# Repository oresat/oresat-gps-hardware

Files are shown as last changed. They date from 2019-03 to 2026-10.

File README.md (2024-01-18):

# oresat-gps-hardware 

## Overview

This is the repo for our OreSat GPS Card. For software, see the [oresat-gps-software](https://github.com/oresat/oresat-gps-software) repo.

The card has two GPS receivers on it:

* A [**SkyTraq Orion-B16** GNSS module](https://navspark.mybigcommerce.com/12mm-x-16mm-gnss-receiver-module-for-leo-applications/), a GNSS receiver module meant for university CubeSat use.
* An [Analog Devices MAX2771 SDR GNSS receiver IC](https://www.analog.com/en/products/max2771.html) that is read by the [Octavo OSD335x-SM processor's](https://octavosystems.com/octavo_products/osd335x-sm/) PRU and then parsed using the [GNSS-SDR project](https://gnss-sdr.org/) software.

## Status

TRL 6-7 ish. Flown, but not yet demonstrated to work in space.

* v1.1: Assembled, electrical and software test out, Orion not yet locked and demonstrated to work. MAX not yet tested.
* v1.0: Works: SkyTraq confirmed locked on ground. SDR datastream captured, and processed, but this software seems to be lost to the sands of time? Flown on OreSat0 but never turned on due to comms issues with OreSat0.

## License

All materials in this repo are copyright Portland State Aerospace Society and are licensed under the CERN Open Hardware Licence Version 2 -
Strongly Reciprocal (CERN-OHL-S v2), or any later version. A copy of the license is located in [here](LICENSE.md).

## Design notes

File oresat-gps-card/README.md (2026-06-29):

---
title: "**OreSat GPS Card**"
subtitle: |
  **Fabrication and Assembly Information**\
  For build TIME-STAMP
fontsize: 10pt
geometry:
  - margin=0.5in
toc: true
toc-depth: 2
colorlinks: true
urlcolor: blue
---

\newpage

# About this Board

## Board Description

The OreSat GPS Card provides two GPS receivers for the OreSat bus:

1. The SkyTraq Orion B16 which is a COTS GPS receiver capable of lock while in orbit.
2. The MAX2769 SDR GPS receiver. This hardware is for a future SDR capability we'd
like to have, and might one day replace the much more expensive COTS receiver.

## Documentation Links

- GPS hardware Git repository: <https://github.com/oresat/oresat-gps-hardware>
- GPS software Git reposity: <https://github.com/oresat/oresat-gps-software>
- **TODO:** GPS Design Notes + Design Review Notes

## Documentation Files

| Filename | Notes |
| --- | --- |
| README.pdf | This README file |
| PROJECT-NAME-outline.dxf | Board outline (with holes) in DXF format |
| PROJECT-NAME-pcba.step | 3D model of PCBA (with components) |
| PROJECT-NAME-render-bot.jpg | Render of the top of the 3D model |
| PROJECT-NAME-render-bot.jpg | Render of the bottom of the 3D model |
| PROJECT-NAME-schematic.pdf | PDF of board schematics |

## Contact Information

- Website: <https://www.oresat.org/>
- Email: <oresat@pdx.edu>
- Instagram: @pdxaerospace

## Board Renders

Render of the top of the 3D model
Render of the bottom of the 3D model

\newpage

# Printed Circuit Board (PCB) Fabrication Information

## Board Info

- 4 layer board
- Bounding box is 99.8 x 94.6 mm (3.93 x 3.72 in)
- Board thickness is 1.59 mm (0.063 inch)
- **Important:** See Materials and Stack Up sections below

## Board Requirements

- Design Rules
    - Minimum Trace / Space design rules
       - Outer layers: 0.127 mm (5.0 mil) / 0.127 mm (5.0 mil)
       - Inner layers: 0.127 mm (5.0 mil) / 0.127 mm (5.0 mil)
    - Outer dimension router tolerance: +/- 0.254 mm (10.0 mil)
    - Hole placement tolerance: +/- 0.075 mm (3.0 mil)
    - Inner tab routed slot tolerance: +/- 0.254 mm (10.0 mil)
- Drills
   - Drill Positional Tolerance: 0.051 mm (2.0 mil)
   - Drill Size tolerance: +/- 0.064 mm (2.5 mil)
- Plated/Un-plated holes
  - There are 6 un-plated (NPT) holes
  - There are 1477 plated through (PTH) holes
  - PTH minimum diameter: 0.254 mm (10 mil)
  - PTH minimum annulus: 0.102 mm (4 mil) radius
- Outline/Routing
  - Requires a 1.0 mm or smaller diameter routing bit
- Slots
  - There are no slots.
- Cutouts
  - There are no cutouts
- There are 3 fiducials on the top layer.
- Panel tabs ("mouse bites")
   - Card edges must be smooth; no mouse bites or other intrusions into the card outline.
   - If external mouse bites are required, minimize and customer will remove by hand before assembly.
- If not otherwise specified, build to IPC 6012 Class 2 or better.

## Materials

- Controlled impedance
   - The stackup is critical for the performance of high speed signals on this board.
   - As long as the stackup is controlled, the board is not considered controlled impedance.
- Isola FR408HR or material with equivalent Dk.
- Board Surface treatment should be ENIG, althogh immersion Silver is acceptable.
- White silkscreen on top and bottom surface
- Taiyo PSR-4000 or equivalent soldermask on top and bottom, no requirements for color.

## Stack Up

| Layer | Thickness | Notes |
|---|---|---|
| Top Copper | 0.043 mm /  1.7 mil |  Layer 1 foil, 1 oz Cu after plating |
| prepreg | 0.200 mm /  7.9 mil |  Prepreg - Isola FR408HR 2113 |
| Layer 2 | 0.018 mm /  0.7 mil |  Layer 2 foil, 0.5 oz Cu |
| Core | 0.991 mm / 39 mil |  Core Isola FR408HR |
| Layer 3 | 0.018 mm /  0.7 mil |  Layer 3 foil, 0.5 oz Cu |
| prepreg | 0.200 mm /  7.9 mil |  Prepreg - Isola FR408HR 2113 |
| Bottom Copper | 0.043 mm /  1.7 mil |  Layer 4 foil, 1 oz copper after plating |
| **Total Stackup** | **1.588 mm / 62.5 mil** | |

## Array / Panel Information

- Coordinate with Contract Manufacturer (CM) for optimal size of this panel.
- If no feedback from CM, then produce single boards (no panel).

## Fabrication Files

### IPC-2581 File

| Filename | Notes |
| --- | --- |
| PROJECT-NAME-ipc2581.xml | IPC-2581 board information file |

### Legacy PCB Files

| Filename | Notes |
| ---| --- |
| PROJECT-NAME-Edge_Cuts.gbr | RS274X file for the dimension (outline) layer |
| PROJECT-NAME-F_Silkscreen.gbr | RS274X file for the top silkscreen |
| PROJECT-NAME-F_Mask.gbr | RS274X file for the top soldermask |
| PROJECT-NAME-F_Cu.gbr | RS274X file for the top copper layer |
| PROJECT-NAME-In1_Cu.gbr | RS274X file for the layer 2 copper |
| PROJECT-NAME-In2_Cu.gbr | RS274X file for the layer 3 copper |
| PROJECT-NAME-B_Cu.gbr | RS274X file for the bottom copper layer |
| PROJECT-NAME-B_Mask.gbr | RS274X file for the bottom soldermask |
| PROJECT-NAME-B_Silkscreen.gbr | RS274X file for the bottom silkscreen |
| PROJECT-NAME-NPTH.drl | Excellon file for non-plated through holes |
| PROJECT-NAME-PTH.drl | Excellon file for plated through holes | 

\newpage

# Printed Circuit Board Assembly (PCBA) Information

## Assembly Info

- All components are on the top side of the board.
- This PCBA is mostly surface mount (SMT) with a few (THT) components.

## Assembly Requirements

- Assemble to IPC Class 2 or better
- Bake components that are not moisture sealed to appropriate levels as required.
- Solder paste MUST be leaded.
- Aqueous flux and wash strongly preferred.
   - Clean to NASA Standard "Visibly Clean (VC)": No particles or residues are visible to the naked eye.
- No conformal coating.
- Ship in antistatic protective bag

## Component Specific Assembly Information

- SMPM connectors (CM1) should be hand-added (there is no solder paste for their footprints) according to the OreSat SMPM SOP.
- U23 is extremely expensive ($400 ea).

## Assembly Files

### IPC-2581 File

| Filename | Notes |
| --- | --- |
| PROJECT-NAME-ipc2581.xml | IPC-2581 board information file |

### Bill of Materials (BOM)

| Filename | Description |
| --- | --- |
| PROJECT-NAME-bom.csv | BOM in Comma Separated Variable format |

### Solder Paste Stencils

| Filename | Notes |
| --- | --- |
| PROJECT-NAME-B_Paste.gbr | RS274X file for top/front solder paste stencil |
| PROJECT-NAME-F_Paste.gbr | RS274X file for bottom/back solder paste stencil |

### Mounting/Placement Location

| Filename | Description |
| --- | --- |
| PROJECT-NAME-3u.pos | Pick and place locations for components |

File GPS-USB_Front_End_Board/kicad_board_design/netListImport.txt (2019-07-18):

Info: Reading netlist file "/home/hugh/projects/KiCad/usb_gps/usb_gps_fixed.net".

Info: Using references to match components and footprints.

Info: Checking netlist component footprint "C1:/5B1BC185/5B1E7FF3:Capacitors_SMD:C_0603_HandSoldering".

Changing component "C1:/5B1BC185/5B1E7FF3" pin "1" net name from "/USB_FT2232/VCC3V3" to "/MAX_2769/VCC3V3".

Info: Checking netlist component footprint "C2:/5B1BC185/5B1E80A3:Capacitors_SMD:C_0402".

Changing component "C2:/5B1BC185/5B1E80A3" pin "1" net name from "/USB_FT2232/VCC3V3" to "/MAX_2769/VCC3V3".

Info: Checking netlist component footprint "C3:/5B1BC185/5B1C4E8F:Capacitors_SMD:C_0805_HandSoldering".

Info: Checking netlist component footprint "C4:/5B1BC185/5B1E3C76:Capacitors_SMD:C_0805_HandSoldering".

Info: Checking netlist component footprint "C5:/5B1BC185/5B1C4C39:Capacitors_SMD:C_0805_HandSoldering".

Info: Checking netlist component footprint "C6:/5B1BC185/5B1C1DAE:Capacitors_SMD:C_0402".

Info: Checking netlist component footprint "C7:/5B1BC185/5B5B2330:Capacitors_SMD:C_0805_HandSoldering".

Info: Changing component path "C7:/5B1BC185/5B1C1E88" to "/5B1BC185/5B5B2330".

Changing component "C7:/5B1BC185/5B1C1E88" pin "1" net name from "/USB_FT2232/VCC3V3" to "/MAX_2769/VCC3V3".

Info: Checking netlist component footprint "C8:/5B1BC185/5B1BDC6D:Capacitors_SMD:C_0402".

Info: Checking netlist component footprint "C9:/5B1BC185/5B5D53D2:Capacitors_SMD:C_0402".

xReplacing component "C9:/5B22247E/5B231F00" footprint "Capacitors_SMD:C_0805_HandSoldering" with "Capacitors_SMD:C_0402".

xChanging component "C9:/5B22247E/5B231F00" value from "NC" to "100 nF".

Info: Changing component path "C9:/5B22247E/5B231F00" to "/5B1BC185/5B5D53D2".

Changing component "C9:/5B22247E/5B231F00" pin "1" net name from "Net-(C12-Pad1)" to "Net-(C9-Pad1)".

Info: Checking netlist component footprint "C10:/5B1BC185/5B5D5EEA:Capacitors_SMD:C_0402".

xxx0603xReplacing component "C10:/5B22247E/5B231FC9" footprint "Capacitors_SMD:C_0805_HandSoldering" with "Capacitors_SMD:C_0402".

Changing component "C10:/5B22247E/5B231FC9" value from "NC" to "10uF".

Info: Changing component path "C10:/5B22247E/5B231FC9" to "/5B1BC185/5B5D5EEA".

Changing component "C10:/5B22247E/5B231FC9" pin "1" net name from "/MAX_2769/VCC3V" to "/MAX_2769/+5V".

Info: Checking netlist component footprint "C11:/5B22247E/5B222A24:Capacitors_SMD:C_0402".

Info: Checking netlist component footprint "C12:/5B22247E/5B5E057D:Capacitors_SMD:C_0603_HandSoldering".

xChanging component "C12:/5B22247E/5B23227F" value from "33pF" to "1uF".

Info: Changing component path "C12:/5B22247E/5B23227F" to "/5B22247E/5B5E057D".

Changing component "C12:/5B22247E/5B23227F" pin "1" net name from "Net-(C12-Pad1)" to "/MAX_2769/+5V".

Changing component "C12:/5B22247E/5B23227F" pin "2" net name from "Net-(C12-Pad2)" to "GND".

Info: Checking netlist component footprint "C13:/5B22247E/5B222C2B:Capacitors_SMD:C_0402".

Changing component "C13:/5B22247E/5B222C2B" pin "1" net name from "/MAX_2769/VCC3V" to "/MAX_2769/VCCA".

Info: Checking netlist component footprint "C14:/5B22247E/5B222D43:Capacitors_SMD:C_0402".

Changing component "C14:/5B22247E/5B222D43" pin "1" net name from "/MAX_2769/VCC3V" to "/MAX_2769/VCCA".

Info: Checking netlist component footprint "C15:/5B22247E/5B222E30:Capacitors_SMD:C_0402".

Changing component "C15:/5B22247E/5B222E30" pin "1" net name from "/MAX_2769/VCC3V" to "/MAX_2769/VCCD".

Info: Checking netlist component footprint "C16:/5B22247E/5B222E72:Capacitors_SMD:C_0402".

Changing component "C16:/5B22247E/5B222E72" pin "1" net name from "/MAX_2769/VCC3V" to "/MAX_2769/VCCA".

Info: Checking netlist component footprint "C17:/5B22247E/5B5DF4D0:Capacitors_SMD:C_0402".

xxReplacing component "C17:/5B22247E/5B2324F5" footprint "Capacitors_SMD:C_0805_HandSoldering" with "Capacitors_SMD:C_0402".

xxChanging component "C17:/5B22247E/5B2324F5" value from "100pF" to "10nF".

Info: Changing component path "C17:/5B22247E/5B2324F5" to "/5B22247E/5B5DF4D0".

Changing component "C17:/5B22247E/5B2324F5" pin "1" net name from "Net-(C12-Pad2)" to "/MAX_2769/VCCA".

Info: Checking netlist component footprint "C18:/5B22247E/5B2B7313:Capacitors_SMD:C_0603_HandSoldering".

Info: Checking netlist component footprint "C19:/5B22247E/5B222EB0:Capacitors_SMD:C_0805_HandSoldering".

Changing component "C19:/5B22247E/5B222EB0" pin "1" net name from "/MAX_2769/VCC3V" to "/MAX_2769/VCCA".

Info: Checking netlist component footprint "C20:/5B22247E/5B22294B:Capacitors_SMD:C_0603_HandSoldering".

Info: Checking netlist component footprint "C21:/5B22247E/5B222F1B:Capacitors_SMD:C_0402".

Changing component "C21:/5B22247E/5B222F1B" pin "1" net name from "/MAX_2769/VCC3V" to "/MAX_2769/VCCA".

Info: Checking netlist component footprint "C22:/5B22247E/5B222F73:Capacitors_SMD:C_0402".

Changing component "C22:/5B22247E/5B222F73" pin "1" net name from "/MAX_2769/VCC3V" to "/MAX_2769/VCCA".

Info: Checking netlist component footprint "C23:/5B22247E/5B2B743B:Capacitors_SMD:C_0402".

Changing component "C23:/5B22247E/5B2B743B" pin "1" net name from "Net-(C23-Pad1)" to "/MAX_2769/VCCA".

Info: Checking netlist component footprint "C24:/5B22247E/5B5E05AD:Capacitors_SMD:C_0402".

xxReplacing component "C24:/5B22247E/5B2B7595" footprint "Capacitors_SMD:C_0805_HandSoldering" with "Capacitors_SMD:C_0402".

xxChanging component "C24:/5B22247E/5B2B7595" value from "10uF" to "10nF".

Info: Changing component path "C24:/5B22247E/5B2B7595" to "/5B22247E/5B5E05AD".

Changing component "C24:/5B22247E/5B2B7595" pin "1" net name from "/MAX_2769/VCC3V" to "/MAX_2769/VCCD".

Changing component "C24:/5B22247E/5B2B7595" pin "2" net name from "GND" to "Net-(C24-Pad2)".

Info: Checking netlist component footprint "C25:/5B22247E/5B224008:Capacitors_SMD:C_0805_HandSoldering".

Info: Checking netlist component footprint "C26:/5B22247E/5B223F00:Capacitors_SMD:C_0402".

Changing component "C26:/5B22247E/5B223F00" pin "2" net name from "/MAX_2769/CLKOUT" to "Net-(C26-Pad2)".

Info: Checking netlist component footprint "C27:/5B22247E/5B224134:Capacitors_SMD:C_0402".

Info: Checking netlist component footprint "C28:/5B22247E/5B223AF8:Capacitors_SMD:C_0402".

Info: Checking netlist component footprint "C29:/5B22247E/5B23CB0F:Capacitors_SMD:C_0805_HandSoldering".

Info: Checking netlist component footprint "C30:/5B22247E/5B23B453:Capacitors_SMD:C_0402".

Info: Checking netlist component footprint "C31:/5B22247E/5B23B2CD:Capacitors_SMD:C_0805_HandSoldering".

Info: Checking netlist component footprint "C32:/5B22247E/5B23ACDD:Capacitors_SMD:C_0805_HandSoldering".

Info: Checking netlist component footprint "C33:/5B1BC185/5B46ED5F:Capacitors_SMD:C_0402".

Info: Checking netlist component footprint "C34:/5B1BC185/5B46F2DD:Capacitors_SMD:C_0805_HandSoldering".

Changing component "C34:/5B1BC185/5B46F2DD" pin "1" net name from "/USB_FT2232/VCC3V3" to "/MAX_2769/VCC3V3".

Info: Checking netlist component footprint "C35:/5B1BC185/5B46F3B3:Capacitors_SMD:C_0402".

Changing component "C35:/5B1BC185/5B46F3B3" pin "1" net name from "/USB_FT2232/VCC3V3" to "/MAX_2769/VCC3V3".

Info: Checking netlist component footprint "C36:/5B22247E/5B5E0583:Capacitors_SMD:C_0402".

xxAdding new component "C36:/5B22247E/5B5E0583" footprint "Capacitors_SMD:C_0402".

Info: Checking netlist component footprint "C37:/5B22247E/5B5EA13E:Capacitors_SMD:C_0805_HandSoldering".

xxx0402xAdding new component "C37:/5B22247E/5B5EA13E" footprint "Capacitors_SMD:C_0805_HandSoldering".

Info: Checking netlist component footprint "C38:/5B22247E/5B5EE1F7:Capacitors_SMD:C_0402".

Adding new component "C38:/5B22247E/5B5EE1F7" footprint "Capacitors_SMD:C_0402".

Info: Checking netlist component footprint "D1:/5B1BC185/5B1BCC5C:digikey-footprints:SOT23-6L".

Info: Checking netlist component footprint "FB1:/5B1BC185/5B1C3474:digikey-footprints:0603".

Changing component "FB1:/5B1BC185/5B1C3474" pin "2" net name from "Net-(F1-Pad1)" to "/USB_FT2232/VBUS".

Info: Checking netlist component footprint "J1:/5B1BC185/5B1BCC4C:digikey-footprints:USB_Micro_B_Female_10118192".

Changing component "J1:/5B1BC185/5B1BCC4C" pin "6" net name from "Net-(J1-Pad6)" to "Net-(C9-Pad1)".

Changing component "J1:/5B1BC185/5B1BCC4C" pin "6" net name from "Net-(J1-Pad6)" to "Net-(C9-Pad1)".

Changing component "J1:/5B1BC185/5B1BCC4C" pin "6" net name from "Net-(J1-Pad6)" to "Net-(C9-Pad1)".

Changing component "J1:/5B1BC185/5B1BCC4C" pin "6" net name from "Net-(J1-Pad6)" to "Net-(C9-Pad1)".

Changing component "J1:/5B1BC185/5B1BCC4C" pin "6" net name from "Net-(J1-Pad6)" to "Net-(C9-Pad1)".

Changing component "J1:/5B1BC185/5B1BCC4C" pin "6" net name from "Net-(J1-Pad6)" to "Net-(C9-Pad1)".

Info: Checking netlist component footprint "J3:/5B22247E/5B239872:digikey-footprints:RF_SMA_Receptical_Vertical_CONSMA001-SMD-G".

Info: Checking netlist component footprint "L4:/5B22247E/5B23AAAA:Capacitors_SMD:C_0402".

Info: Checking netlist component footprint "P1:/5B265B59:Pin_Headers:Pin_Header_Straight_2x12".

Changing component "P1:/5B265B59" pin "1" net name from "GND" to "/MAX_2769/+5V".

Changing component "P1:/5B265B59" pin "4" net name from "/MAX_2769/+5V" to "GND".

Info: Checking netlist component footprint "R1:/5B1BC185/5B1BF604:Resistors_SMD:R_0805_HandSoldering".

Changing component "R1:/5B1BC185/5B1BF604" pin "1" net name from "/USB_FT2232/VCC3V3" to "/MAX_2769/VCC3V3".

Info: Checking netlist component footprint "R2:/5B1BC185/5B1E5BF4:Resistors_SMD:R_0603_HandSoldering".

Info: Checking netlist component footprint "R3:/5B1BC185/5B1BF56C:Resistors_SMD:R_0805_HandSoldering".

Changing component "R3:/5B1BC185/5B1BF56C" pin "1" net name from "/USB_FT2232/VCC3V3" to "/MAX_2769/VCC3V3".

Info: Checking netlist component footprint "R4:/5B1BC185/5B1E52EE:Resistors_SMD:R_0805_HandSoldering".

Changing component "R4:/5B1BC185/5B1E52EE" pin "1" net name from "/USB_FT2232/VCC3V3" to "/MAX_2769/VCC3V3".

Info: Checking netlist component footprint "R5:/5B1BC185/5B1BF3F3:Resistors_SMD:R_0805_HandSoldering".

Changing component "R5:/5B1BC185/5B1BF3F3" pin "1" net name from "/USB_FT2232/VCC3V3" to "/MAX_2769/VCC3V3".

Info: Checking netlist component footprint "R6:/5B1BC185/5B1BF4B5:Resistors_SMD:R_0603_HandSoldering".

Info: Checking netlist component footprint "R7:/5B22247E/5B2A9337:Resistors_SMD:R_0805_HandSoldering".

Info: Checking netlist component footprint "R8:/5B22247E/5B2B2C1D:Resistors_SMD:R_0805_HandSoldering".

Info: Checking netlist component footprint "R9:/5B22247E/5B2B2B5F:Resistors_SMD:R_0805_HandSoldering".

Info: Checking netlist component footprint "R10:/5B22247E/5B2B0223:Resistors_SMD:R_0805_HandSoldering".

Info: Checking netlist component footprint "R11:/5B22247E/5B236218:Resistors_SMD:R_0805_HandSoldering".

Info: Checking netlist component footprint "R12:/5B22247E/5B236373:Resistors_SMD:R_0805_HandSoldering".

Info: Checking netlist component footprint "R13:/5B22247E/5B22418D:Resistors_SMD:R_0603_HandSoldering".

Info: Checking netlist component footprint "R14:/5B22247E/5B2A0332:Resistors_SMD:R_0805_HandSoldering".

Info: Checking netlist component footprint "R15:/5B22247E/5B2975D0:Resistors_SMD:R_0805_HandSoldering".

Info: Checking netlist component footprint "R16:/5B22247E/5B298102:Resistors_SMD:R_0805_HandSoldering".

Info: Checking netlist component footprint "R17:/5B22247E/5B2981CA:Resistors_SMD:R_0805_HandSoldering".

Info: Checking netlist component footprint "R18:/5B22247E/5B298297:Resistors_SMD:R_0805_HandSoldering".

Info: Checking netlist component footprint "R19:/5B22247E/5B5EB863:Resistors_SMD:R_0603_HandSoldering".

xxAdding new component "R19:/5B22247E/5B5EB863" footprint "Resistors_SMD:R_0603_HandSoldering".

Info: Checking netlist component footprint "R20:/5B22247E/5B5E9ED0:Resistors_SMD:R_0603_HandSoldering".

xxAdding new component "R20:/5B22247E/5B5E9ED0" footprint "Resistors_SMD:R_0603_HandSoldering".

Info: Checking netlist component footprint "TP1:/5B1BC185/5B2D3A96:Measurement_Points:Test_Point".

Info: Checking netlist component footprint "TP2:/5B1BC185/5B2D441B:Measurement_Points:Test_Point".

Info: Checking netlist component footprint "TP3:/5B1BC185/5B2D413A:Measurement_Points:Test_Point".

Info: Checking netlist component footprint "TP4:/5B1BC185/5B2D4359:Measurement_Points:Test_Point".

Info: Checking netlist component footprint "TP5:/5B1BC185/5B2D41D2:Measurement_Points:Test_Point".

Changing component "TP5:/5B1BC185/5B2D41D2" pin "1" net name from "/USB_FT2232/VCC3V3" to "/MAX_2769/VCC3V3".

Changing component "TP5:/5B1BC185/5B2D41D2" pin "1" net name from "/USB_FT2232/VCC3V3" to "/MAX_2769/VCC3V3".

Info: Checking netlist component footprint "TP6:/5B1BC185/5B2D4288:Measurement_Points:Test_Point".

Info: Checking netlist component footprint "U1:/5B1BC185/5B1BDDB3:mem:SOIC127P600X175-8N".

Changing component "U1:/5B1BC185/5B1BDDB3" pin "8" net name from "/USB_FT2232/VCC3V3" to "/MAX_2769/VCC3V3".

Info: Checking netlist component footprint "U2:/5B1BC185/5B1BCE94:digikey-footprints:LQFP-64_10x10mm".

Changing component "U2:/5B1BC185/5B1BCE94" pin "4" net name from "/USB_FT2232/VCC3V3" to "/MAX_2769/VCC3V3".

Changing component "U2:/5B1BC185/5B1BCE94" pin "9" net name from "/USB_FT2232/VCC3V3" to "/MAX_2769/VCC3V3".

Changing component "U2:/5B1BC185/5B1BCE94" pin "20" net name from "/USB_FT2232/VCC3V3" to "/MAX_2769/VCC3V3".

Changing component "U2:/5B1BC185/5B1BCE94" pin "31" net name from "/USB_FT2232/VCC3V3" to "/MAX_2769/VCC3V3".

Changing component "U2:/5B1BC185/5B1BCE94" pin "42" net name from "/USB_FT2232/VCC3V3" to "/MAX_2769/VCC3V3".

Changing component "U2:/5B1BC185/5B1BCE94" pin "50" net name from "/USB_FT2232/VCC3V3" to "/MAX_2769/VCC3V3".

Changing component "U2:/5B1BC185/5B1BCE94" pin "56" net name from "/USB_FT2232/VCC3V3" to "/MAX_2769/VCC3V3".

Info: Checking netlist component footprint "U3:/5B1BC185/5B1BCEA4:digikey-footprints:SOIC-8_W3.9mm".

Changing component "U3:/5B1BC185/5B1BCEA4" pin "1" net name from "Net-(FB2-Pad2)" to "/MAX_2769/VCC3V3".

Info: Checking netlist component footprint "U4:/5B22247E/5B5DE469:rf:21-0076E".

xxReplacing component "U4:/5B22247E/5B3352E5" footprint "rf:Sawtek_855969" with "rf:21-0076E".

xxChanging component "U4:/5B22247E/5B3352E5" value from "SAWTEK-855969" to "MAX8510".

Info: Changing component path "U4:/5B22247E/5B3352E5" to "/5B22247E/5B5DE469".

Changing component "U4:/5B22247E/5B3352E5" pin "1" net name from "GND" to "/MAX_2769/+5V".

Changing component "U4:/5B22247E/5B3352E5" pin "2" net name from "Net-(C12-Pad2)" to "GND".

Changing component "U4:/5B22247E/5B3352E5" pin "3" net name from "GND" to "/MAX_2769/+5V".

Clearing component "U4:/5B22247E/5B3352E5" pin "6" net name.

Changing component "U4:/5B22247E/5B3352E5" pin "5" net name from "Net-(C17-Pad2)" to "/MAX_2769/VCCA".

Changing component "U4:/5B22247E/5B3352E5" pin "4" net name from "GND" to "Net-(C17-Pad2)".

Info: Checking netlist component footprint "U5:/5B22247E/5B5E05A7:rf:21-0076E".

xxReplacing component "U5:/5B22247E/5B2B60CE" footprint "TO_SOT_Packages_SMD:SOT-23-5" with "rf:21-0076E".

xxChanging component "U5:/5B22247E/5B2B60CE" value from "AP131-30" to "MAX8510".

Info: Changing component path "U5:/5B22247E/5B2B60CE" to "/5B22247E/5B5E05A7".

Changing component "U5:/5B22247E/5B2B60CE" pin "4" net name from "Net-(C23-Pad1)" to "Net-(C24-Pad2)".

Changing component "U5:/5B22247E/5B2B60CE" pin "5" net name from "/MAX_2769/VCC3V" to "/MAX_2769/VCCD".

Info: Checking netlist component footprint "U6:/5B22247E/5B22277F:rf:TQFP_29_EP_MAX2769".

Changing component "U6:/5B22247E/5B22277F" pin "14" net name from "/MAX_2769/VCC3V" to "/MAX_2769/VCCA".

Changing component "U6:/5B22247E/5B22277F" pin "13" net name from "/MAX_2769/VCC3V" to "/MAX_2769/VCCA".

Changing component "U6:/5B22247E/5B22277F" pin "11" net name from "/MAX_2769/VCC3V" to "/MAX_2769/VCCA".

Changing component "U6:/5B22247E/5B22277F" pin "23" net name from "/MAX_2769/VCC3V" to "/MAX_2769/VCCA".

Changing component "U6:/5B22247E/5B22277F" pin "27" net name from "/MAX_2769/LNA1" to "Net-(U6-Pad27)".

Changing component "U6:/5B22247E/5B22277F" pin "19" net name from "/MAX_2769/VCC3V" to "/MAX_2769/VCCD".

Changing component "U6:/5B22247E/5B22277F" pin "4" net name from "/MAX_2769/VCC3V" to "/MAX_2769/VCCA".

Info: Checking netlist component footprint "U7:/5B22247E/5B23DBF7:rf:Sawtek_855969".

Info: Checking netlist component footprint "U8:/5B22247E/5B5E9B54:rf:TSOT-23_S6".

xxAdding new component "U8:/5B22247E/5B5E9B54" footprint "rf:TSOT-23_S6".

Info: Checking netlist component footprint "W1:/5B1BC185/5B5D8295:Measurement_Points:Test_Point".

Adding new component "W1:/5B1BC185/5B5D8295" footprint "Measurement_Points:Test_Point".

Info: Checking netlist component footprint "W2:/5B1BC185/5B5D8D79:Measurement_Points:Test_Point".

Adding new component "W2:/5B1BC185/5B5D8D79" footprint "Measurement_Points:Test_Point".

Info: Checking netlist component footprint "W3:/5B1BC185/5B5D8F1F:Measurement_Points:Test_Point".

Adding new component "W3:/5B1BC185/5B5D8F1F" footprint "Measurement_Points:Test_Point".

Info: Checking netlist component footprint "W4:/5B1BC185/5B5D65B4:Measurement_Points:Test_Point".

Adding new component "W4:/5B1BC185/5B5D65B4" footprint "Measurement_Points:Test_Point".

Info: Checking netlist component footprint "W5:/5B1BC185/5B5D6358:Measurement_Points:Test_Point".

Adding new component "W5:/5B1BC185/5B5D6358" footprint "Measurement_Points:Test_Point".

Info: Checking netlist component footprint "W6:/5B1BC185/5B5D7E96:Measurement_Points:Test_Point".

Adding new component "W6:/5B1BC185/5B5D7E96" footprint "Measurement_Points:Test_Point".

Info: Checking netlist component footprint "X1:/5B22247E/5B436041:oscillator:CTS_405_xtal".

Info: Checking netlist component footprint "Y1:/5B1BC185/5B1C4A48:oscillator:CTS_405_xtal".

Removing unused component "REF2:".

Removing unused component "REF3:".

Removing unused component "REF1:".

Removing unused component "F1:/5B1BC185/5B220C23".

Removing unused component "FB2:/5B1BC185/5B1DE4B1".

Removing unused component "J2:/5B22247E/5B2225E9".

Removing unused component "L1:/5B22247E/5B231E73".

Removing unused component "L2:/5B22247E/5B2323B6".

Removing unused component "L3:/5B22247E/5B232A62".

Removing unused component "REF4:".

Removing unused component "G***:".

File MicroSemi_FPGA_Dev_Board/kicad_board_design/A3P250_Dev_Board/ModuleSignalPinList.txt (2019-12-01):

(WEST)
+5V
GND
P98
P2
P4
P5
P6
P7
P8
P10
P11
P13
P15
P16
VCCIO
P19
P20
P21
P22
P23

(EAST)
P73
P72
P71
P70
P69
P66
P65
P64
P63
P62
P61
P60
P59
P58
P57
VJTAG
TRST
TDO
VPUMP
TMS

(NORTH)
P97
P96
P95
P94
P93
P92
P91
P90
P87
P86
P85
P84
P83
P82
P81
P80
P79
P78
P77
P76

(SOUTH)
P26
P27
P28
P29
P30
P31
P32
P33
P34
P35
P36
P39
P40
P41
P42
P43
P44
P45
TCK
TDI

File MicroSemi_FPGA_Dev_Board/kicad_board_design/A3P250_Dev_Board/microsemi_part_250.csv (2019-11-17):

A3P250 | U | microsemi:VQ100 |  | https://www.microsemi.com/document-portal/doc_download/130704-ds0097-proasic3-flash-family-fpgas-datasheet
Unit | Side | Pin | Name | Type | Style | Hidden
io_3 | left | 2 | GAA2/IO118UDB3 | io
io_3 | left | 4 | GAB2/IO117UDB3 | io
io_3 | left | 6 | GAC2/IO116UDB3 | io
io_3 | left | 10 | GFB1/IO109PDB3 | io
io_3 | left | 11 | GFB0/IO109NDB3 | io
io_3 | left | 13 | GFA0/IO108NPB3 | io
io_3 | left | 15 | GFA1/IO108PPB3 | io
io_3 | left | 16 | GFA2/IO107PSB3 | io
io_3 | left | 19 | GFC2/IO105PSB3 | io
io_3 | left | 20 | GEC1/IO100PDB3 | io
io_3 | left | 21 | GEC0/IO100NDB3 | io
io_3 | left | 22 | GEA1/IO98PDB3 | io
io_3 | left | 23 | GEA0/IO98NDB3 | io
io_2 | bottom | 26 | GEA2/IO97RSB2 | io
io_2 | bottom | 27 | GEB2/IO96RSB2 | io
io_2 | bottom | 28 | GEC2/IO95RSB2 | io
io_2 | bottom | 43 | GDC2/IO63RSB2 | io
io_2 | bottom | 44 | GDB2/IO62RSB2 | io
io_2 | bottom | 45 | GDA2/IO61RSB2 | io
io_1 | right | 57 | GDA1/IO60USB1 | io
io_1 | right | 58 | GDC0/IO58VDB1 | io
io_1 | right | 59 | GDC1/IO58UDB1 | io
io_1 | right | 61 | GCB2/IO52PDB1 | io
io_1 | right | 62 | GCA1/IO50PDB1 | io
io_1 | right | 63 | GCA0/IO50NDB1 | io
io_1 | right | 64 | GCC0/IO48NDB1 | io
io_1 | right | 65 | GCC1/IO48PDB1 | io
io_1 | right | 70 | GBC2/IO43PDB1 | io
io_1 | right | 71 | GBB2/IO42PSB1 | io
io_1 | right | 73 | GBA2/IO41PDB1 | io
io_0 | top | 76 | GBA1/IO40RSB0 | io
io_0 | top | 77 | GBA0/IO39RSB0 | io
io_0 | top | 78 | GBB1/IO38RSB0 | io
io_0 | top | 79 | GBB0/IO37RSB0 | io
io_0 | top | 80 | GBC1/IO36RSB0 | io
io_0 | top | 81 | GBC0/IO35RSB0 | io
io_0 | top | 93 | GAC1/IO05RSB0 | io
io_0 | top | 94 | GAC0/IO04RSB0 | io
io_0 | top | 95 | GAB1/IO03RSB0 | io
io_0 | top | 96 | GAB0/IO02RSB0 | io
io_0 | top | 97 | GAA1/IO01RSB0 | io
io_0 | top | 98 | GAA0/IO00RSB0 | io
power | left | 1 | GND | pwr_in
power | left | 9 | GND | pwr_in
power | left | 12 | VCOMPLF | pwr_in
power | left | 14 | VCCPLF | pwr_in
power | left | 17 | VCC | pwr_in
io_3 | left | 18 | VCCIB3 | pwr_in
io_3 | left | 24 | VMV3 | pwr_in
power | left | 25 | GNDQ | io
power | bottom | 37 | VCC | pwr_in
power | bottom | 38 | GND | pwr_in
io_2 | bottom | 39 | VCCIB2 | pwr_in
power | bottom | 46 | GNDQ | pwr_in
prog | bottom | 47 | TCK | clk
prog | bottom | 48 | TDI | io
prog | bottom | 49 | TMS | io
io_2 | bottom | 50 | VMV2 | pwr_in
power | right | 51 | GND | pwr_in
prog | right | 52 | VPUMP | pwr_in
power | right | 53 | NC | nc
prog | right | 54 | TDO | io
prog | right | 55 | TRST | io
prog | right | 56 | VJTAG | pwr_in
io_1 | right | 66 | VCCIB1 | pwr_in
power | right | 67 | GND | pwr_in
power | right | 68 | VCC | pwr_in
io_1 | right | 74 | VMV1 | pwr_in
power | right | 75 | GNDQ | pwr_in
io_0 | top | 87 | VCCIB0 | pwr_in
power | top | 88 | GND | pwr_in
power | top | 89 | VCC | pwr_in
power | top | 99 | GNDQ | pwr_in
io_0 | top | 100 | VMV0 | pwr_in
io_3 | left | 3 | IO118VDB3 | io
io_3 | left | 5 | IO117VDB3 | io
io_3 | left | 7 | IO116VDB3 | io
io_3 | left | 8 | IO112PSB3 | io
io_2 | bottom | 29 | IO93RSB2 | io
io_2 | bottom | 30 | IO92RSB2 | io
io_2 | bottom | 31 | IO91RSB2 | io
io_2 | bottom | 32 | IO90RSB2 | io
io_2 | bottom | 33 | IO88RSB2 | io
io_2 | bottom | 34 | IO86RSB2 | io
io_2 | bottom | 35 | IO85RSB2 | io
io_2 | bottom | 36 | IO84RSB2 | io
io_2 | bottom | 40 | IO77RSB2 | io
io_2 | bottom | 41 | IO74RSB2 | io
io_2 | bottom | 42 | IO71RSB2 | io
io_1 | right | 60 | IO52NDB1 | io
io_1 | right | 69 | IO43NDB1 | io
io_1 | right | 72 | IO41NDB1 | io
io_0 | top | 82 | IO29RSB0 | io
io_0 | top | 83 | IO27RSB0 | io
io_0 | top | 84 | IO25RSB0 | io
io_0 | top | 85 | IO23RSB0 | io
io_0 | top | 86 | IO21RSB0 | io
io_0 | top | 90 | IO15RSB0 | io
io_0 | top | 91 | IO13RSB0 | io
io_0 | top | 92 | IO11RSB0 | io

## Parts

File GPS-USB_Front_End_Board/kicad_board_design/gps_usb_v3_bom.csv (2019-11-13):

Refs | Value | Footprint | Quantity | MFR | MPN | SPR | SPN
C8;C6;C2;C35;C33;C9;C44;C45;C46;C47;C48;C40;C41;C38;C37;C11;C13;C14;C15;C16;C21;C22;C30 | .1uF | Capacitors_SMD:C_0402 | 23 | TDK | CGA2B1X7R1C104K050BC | Digikey | 445-5613-1-ND
C29 | 1.7pF | Capacitors_SMD:C_0402 | 1 | Murata | GJM1555C1H1R7WB01D | Digikey | 490-11201-1-ND
C32;C31;C19 | 100pF | Capacitors_SMD:C_0402 | 3 | Yageo | CC0402JRNPO9BN101 | Digikey | 311-1024-1-ND
C26;C24;C17 | 10nF | Capacitors_SMD:C_0402 | 3 | Murata | GRM155R71C103KA01D | Digikey | 490-1313-1-ND
C4;C34 | 3.3uF | Capacitors_SMD:C_0402 | 2 | TDK | C1005X5R0J335K050BC | Digikey | 445-5946-1-ND
L4 | 33nH | Capacitors_SMD:C_0402 | 1 | Bourns | CI100505-33NJ | Digikey | CI100505-33NJCT-ND
C42;C43 | 4.7uF | Capacitors_SMD:C_0402 | 2 | Taiyo Yuden | LMF105B7472KVHF | Digikey | 587-6564-1-ND
C27;C39;C28 | 470pF | Capacitors_SMD:C_0402 | 3 | AVX | 04025C471KAT2A | Digikey | 478-1097-1-ND
L1 | 5.6nH | Capacitors_SMD:C_0402 | 1 | Johansen Technology | L-07C5N6SV6T | Digikey | 712-1462-1-ND
C10 | 10uF | Capacitors_SMD:C_0603_HandSoldering | 1 | Samsung | CL10B106MQ8NRNC | Digikey | 1276-1948-1-ND
C1;C12;C18 | 1uF | Capacitors_SMD:C_0603_HandSoldering | 3 | Samsung | CL10B105KP8NNNC | Digikey | 1276-1946-1-ND
C20 | 3300pF | Capacitors_SMD:C_0603_HandSoldering | 1 | AVX | 06035C332KAT4A | Digikey | 478-10681-1-ND
C7 | 10uF | Capacitors_SMD:C_0805 | 1 | Samsung | CL21A106KPFNNNG | Digikey | 1276-6456-1-ND
C23;C36 | 1uF | Capacitors_SMD:C_0805 | 2 | Kemet | C0805C105K4RACTU | Digikey | 399-1284-1-ND
C25 | 27pF | Capacitors_SMD:C_0805_HandSoldering | 1 | AVX | 08055C270KAT2A | Digikey | 478-11394-1-ND
C3;C5 | 33pF | Capacitors_SMD:C_0805_HandSoldering | 2 | Kemet | C0805C330J5GACTU | Digikey | 399-1115-1-ND
P2 | CONN_01X03 | Connectors_Molex:Molex_KK-6410-03_03x2.54mm_Straight | 1 | Sullins | PREC003SAAN-RC | Digikey | S1012EC-03-ND
W8 | +BB | Measurement_Points:Measurement_Point_Round-TH_Small | 1 | - | - | - | -
W7 | -BB | Measurement_Points:Measurement_Point_Round-TH_Small | 1 | - | - | - | -
W2 | D0 | Measurement_Points:Measurement_Point_Round-TH_Small | 1 | - | - | - | -
W3 | D1 | Measurement_Points:Measurement_Point_Round-TH_Small | 1 | - | - | - | -
W6 | EECLK | Measurement_Points:Measurement_Point_Round-TH_Small | 1 | - | - | - | -
W1 | EECS | Measurement_Points:Measurement_Point_Round-TH_Small | 1 | - | - | - | -
W4 | PWREN | Measurement_Points:Measurement_Point_Round-TH_Small | 1 | - | - | - | -
W5 | SUSPEND | Measurement_Points:Measurement_Point_Round-TH_Small | 1 | - | - | - | -
TP3;TP5;TP6;TP4;TP2 | TEST | Measurement_Points:Measurement_Point_Round-TH_Small | 5 | - | - | - | -
TP1 | TEST | Measurement_Points:Test_Point | 1 | - | - | - | -
P1 | CONN_02X14 | Pin_Headers:Pin_Header_Straight_2x14 | 1 | Sullins | PPTC142LFBN-RC | Digikey | S7082-ND
R19 | 0 | Resistors_SMD:R_0603_HandSoldering | 1 | Vishay | CRCW06030000Z0EBC | Digikey | 541-4013-1-ND
R2 | 12.0K | Resistors_SMD:R_0603_HandSoldering | 1 | TE Connectivity | CPF0603B12KE1 | Digikey | A103037CT-ND
R13 | 20K | Resistors_SMD:R_0603_HandSoldering | 1 | Bourns | CRT0603-FZ-2002EST | Digikey | CRT0603-FZ-2002ESTCT-ND
R6 | 2K | Resistors_SMD:R_0603_HandSoldering | 1 | Yageo | AC0603FR-072KL | Digikey | YAG3590CT-ND
R20 | DNP | Resistors_SMD:R_0603_HandSoldering | 1 | Vishay | CRCW06030000Z0EBC | Digikey | 541-4013-1-ND
R15;R16;R17;R18;R14;R10;R9;R8 | 0 | Resistors_SMD:R_0805_HandSoldering | 8 | Vishay | CRCW06030000Z0EBC | Digikey | 541-4013-1-ND
R5;R3;R1;R4;R7 | 10K | Resistors_SMD:R_0805_HandSoldering | 5 | TE Connectivity | CRGH0805F10K | Digikey | A126417DKR-ND
R11 | 200 | digikey-footprints:0805 | 1 | Susumu | RR1220P-201-D | Digikey | RR12P200DCT-ND
D2 | LTST-C171KRKT | digikey-footprints:0805 | 1 | Lite-On | LTST-C171KRKT | Digikey | 160-1427-1-ND
U2 | FT2232HL-REEL | digikey-footprints:LQFP-64_10x10mm | 1 | FTDI | FT2232HL-REEL | Digikey | 768-1024-1-ND
U3 | L4931 LDO | digikey-footprints:SOIC-8_W3.9mm | 1 | STMicro | L4931ABD33-TR | Digikey | 497-1155-1-ND
D1 | USBLC6-2SC6 | digikey-footprints:SOT23-6L | 1 | STMicro | USBLC6-2SC6 | Digikey | 497-5235-1-ND
J1 | Micro-USB Connector | digikey-footprints:USB_Micro_B_Female_10118194-0001LF | 1 | Amphenol | 10118194-0001LF | Digikey | 609-4613-1-ND
U1 | 93LCxxB | mem:SOIC127P600X175-8N | 1 | MicroChip | 93LC46B-I/SN | Digikey | 93LC46B-I/SN-ND
Y1 | 12MHz Crystal | oscillator:CTS_405_xtal | 1 | CTS | 405C35E12M00000 | Digikey | CTX819DKR-ND
U4;U5 | MAX8510 | rf:21-0076E_FLIP | 2 | Maxim | MAX8510EXK30+T | Digikey | MAX8510EXK30+TCT-ND
J3 | SMA-Cinch_142-0701-851 | rf:Cinch_142-0701-851 | 1 | Linx Technologies | 5-1814832-1 | Digikey | CONSMA001-SMD-G-ND
U7;U9 | SAWTEK-855969 | rf:Sawtek_855969 | 2 | Qorvo | 855969 | Mouser | 772-855969
X1 | 13.368MHz TCXO | rf:TCXO_Taitien | 1 | Taitien | TXETCDSANF-16.368000 | Digikey | 1664-1271-1-ND
U6 | MAX2771 | rf:TQFP_29_EP_MAX2769 | 1 | Maxim | MAX2771ETI+ | Digikey | MAX2771ETI+-ND
U8 | LT1719S6 -- Not Populated | rf:TSOT-23_S6 | 1 | Linear Tech | LT1719IS6#TRMPBF | Digikey | LT1719IS6#TRMPBFCT-ND

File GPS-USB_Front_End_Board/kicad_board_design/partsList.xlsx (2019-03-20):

Part | Source | Part # | Mfg | Mfg # | Datasheet | Quantity/Board | Price ea | footprint
comparator | Digikey | LT1719IS6#TRMPBFCT-ND |  |  |  |  |  | 1
SAW filter | Mouser | 772-855969 | SawTek |  | https://www.mouser.com/datasheet/2/412/855969-846512.pdf | 2 | 4.22 | 1
Front End | Mouser | 77-MAX2769ETI+ | Maxim | 2769 | https://www.mouser.com/datasheet/2/256/MAX2769-103424.pdf | 1 | 13.21 | 1
TCXO, 13.368MHz | Digikey | 1664-1271-1-ND | Taitien |  | http://www.taitien.com/wp-content/uploads/2015/12/XO-0076_TX.pdf | 1 | 2.91 | 1
SMA conn | Digikey | WM5534-ND (https://www.mouser.com/ProductDetail/Linx-Technologies/CONSMA002-SMD-G) | Molex |  |  | 2 | 3.33 | 1
USB Conn | Digikey | 609-4613-1-ND (https://www.digikey.com/product-detail/en/molex-llc/1051330001/WM9734CT-ND/4037910) | Amphenol |  | https://cdn.amphenol-icc.com/media/wysiwyg/files/documentation/datasheet/inputoutput/io_usb_micro.pdf | 1 | 0.42 | 1
USB I/F | Digikey | 768-1024-1-ND (https://www.mouser.com/ProductDetail/FTDI/FT2232H-56Q-TRAY) | FTDI | FT2232H | http://www.ftdichip.com/Support/Documents/DataSheets/ICs/DS_FT2232H.pdf | 1 | 6.71 | 1
TVS Diode | Digikey | 497-5235-1-ND USB | ST Micro |  | http://www.st.com/content/ccc/resource/technical/document/datasheet/06/1d/48/9c/6c/20/4a/b2/CD00050750.pdf/files/CD00050750.pdf/jcr:content/translations/en.CD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 | 1 | 0.49 | 1
Resettable PTC | Digikey | F2772CT-ND | Littlefuse | 0805L050WR | http://www.littelfuse.com/~/media/electronics/datasheets/resettable_ptcs/littelfuse_ptc_0805l_datasheet.pdf.pdf | 1 | 0.5 | 1
Ferrite Bead | Digikey | 587-1828-1-ND | Taiyo Yuden | BK0603HS330-T | https://www.yuden.co.jp/productdata/catalog/mlci07_e.pdf | 1 | 0.14 | 1
FPGA | Digikey | 122-1953-ND (https://www.digikey.com/product-detail/en/xilinx-inc/XC6SLX9-2TQG144I/122-1953-ND/2339920) | Xilinx | XC6SLX9-2TQG144I (https://www.digikey.com/product-detail/en/xilinx-inc/XC6SLX9-2TQG144I/122-1953-ND/2339920) | https://www.xilinx.com/support/documentation/data_sheets/ds162.pdf | 1 | 18.97
LED, green | Digikey | 160-1404-1-ND | Lite-On |  | http://optoelectronics.liteon.com/upload/download/DS22-2000-072/LTST-C150KGKT.pdf | 1 | 0.38
LED, red | Digikey | 160-1405-1-ND | Lite-On |  | http://optoelectronics.liteon.com/upload/download/DS-22-99-0149/LTST-C150KRKT.pdf | 1 | 0.38
LDO, 3.3V, 250mA | Digikey | 497-1155-1-ND | ST Micro |  | http://www.st.com/content/ccc/resource/technical/document/datasheet/ff/95/2f/6a/75/70/42/49/CD00000971.pdf/files/CD00000971.pdf/jcr:content/translations/en.CD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 | 1 | 1.03 | 1
LDO, 3V
crystal, 12MHz | Digikey | CTX819DKR-ND (https://www.digikey.com/product-detail/en/cts-frequency-controls/ATS12ASM-1/CTX1079CT-ND/2640231) |  |  | http://www.ctscorp.com/wp-content/uploads/405.pdf |  |  | 1
eeprom | Digikey | 93LC46B-I/SN-ND | 93LC46B-I/SN-ND |  |  |  |  | 1
.1uF decoupling | Digikey | 445-5613-1-ND | CAP CER 0.1UF 16V X7R 0402
1uF decoupling | Digikey | 1276-1946-1-ND | CAP CER 1UF 10V X7R 0603
3.3uF decoupling | Digikey | 445-7582-1-ND | CAP CER 3.3UF 16V X7R 0805
2.2uF decoupling | Digikey | 445-1420-1-ND | CAP CER 2.2UF 16V X7R 0805
10uF | Digikey | 1276-1948-1-ND | CAP CER 10UF 6.3V X7R 0603
10pF | Digikey | 399-17612-1-ND | CAP CER SMD 0805 10PF 10% X7R 50
33pF | Digikey | 478-6211-1-ND | CAP CER 33PF 16V X7R 0603
100pF | Digikey | 399-15003-1-ND | CAP CER 100PF 16V X7R 0805
470pF | Digikey | 478-1097-1-ND | CAP CER 470PF 50V X7R 0402
27pF | Digikey | 478-11394-1-ND | CAP CER 27PF 50V X7R 0805
3300pF | Digikey | 478-10681-1-ND | CAP CER 3300PF 50V X7R 0603
10nF | Digikey | 490-1313-1-ND | CAP CER 10000PF 16V X7R 0402
6.2nH | Digikey | 490-1163-1-ND | FIXED IND 6.2NH 750MA 82 MOHM 0603
4.3nH | Digikey | 490-6572-1-ND | FIXED IND 4.3NH 750MA 180 MOHM 0402
33nH | Digikey | CI100505-33NJCT-ND | FIXED IND 33NH 200MA 800 MOHM 0402
jumper | Digikey | 541-4013-1-ND | RES SMD 0 OHM JUMP 1/10W 0603
10K | Digikey | A126417DKR-ND | RES SMD 10K OHM 1% 1/3W 0805
12K | Digikey | A103037CT-ND (https://www.digikey.com/product-detail/en/te-connectivity-passive-product/CPF0603B12KE1/A103037CT-ND/2728587) | RES SMD 12K OHM 0.1% 1/16W 0603
20K | Digikey | CRT0603-FZ-2002ESTCT-ND (https://www.digikey.com/product-detail/en/bourns-inc/CRT0603-FZ-2002EST/CRT0603-FZ-2002ESTCT-ND/7928092) | RESTHINFILM 0603 20K0 1% 100MW T
2K | Digikey | YAG3590CT-ND (https://www.digikey.com/product-detail/en/yageo/AC0603FR-072KL/YAG3590CT-ND/6006439) | RES SMD 2K OHM 1% 1/10W 0603
https://www.maximintegrated.com/en/app-notes/index.mvp/id/4237
https://www.maximintegrated.com/en/app-notes/index.mvp/id/4279
https://maximintegratedsupport.force.com/support/servlet/fileField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
https://www.maximintegrated.com/en/app-notes/index.mvp/id/4275
https://datasheets.maximintegrated.com/en/ds/MAX2769EVKIT.pdf
https://www.maximintegrated.com/en/app-notes/index.mvp/id/3910
http://www.ftdichip.com/Support/Documents/AppNotes/AN_114_FTDI_Hi_Speed_USB_To_SPI_Example.pdf
http://www.ftdichip.com/Support/Documents/AppNotes/AN_110_Programmers_Guide_for_High_Speed_FTCJTAG_DLL.pdf
http://www.ftdichip.com/Support/Documents/AppNotes/AN_111_Programmers_Guide_for_High_Speed_FTCSPI_DLL.pdf
http://www.ftdichip.com/Support/Documents/AppNotes/AN_129_FTDI_Hi_Speed_USB_To_JTAG_Example.pdf
http://www.ftdichip.com/Support/Documents/AppNotes/AN_130_FT2232H_Used_In_FT245%20Synchronous%20FIFO%20Mode.pdf
http://www.ftdichip.com/Support/Documents/AppNotes/AN_146_USB_Hardware_Design_Guidelines_for_FTDI_ICs.pdf

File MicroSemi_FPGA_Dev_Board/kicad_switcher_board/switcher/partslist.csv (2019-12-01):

Refs | Value | Footprint | Quantity | MFR | MPN | SPR | SPN
C10;C11 | 10uF | Capacitor_SMD:C_0603_1608Metric | 2 | Taiyo Yuden | JMK107BJ106MA-T | Digikey | 587-1256-1-ND
C9 | 22pF | Capacitor_SMD:C_0603_1608Metric | 1 | Yageo | CC0603JRNPO9BN220 | Digikey | 311-1062-1-ND
C4 | 680pF | Capacitor_SMD:C_0603_1608Metric | 1 | Yageo | CC0603KRX7R9BB681 | Digikey | 311-1188-1-ND
C6 | 22uF | Capacitor_SMD:C_1210_3225Metric | 1 | Taiyo Yuden | JMK325BJ226MM-T | Digikey | 587-1384-1-ND
L2 | 6.8uH | Inductor_SMD:L_1206_3216Metric | 1 | Taiyo Yuden | CB2518T6R8M | Digikey | 587-2188-1-ND
L1 | 2.2uH | Inductor_SMD:L_Wuerth_MAPI-2512 | 1 | Wurth | 74405024022 | Digikey | 732-10776-1-ND
U2 | LTC3561A | Package_DFN_QFN:DFN-8-1EP_3x3mm_P0.5mm_EP1.66x2.38mm | 1 | Analog Devices | Package_DFN_QFN:DFN-8-1EP_3x3mm_P0.5mm_EP1.66x2.38mm | Digikey | Package_DFN_QFN:DFN-8-1EP_3x3mm_P0.5mm_EP1.66x2.38mm
R2 | 16.9K | Resistor_SMD:R_0603_1608Metric | 1 | Yageo | RT0603DRE0716K9L | Digikey | 311-2441-1-ND
R5 | 249K | Resistor_SMD:R_0603_1608Metric | 1 | Yageo | RT0603BRD07249KL | Digikey | YAG4510CT-ND
R4 | 287K | Resistor_SMD:R_0603_1608Metric | 1 | Yageo | RT0603BRD07287KL | Digikey | YAG1609CT-ND
R3 | 549K | Resistor_SMD:R_0603_1608Metric | 1 | Yageo | RC0603FR-07549KL | Digikey | 311-549KHRCT-ND
J1 |  |  | 1 | Amph |  | Digikey | 609-4618-6-ND
 |  |  | 1 | Cinch |  | Digikey | J658-ND

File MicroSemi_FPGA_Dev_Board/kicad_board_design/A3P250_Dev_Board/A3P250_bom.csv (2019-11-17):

Refs | Value | Footprint | Quantity | MFR | MPN | SPR | SPN
C12;C14;C16;C20;C18 | .1uF | Capacitor_SMD:C_0402_1005Metric | 5 | - | CGA2B1X7R1C104K050BC | Digikey | 445-5613-1-ND
C13;C17;C21;C19;C15;C3;C7;C1 | 0.01uF | Capacitor_SMD:C_0603_1608Metric | 8 | Kemet | C0603C103K5RAC7081 | Digikey | 399-C0603C103K5RAC7081CT-ND
C2 | 0.33uF | Capacitor_SMD:C_0603_1608Metric | 1 | Yageo | CC0603KRX5R7BB334 | Digikey | 311-4045-1-ND
C10;C8;C11 | 10uF | Capacitor_SMD:C_0603_1608Metric | 3 | Taiyo Yuden | JMK107BJ106MA-T | Digikey | 587-1256-1-ND
C5 | 1uF | Capacitor_SMD:C_0603_1608Metric | 1 | Samsung | CL10B105KP8NNNC | Digikey | 1276-1946-1-ND
C9 | 22pF | Capacitor_SMD:C_0603_1608Metric | 1 | Yageo | CC0603JRNPO9BN220 | Digikey | 311-1062-1-ND
C4 | 680pF | Capacitor_SMD:C_0603_1608Metric | 1 | Yageo | CC0603KRX7R9BB681 | Digikey | 311-1188-1-ND
C6 | 22uF | Capacitor_SMD:C_1210_3225Metric | 1 | Taiyo Yuden | JMK325BJ226MM-T | Digikey | 587-1384-1-ND
J1;J4;J2;J3 | Conn_01x20 | Connector_PinHeader_2.00mm:PinHeader_1x20_P2.00mm_Vertical | 4 | - | - | - | -
L2 | 6.8uH | Inductor_SMD:L_1206_3216Metric | 1 | Taiyo Yuden | CB2518T6R8M | Digikey | 587-2188-1-ND
L1 | 2.2uH | Inductor_SMD:L_Wuerth_MAPI-2512 | 1 | Wurth | 74405024022 | Digikey | 732-10776-1-ND
D2 | LED_ALT | LED_SMD:LED_0603_1608Metric | 1 | Lite-On | LTST-C191KGKT | Digikey | 160-1446-2-ND
D1 | LED_ALT | LED_SMD:LED_0805_2012Metric | 1 | Lite-On | LTST-C171KRKT | Digikey | 160-1427-1-ND
X1 | ASE-25MHz | Oscillator:Oscillator_SMD_Abracon_ASE-4Pin_3.2x2.5mm | 1 | Abracon | ASE-25.000MHZ-LC-T | Digikey | 535-9568-1-ND
U2 | LTC3561A | Package_DFN_QFN:DFN-8-1EP_3x3mm_P0.5mm_EP1.66x2.38mm | 1 | Analog Devices | LTC3561AEDD#TRPBFCT-ND | Digikey | LTC3561AEDD#TRPBFCT-ND
U1 | A3P250 | Package_QFP:LQFP-100_14x14mm_P0.5mm | 1 | Microsemi | A3P250-VQG100 | Digikey | 1100-1030-ND
U3 | LT1962-3.3 | Package_SO:MSOP-8_3x3mm_P0.65mm | 1 | Analog Devices | LT1962EMS8-3.3#PBF | Digikey | LT1962EMS8-3.3#PBF-ND
R2 | 16.9K | Resistor_SMD:R_0603_1608Metric | 1 | Yageo | RT0603DRE0716K9L | Digikey | 311-2441-1-ND
R5 | 249K | Resistor_SMD:R_0603_1608Metric | 1 | Yageo | RT0603BRD07249KL | Digikey | YAG4510CT-ND
R4 | 287K | Resistor_SMD:R_0603_1608Metric | 1 | Yageo | RT0603BRD07287KL | Digikey | YAG1609CT-ND
R3 | 549K | Resistor_SMD:R_0603_1608Metric | 1 | Yageo | RC0603FR-07549KL | Digikey | 311-549KHRCT-ND
R6;R1 | 200 | Resistor_SMD:R_0805_2012Metric | 2 | Susumu | RR1220P-201-D | Digikey | RR12P200DCT-ND

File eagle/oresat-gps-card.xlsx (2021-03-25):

Qty | Part References | Mfg | Mfg PN | Description | Dist | Dist Part Number | Generic | P/DNP
1 | C33 |  |  |  |  |  | Y | DNP
1 | C64 | Murata Electronics | GCQ1555C1H1R7CB01D | CAP CER 1.7PF 50V C0G/NP0 0402 | Digi-Key | 490-17440-1-ND | Y | P
4 | C19, C22, C29, C30 | TDK Corporation | CGA3E2C0G1H120J080AA | CAP CER 12PF 50V C0G 0603 | Digi-Key | 445-5629-1-ND | Y | P
1 | C16 | TDK Corporation | CGA3E2C0G1H270J080AA | CAP CER 27PF 50V C0G 0603 | Digi-Key | 445-5633-1-ND | Y | P
1 | C81 | TDK Corporation | CGA2B2C0G1H560J050BA | CAP CER 56PF 50V C0G 0402 | Digi-Key | 445-5593-1-ND | Y | P
9 | C21, C26, C27, C42, C43, C44, C54, C57, C80 | TDK Corporation | CGA3E2C0G2A101J080AA | CAP CER 100PF 100V C0G 0603 | Digi-Key | 445-5724-1-ND | Y | P
1 | C63 | TDK Corporation | CGA2B2C0G1H471J050BA | CAP CER 470PF 50V C0G 0402 | Digi-Key | 445-5604-1-ND | Y | P
1 | C17 | TDK Corporation | CGA3E2C0G1H471J080AA | CAP CER 470PF 50V C0G 0603 | Digi-Key | 445-5648-1-ND | Y | P
4 | C46, C50, C60, C69 | Murata Electronics | GCM188R72A103KA37D | CAP CER 10000PF 100V X7R 0603 | Digi-Key | 490-4781-1-ND | Y | P
22 | C4, C11, C18, C20, C23, C24, C25, C28, C31, C39, C40, C41, C45, C51, C55, C56, C61, C65, C70, C82, C83, C84 | TDK Corporation | CGA3E2X7R1E104K080AA | CAP CER 0.1UF 25V X7R 0603 | Digi-Key | 445-5667-1-ND | Y | P
16 | C3, C5, C6, C9, C10, C12, C34, C37, C47, C48, C49, C52, C59, C67, C68, C79 | Taiyo Yuden | TMK107BJ105KAHT | CAP CER 1UF 25V X7R 0603 | Digi-Key | 587-3473-1-ND | Y | P
2 | C32, C35 | TDK Corporation | CGA4J2X7R1C105K125AA | CAP CER 1UF 16V X7R 0805 | Digi-Key | 445-5689-1-ND | Y | P
2 | C53, C58 | TDK Corporation | CGA3E1X5R1C225K080AC | CAP CER 2.2UF 16V X5R 0603 | Digi-Key | 445-6932-1-ND | Y | P
6 | C1, C2, C7, C8, C38, C62 | TDK Corporation | CGA4J3X5R1A106K125AB | CAP CER 10UF 10V X5R 0805 | Digi-Key | 445-6970-1-ND | Y | P
4 | C13, C14, C15, C36 | TDK Corporation | CGA6P1X7R1C226M250AC | CAP CER 22UF 16V X7R 1210 | Digi-Key | 445-5723-1-ND | Y | P
1 | C85 | Elna America | DSK-3R3H334T-HL | 330mF (EDLC) Supercapacitor 3.3V Coin |  |  | Y | DNP
1 | CM1 | MOLEX | 733000020 | Edge mounted SMPM 50ohm Connector | Digi-Key | WM10772-ND | N | P
3 | D1, D7, D8 | Wurth Electronik | 150060GS75020 | Green 525nm LED Indication - Discrete 3.2V 0603 | Digi-Key | 732-150060GS75020CT-ND | Y | P
4 | D2, D3, D4, D5 | Wurth Electronik | 150060BS75020 | Blue 470nm LED Indication - Discrete 3.2V 0603 | Digi-Key | 732-150060BS75020CT-ND | Y | P
1 | D6 | Wurth Electronik | 150060AS75020 | Amber 605nm LED Indication - Discrete 2V 0603 | Digi-Key | 732-150060AS75020CT-ND | Y | P
1 | D9 |  |  | REPLACE WITH ZERO OHM | DNP | DNP | DNP | DNP
1 | D10 | Wurth Electronik | 150060YS75020 | Yellow 590nm LED Indication - Discrete 2V 0603 | Digi-Key | 732-150060YS75020CT-ND | Y | P
2 | FB1, FB2 | Murata Electronics | BLM18KG300JH1D | FERRITE BEAD 30 OHM 0603 1 LN | Digi-Key | 490-14027-1-ND | N | P
1 | J1 | TE Connectivity | 2-1734592-0 | CONN FPC BOTTOM 20POS 0.50MM R/A | Digi-Key | A100287CT-ND | N | P
1 | J100 | Hirose Electric | DM3BT-DSF-PEJS | HIROSE - microSD Card socket - Reverse on-Board - Push / Push | Digi-Key | HR1942CT-ND | N | DNP
1 | J4 | Samtec Inc | TFM-120-01-L-D-RA | CONN HEADER R/A 40POS 1.27MM | Digi-Key | SAM10145-ND | N | P
1 | L3 | TDK Corporation | MLG1005S5N6STD25 | FIXED IND 5.6NH 600MA 250 MOHM 0402 | Digi-Key | 445-16312-1-ND | Y | P
1 | L1 | ECS Inc | ECS-MPI4040R4-6R8-R | FIXED IND 6.8UH 2.4A 91 MOHM SMD | Digi-Key | XC2337CT-ND | N | P
1 | Q1 | Diodes Incorporated | MMBT2907A-7-F | Bipolar (BJT) Transistor PNP SOT23-3 | Digi-Key | MMBT2907A-FDICT-ND | N | P
2 | Q2, Q4 | Nexperia USA | PMV45EN2R | MOSFET N-CH 30V 4.1A TO236AB | Digi-Key | 1727-2307-1-ND | N | P
1 | Q3 | Diodes Incorporated | DMP2240UDM-7 | Dual P channel MOSFETs in an SOT23-6 | Digi-Key | DMP2240UDMDICT-ND | N | P
2 | Q5, Q6 | Diodes Incorporated | DMP3050LVT-7 | P channel MOSFET in an SOT23-6 | Digi-Key | DMP3050LVT-7DICT-ND | N | P
20 | R27, R33, R38, R40, R42, R51, R53, R54, R55, R56, R57, R58, R59, R60, R65, R66, R67, R68, R69, R70 |  |  |  |  |  | Y | DNP | Order from minicircuits
3 | R47, R50, R76 | Panasonic Electronic Components | ERJ-3GEY0R00V | RES SMD 0 OHM JUMPER 1/10W 0603 | Digi-Key | P0.0GCT-ND | Y | P
1 | R63 | Vishay Dale | RCWE1206R100FKEA | RES 0.1 OHM 1% 1/2W 1206 | Digi-Key | 541-2740-1-ND | Y | P
6 | R41, R48, R71, R73, R74, R75 | Panasonic Electronic Components | ERJ-3EKF1000V | RES SMD 100 OHM 1% 1/10W 0603 | Digi-Key | P100HCT-ND | Y | P
1 | R23 | Panasonic Electronic Components | ERJ-3EKF4990V | RES SMD 499 OHM 1% 1/10W 0603 | Digi-Key | P499HCT-ND | Y | P
6 | R1, R2, R3, R4, R5, R17 | Panasonic Electronic Components | ERJ-PA3J102V | RES SMD 1K OHM 5% 1/4W 0603 | Digi-Key | P1KBZCT-ND | Y | P
3 | R49, R61, R62 | Panasonic Electronic Components | ERJ-3GEYJ272V | RES SMD 2.7K OHM 5% 1/10W 0603 | Digi-Key | P2.7KGCT-ND | Y | P
1 | R77 | Panasonic Electronic Components | ERA-2AEB103X | RES SMD 10K OHM 0.1% 1/16W 0402 | Digi-Key | P10KDCCT-ND | Y | P
24 | R6, R7, R12, R14, R15, R16, R18, R19, R20, R22, R28, R29, R30, R32, R34, R39, R46, R52, R64, R72, R78, R79, R80, R81 | Panasonic Electronic Components | ERJ-3EKF1002V | RES SMD 10K OHM 1% 1/10W 0603 | Digi-Key | P10.0KHCT-ND | Y | P
3 | R8, R9, R10 | Panasonic Electronic Components | EXB-A10P103J | RES ARRAY 8 RES 10K OHM 2512 | Digi-Key | U7103CT-ND | N | P
1 | R11 | Panasonic Electronic Components | ERJ-PB3B2002V | RES SMD 20K OHM 0.1% 1/5W 0603 | Digi-Key | P20118CT-ND | Y | P
1 | R21 | Panasonic Electronic Components | ERJ-3EKF3302V | RES SMD 33K OHM 1% 1/10W 0603 | Digi-Key | P33.0KHCT-ND | Y | P
1 | R31 | Panasonic Electronic Components | ERJ-3EKF4022V | RES SMD 40.2K OHM 1% 1/10W 0603 | Digi-Key | P40.2KHCT-ND | Y | P
3 | R24, R25, R26 | Panasonic Electronic Components | EXB-A10P104J | RES ARRAY 8 RES 100K OHM 2512 | Digi-Key | U7104CT-ND | N | P
2 | R37, R45 | Panasonic Electronic Components | ERJ-3EKF3303V | RES SMD 330K OHM 1% 1/10W 0603 | Digi-Key | P330KHCT-ND | Y | P
2 | R35, R43 | Panasonic Electronic Components | ERJ-3EKF6653V | RES SMD 665K OHM 1% 1/10W 0603 | Digi-Key | P665KHCT-ND | Y | P
3 | R13, R36, R44 | Panasonic Electronic Components | ERJ-3GEYJ105V | RES SMD 1M OHM 5% 1/10W 0603 | Digi-Key | P1.0MGCT-ND | Y | P
1 | SH1A | Laird Technologies EMI | BMI-S-202-C | RF SHIELD 0.668"X0.668" SNAP FIT | Digi-Key | 903-1014-ND | N | P
1 | SHA1B | Laird Technologies EMI | BMI-S-202-F | RF Shield Frame 0.650" (16.50mm) X 0.650" (16.50mm) - Solder | Digi-Key | 903-1051-1-ND | N | P
2 | U1, U18 | Semtech Corporatoin | RCLAMP0504FBTCT | 17.5V Clamp 28A SC70-6 | Digi-Key | RCLAMP0504FBTCTCT-ND | N | P
1 | U2 | Texas Instruments | TPS2051CDBVR | IC PWR SWITCH N-CHAN 1:1 SOT23-5 | Digi-Key | 296-29537-1-ND | N | P
1 | U3 | Kioxia America | THGBMJG6C1LBAU7 | eMMC (embedded multi-media card) memory with optional Reset function | Digi-Key | THGBMJG6C1LBAU7-ND | N | P
1 | U4 | Texas Instruments | SN74LVC1G07DCKRG4 | IC BUF NON-INVERT 5.5V SC70-5 | Digi-Key | 296-35937-1-ND | N | P
1 | U5 | Skyworks Solutions | SKY65723-81 | IC RF AMP LNA GPS/GNSS SPFS | Digi-Key | 863-2063-1-ND | N | P
1 | U6 | TXC Corporation | 7Q-16.368MBG-T | XTAL OSC TCXO 16.3680MHZ SNWV | Digi-Key | 887-1548-1-ND | N | P
1 | U7 | Octavo Systems | OSD3358-512M-BSM | Octavo Systems LLC OSD335x Family SiP: 21mm x 21mm, 1.27mm pitch 256 pin BGA contains AM3358, 512MB DDR3, TPS65217, TL5209, 4KB EEPROM and passives. Commerical Temperature (case): 0C to 85C. | Digi-Key | 1676-1002-ND | N | P
3 | U8, U9, U20 | Maxim Integrated | MAX8510EXK29+T | IC REG LINEAR 2.85V 120MA SC70-5 | Digi-Key | MAX8510EXK29+TCT-ND | N | P
1 | U10 | Texas Instruments | TLVH431BQDBZRQ1 | IC VREF SHUNT 18V 0.5% SOT23-3 | Digi-Key | 296-36778-1-ND | N | P
1 | U11 | Texas Instruments | TCAN330GDCNT | 1/1 Transceiver CANbus SOT-23-8 | Digi-Key | 296-44211-1-ND | N | P
2 | U12, U13 | Microchip Technology | MIC842LYC5 | Comparator with Voltage Reference Push-Pull SC-70-5 | Digi-Key | 576-2927-1-ND | N | P
1 | U14 | Maxim Integrated | MAX4211FETE+ | Current Monitor Regulator High-Side 16-TQFN | Digi-Key | MAX4211FETE+-ND | N | P
1 | U15 | Texas Instruments | TPS62112RSAR | IC REG BUCK 5V 1.5A 16QFN | Digi-Key | 296-39444-1-ND | N | P
1 | U16 | Maxim Integrated | MAX7310ATE | IC I/O EXPANDER I2C 8B 16TQFN | Digi-Key | MAX7310ATE+-ND | N | P
1 | U17 |  | 25AA02E48T-I/SN |  |  |  |  | DNP
1 | U19 | Mini-Circuits | BP2G+ | MMIC DP Pass Power Splitter 1420-1660 MHz, 50 Ohm | Mini-Circuits |  | N | P
1 | U21 | Kyocera International | SF14-1575F5UUA1 | FILTER SAW 1.575GHZ 5SMD | Digi-Key | 478-6834-1-ND | N | P
1 | U22 | Analog Devices | LT1719IS6#TRMPBF | Comparator General Purpose CMOS | Digi-Key | LT1719IS6#TRMPBFCT-ND | N | P
1 | U23 | Maxim Integrated | MAX2771ETI+ | RF RX GNSS 1.227/1.575GHZ 28TQFN | Digi-Key | MAX2771ETI+-ND | N | P
1 | U24 | SkyTraq | VENUS838LPX-L | Single chip GPS module | SkyTraq |  | N | P
1 | Y1 | ECS Inc | ECS-240-12-30BQ-AEN-TR | CRYSTAL 24.0000MHZ 12PF SMD | Digi-Key | XC2580CT-ND | N | P
1 | Y2 | Abracon LLC | ABS07-32.768KHZ-1-T | 32kHz crystal | Digi-Key | 535-9808-1-ND | N | P

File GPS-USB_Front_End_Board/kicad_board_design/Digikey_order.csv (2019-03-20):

Digi-Key Part Number | Customer Reference | Quantity
1276-6995-1-ND | C11;C13;C14;C15;C16;C21;C22;C30;C23;C36;C38 | 11
1276-1566-1-ND | C28 | 1
1276-1566-1-ND | C37 | 1
1276-1028-1-ND | C26;C17;C24 | 3
CI100505-33NJCT-ND | L4 | 1
1276-1566-1-ND | C27 | 1
1276-1946-1-ND | C18;C12 | 2
478-10681-1-ND | C20 | 1
399-15003-1-ND | C19 | 1
399-15003-1-ND | C32;C31 | 2
478-11394-1-ND | C25 | 1
P0.0ACT-ND | C29 | 1
P0.0GCT-ND | R19 | 1
CRT0603-FZ-2002ESTCT-ND | R13 | 1
P0.0GCT-ND | R20 | 1
P0.0ACT-ND | R12;R15;R16;R17;R18;R14;R10;R9;R8 | 9
A126417CT-ND | R7 | 1
P0.0ACT-ND | R11 | 1
CONSMA001-SMD-G-ND | J3 | 1
MAX8510EXK30+TCT-ND | U4;U5 | 2
535-11782-1-ND | X1 | 1
LT1719IS6#TRMPBFCT-ND | U8 | 1
1276-6995-1-ND | C8;C6;C2 | 3
1276-6995-1-ND | C33;C35;C9 | 3
1276-1948-1-ND | C10 | 1
1276-1946-1-ND | C1 | 1
399-17612-1-ND | C5;C3 | 2
445-1420-1-ND | C7 | 1
445-5970-1-ND | C4;C34 | 2
A103037CT-ND | R2 | 1
YAG3590CT-ND | R6 | 1
A126417CT-ND | R5;R3;R1;R4 | 4
587-1828-1-ND | FB1 | 1
768-1024-1-ND | U2 | 1
497-1155-1-ND | U3 | 1
497-5235-1-ND | D1 | 1
609-4613-1-ND | J1 | 1
93LC46B-I/SN-ND | U1 | 1
CTX819DKR-ND | Y1 | 1

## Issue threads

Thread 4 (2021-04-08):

Connect 1PPS from Venus to an OCTAVO GPIO with fast interrupt response.

andrewgreenberg, 2021-04-08:
Doh!

andrewgreenberg, 2024-05-25:
Fixed in 1.1

Closed 2024-05-25.

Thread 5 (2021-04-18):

GPS card OPD fixes

andrewgreenberg, 2021-04-18:
1. Double circuit breaker current limit by making R50 and R51 10ks .
2. Populate C33, R33, and R38 with 1u, 100k, and 10k.

andrewgreenberg, 2024-05-25:
Fixed in v1.1

Closed 2024-05-25.

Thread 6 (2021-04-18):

Increase resistance of 5V LEDs

andrewgreenberg, 2021-04-18:
oh god they're blinding

andrewgreenberg, 2024-05-25:
Fixed in v1.1

Closed 2024-05-25.

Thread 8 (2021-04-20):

Venus838 symbol is wrong; pins 8/9 and a few others.

andrewgreenberg, 2021-04-20:
In particular, we need to pull up pin 9 (boot_sel).

andrewgreenberg, 2024-05-25:
Not relevant.

Closed 2024-05-25.

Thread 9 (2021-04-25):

Need to rework Skytraq footprint.

oliver-rew, 2021-04-25:
Our footprint did not match reality, we REALLY need to rework this. Lets go through the datasheet pin by pin. For example, we did not break out the boot pin and it was critical.

andrewgreenberg, 2024-05-25:
Not relevant anymore for orion.

Closed 2024-05-25.

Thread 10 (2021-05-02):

L band antenna too narrow for GPS! 1.5 vs 1.2 GHz

davidalay, 2021-05-02:

andrewgreenberg, 2024-05-25:
Not relevant for v1.1

Closed 2024-05-25.

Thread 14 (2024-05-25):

Fix RF trace width coming in and out of the U15 (LNA)

andrewgreenberg, 2024-05-25:

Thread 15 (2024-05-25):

Update Octavo symbol with new one with pin reset states on them, and generally update the card.

andrewgreenberg, 2024-05-25:

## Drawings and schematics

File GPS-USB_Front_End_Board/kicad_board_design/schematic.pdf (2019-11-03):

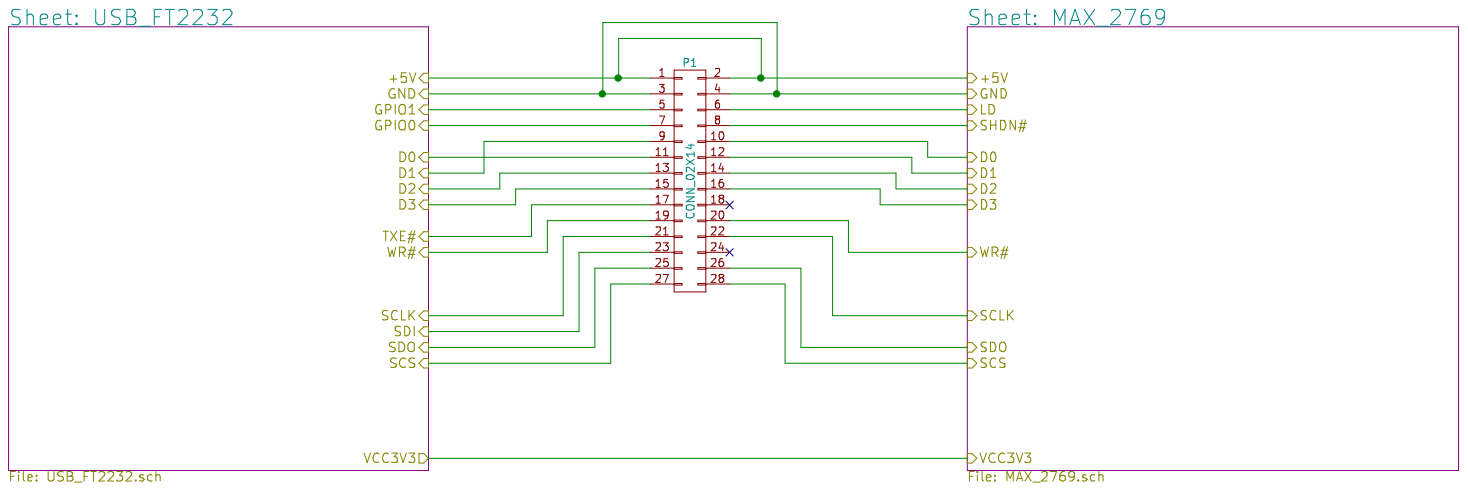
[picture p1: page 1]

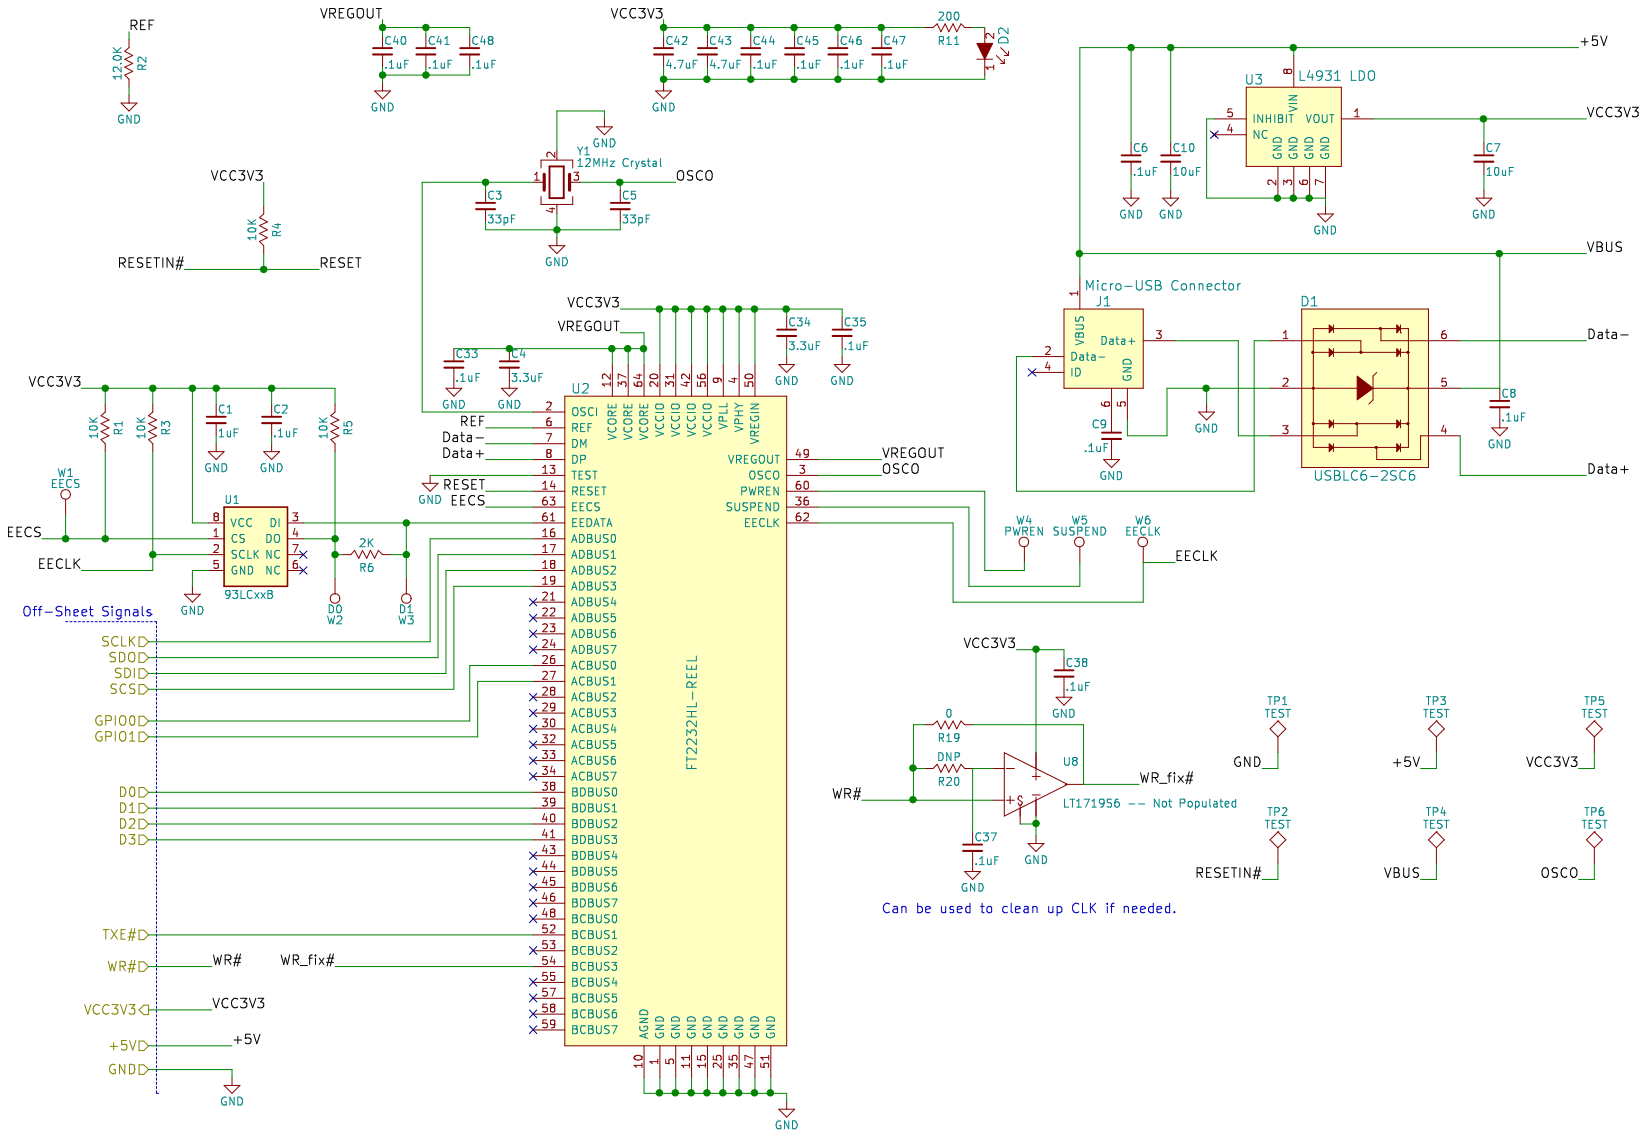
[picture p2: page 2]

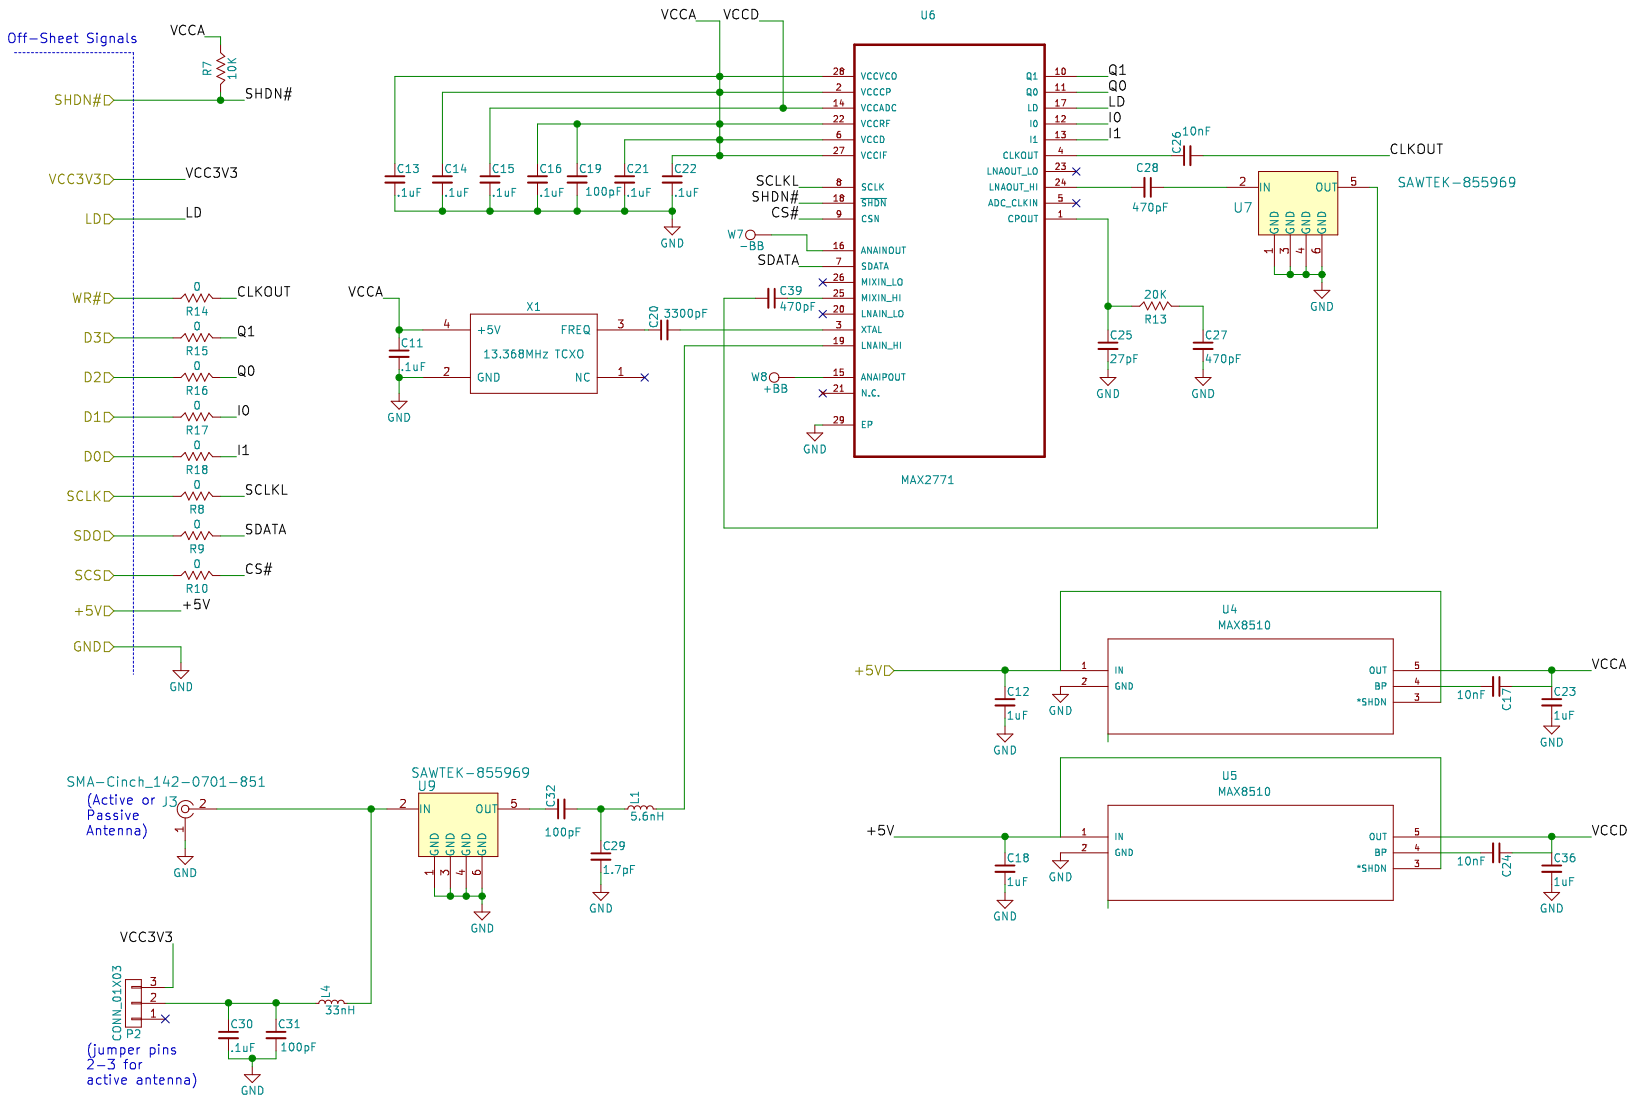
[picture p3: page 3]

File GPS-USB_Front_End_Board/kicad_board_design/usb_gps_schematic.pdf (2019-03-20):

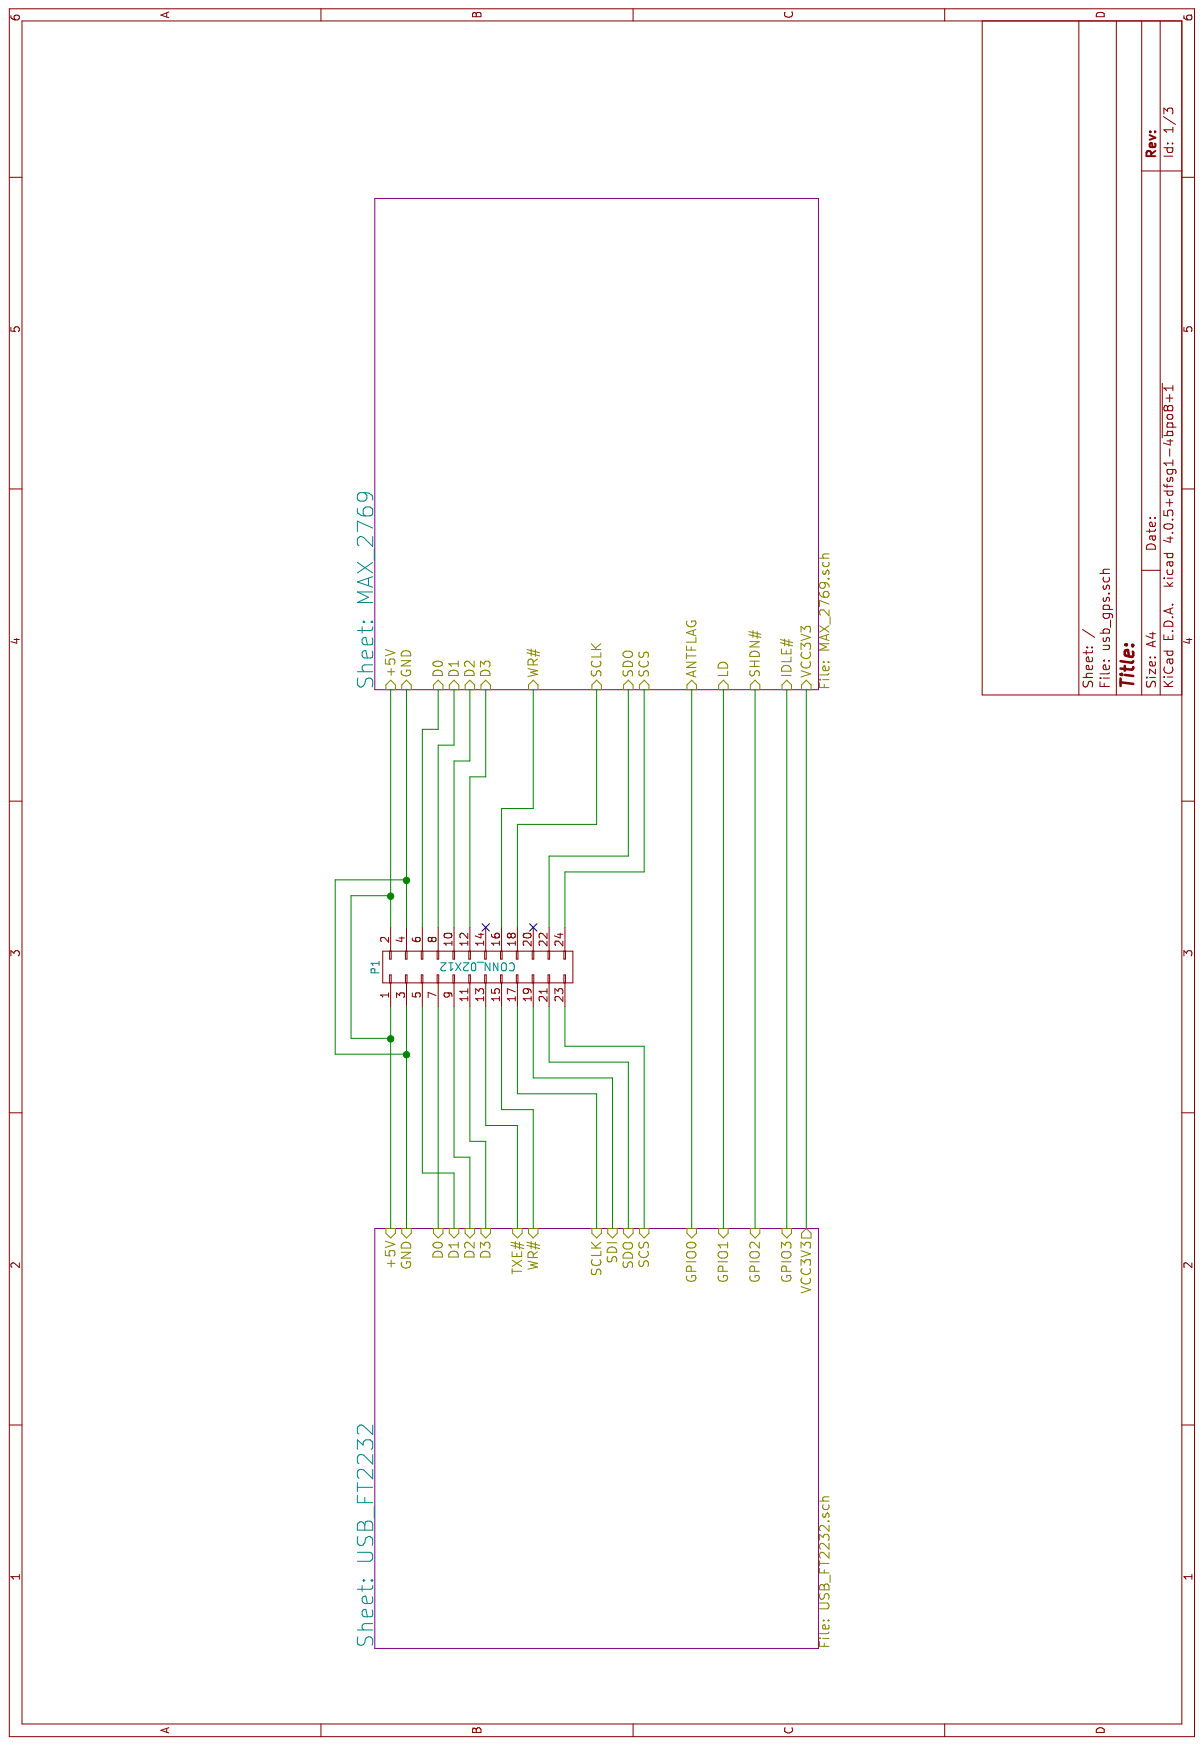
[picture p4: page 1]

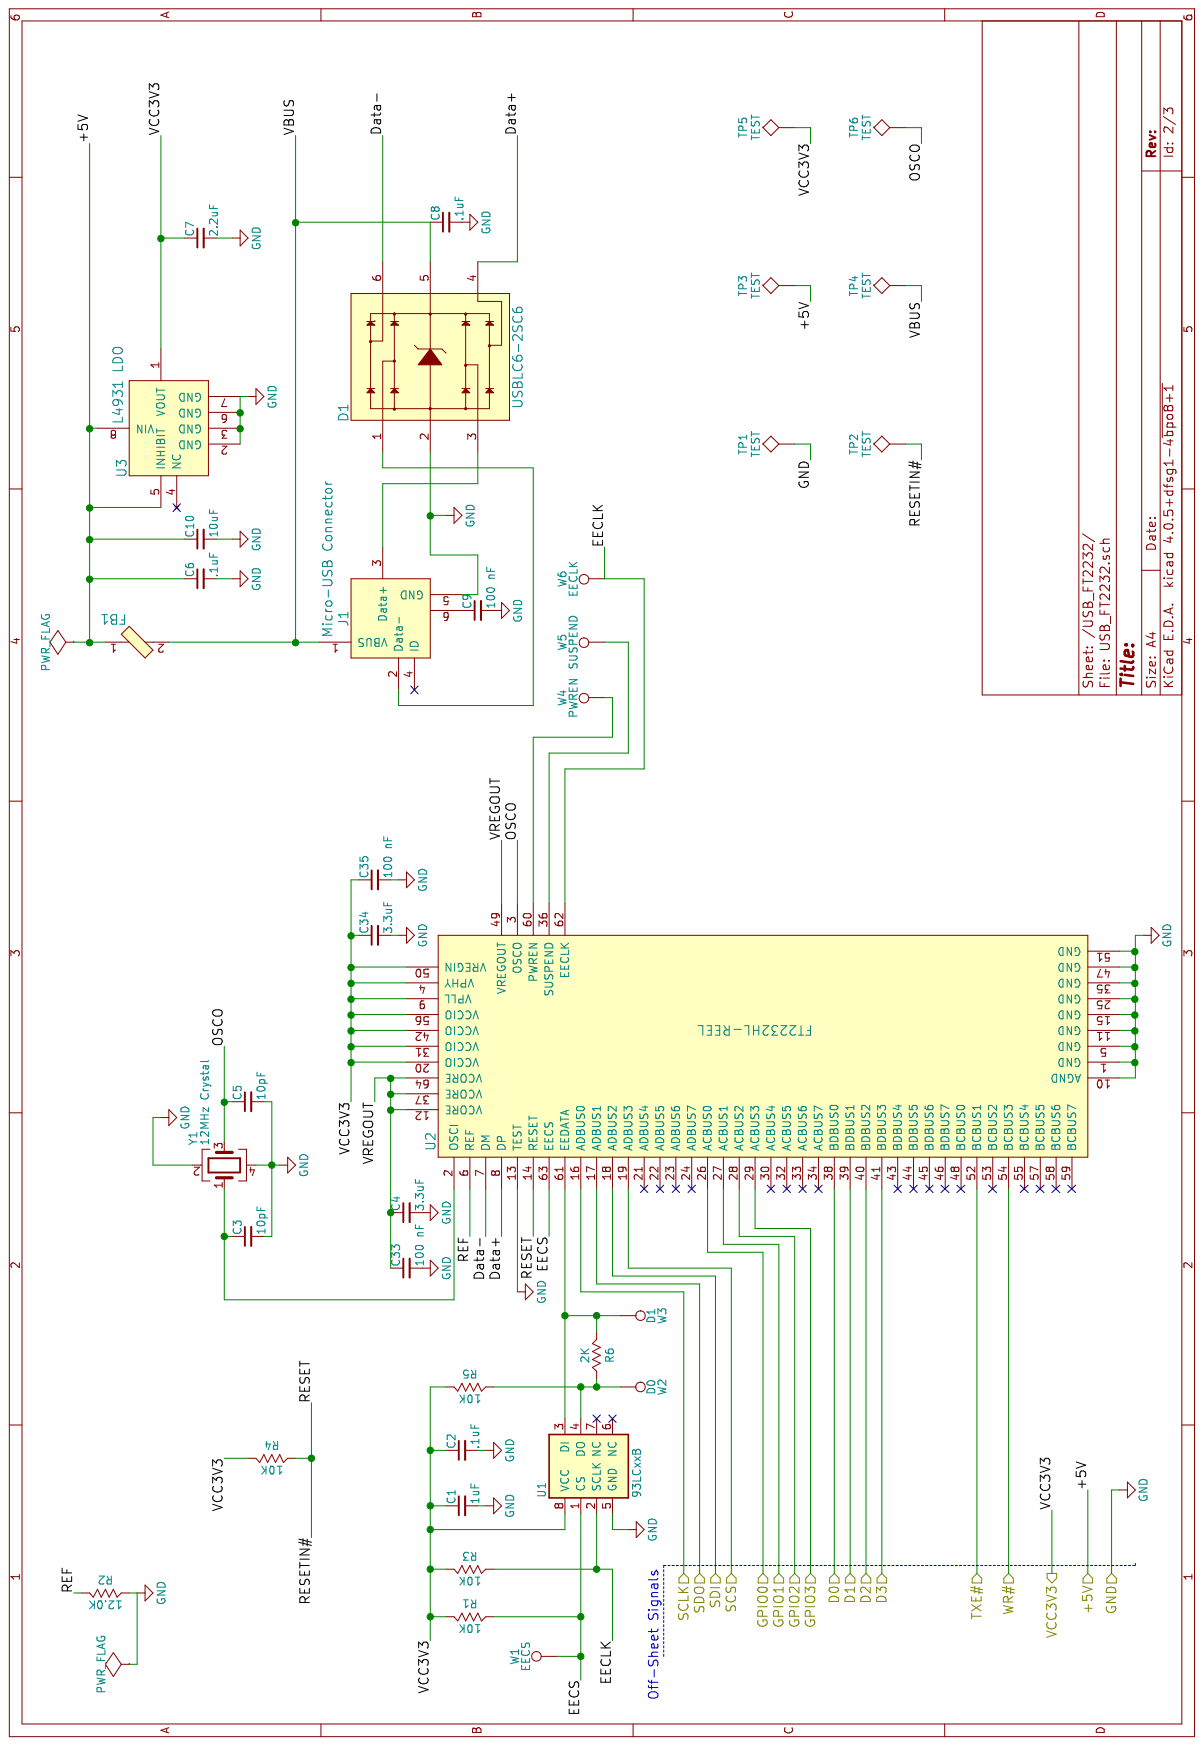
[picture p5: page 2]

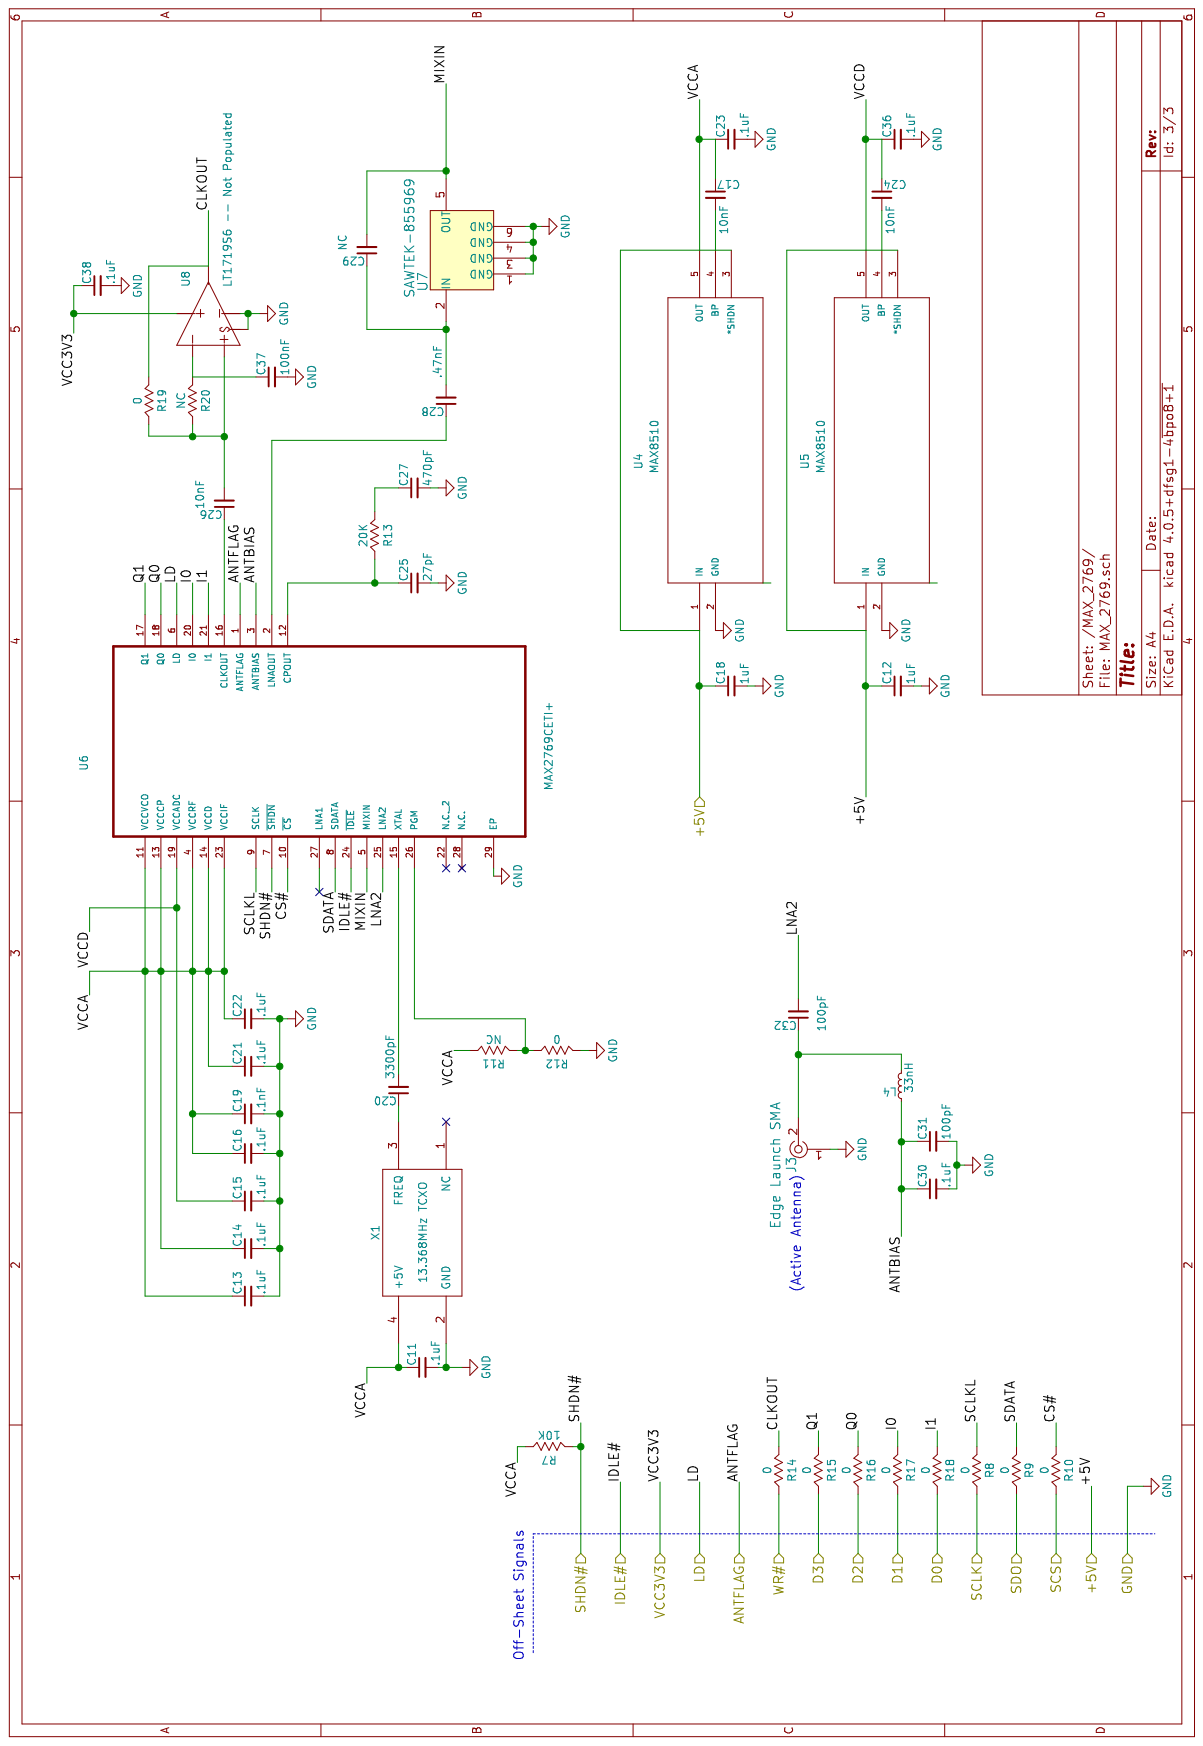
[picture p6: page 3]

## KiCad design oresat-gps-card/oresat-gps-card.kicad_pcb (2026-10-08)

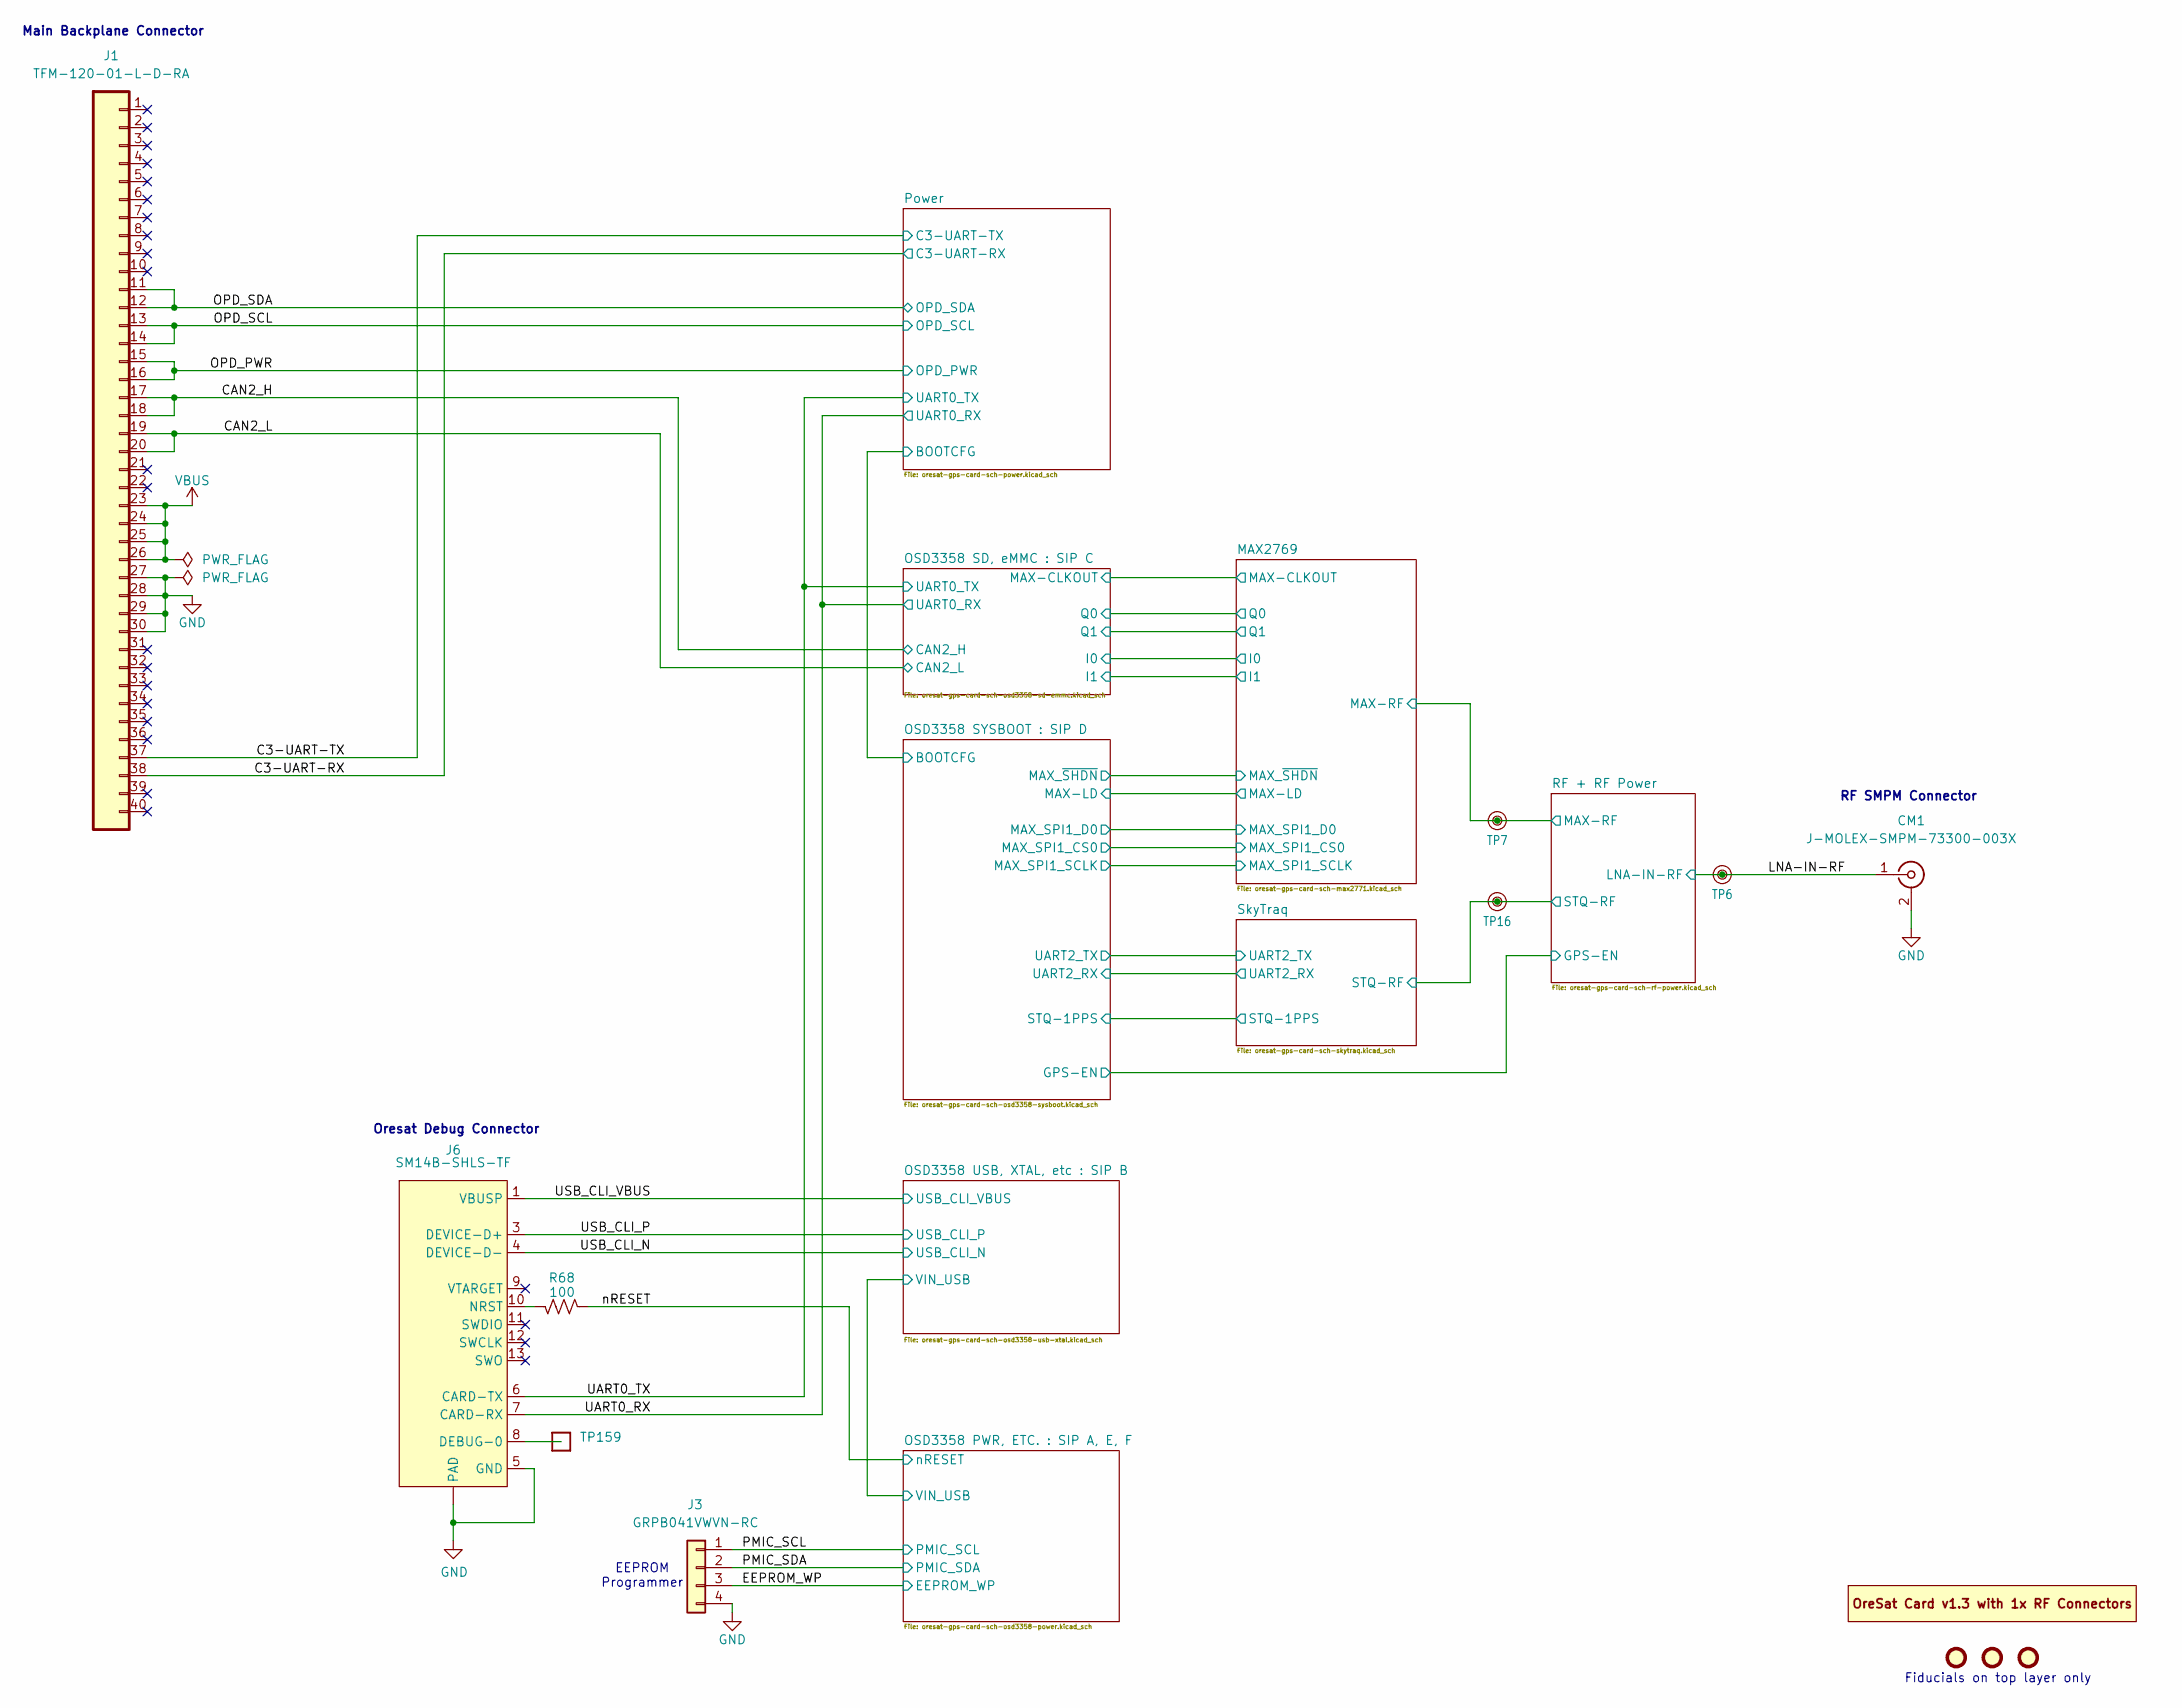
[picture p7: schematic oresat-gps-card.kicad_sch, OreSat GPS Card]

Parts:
CM1: J-MOLEX-SMPM-73300-003X; J-MOLEX-SMPM-073300-002X; MPN 2477330-1
FID1, FID2, FID3: Fiducial; Fiducial_1mm_Mask2mm
J1: TFM-120-01-L-D-RA; J-SAMTEC-TFM-120-X1-XXX-D-RA; MPN TFM-120-01-L-D-RA
J3: GRPB041VWVN-RC; PinHeader_1x04_P1.27mm_Vertical; MPN GRPB041VWVN-RC
J6: SM14B-SHLS-TF; J-JST-SM14BSHLSTF; MPN SM14B-SHLS-TF
PCB1: ORESAT-CARD-V1.3-GENERIC-1RF-POS2; ORESAT-CARD-V1.3-1RF-POS2
R68: 100; 0603-C-NOSILK; MPN RMCF0603FT100R
TP6, TP7, TP16: TestPoint_RF_Probe
TP159: Test-Point; TestPoint-0.75mm-th

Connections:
/C3-UART-RX: J1.38; also elsewhere on the board
/C3-UART-TX: J1.37; also elsewhere on the board
/CAN2_H: J1.17, J1.18; also elsewhere on the board
/CAN2_L: J1.19, J1.20; also elsewhere on the board
/EEPROM_WP: J3.3; also elsewhere on the board
/LNA-IN-RF: CM1.1 (In), TP6.1 (1_1); also elsewhere on the board
/MAX2769/MAX-RF: TP7.1 (1_1); also elsewhere on the board
/OPD_PWR: J1.15, J1.16; also elsewhere on the board
/OPD_SCL: J1.13, J1.14; also elsewhere on the board
/OPD_SDA: J1.11, J1.12; also elsewhere on the board
/PMIC_SCL: J3.1; also elsewhere on the board
/PMIC_SDA: J3.2; also elsewhere on the board
/RF + RF Power/STQ-RF: TP16.1 (1_1); also elsewhere on the board
/UART0_RX: J6.7 (CARD-RX); also elsewhere on the board
/UART0_TX: J6.6 (CARD-TX); also elsewhere on the board
/USB_CLI_N: J6.4 (DEVICE-D-); also elsewhere on the board
/USB_CLI_P: J6.3 (DEVICE-D+); also elsewhere on the board
/USB_CLI_VBUS: J6.1 (VBUSP), J6.2 (VBUSP); also elsewhere on the board
/nRESET: R68.2; also elsewhere on the board
GND: CM1.2 (Ext), J1.27, J1.28, J1.29, J1.30, J3.4, J6.5 (GND), J6.14 (GND), J6.15 (PAD), J6.16 (PAD); also elsewhere on the board
unnamed: J6.8 (DEBUG-0), TP159.1 (1_1)
unnamed: J6.10 (NRST), R68.1
VBUS: J1.23, J1.24, J1.25, J1.26; also elsewhere on the board

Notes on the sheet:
RF SMPM Connector
Main Backplane Connector
Oresat Debug Connector
EEPROM Programmer
Fiducials on top layer only

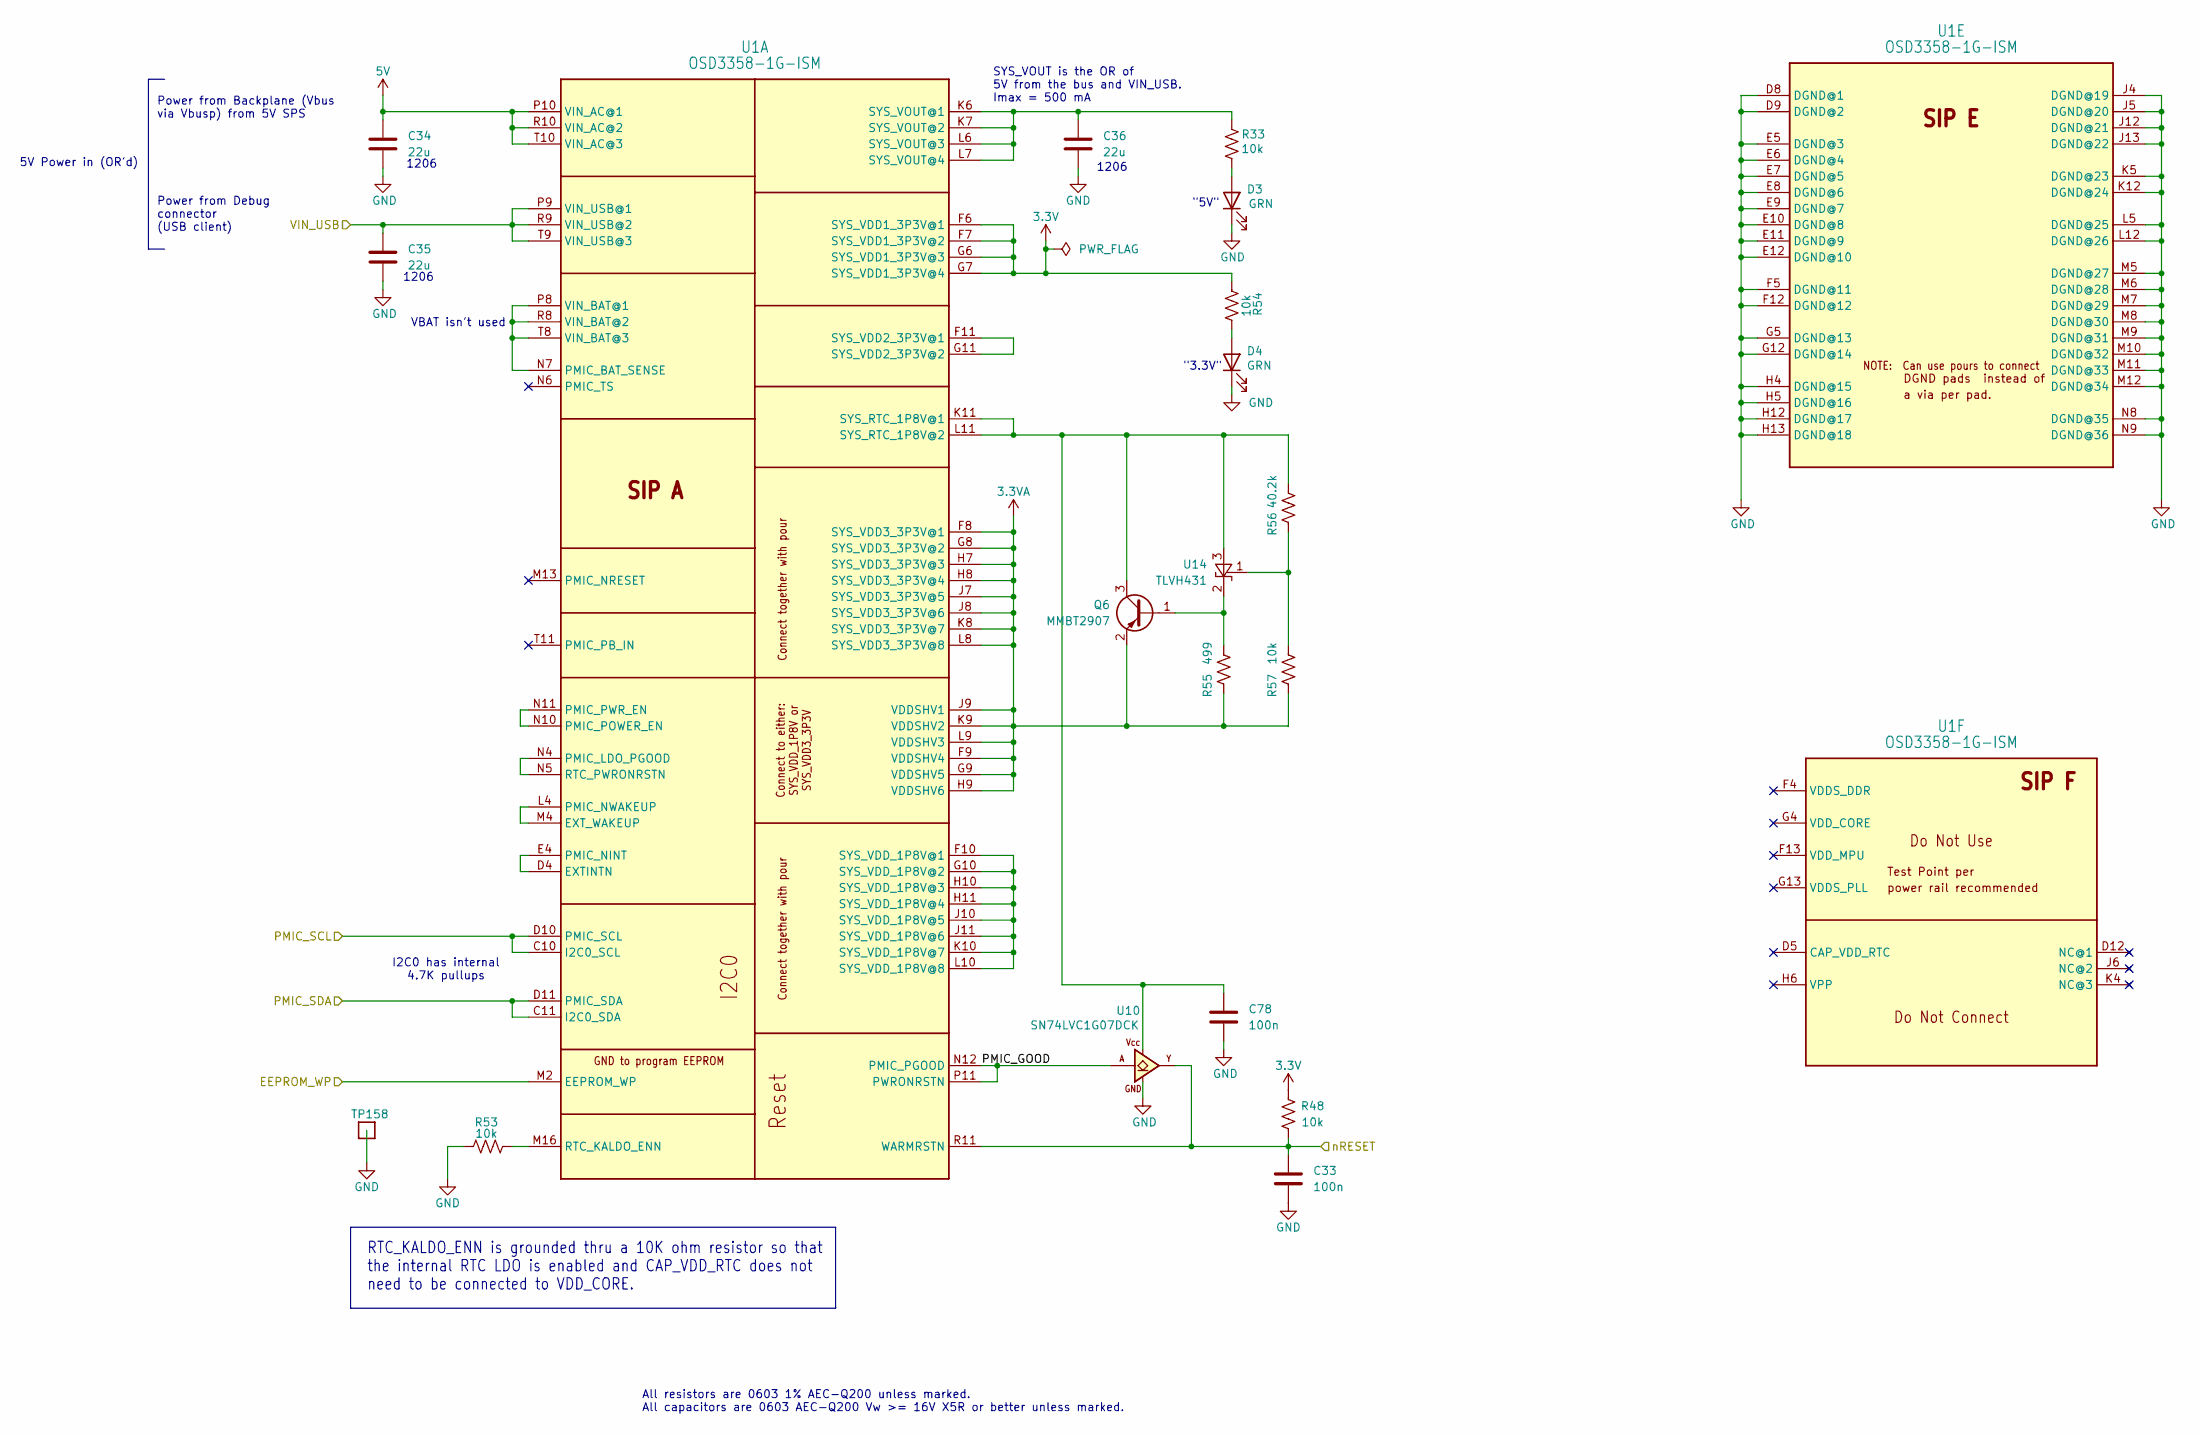
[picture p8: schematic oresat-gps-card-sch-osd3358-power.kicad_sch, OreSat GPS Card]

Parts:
C33, C78: 100n; 0603-C-NOSILK; MPN C0603C104K5RACAUTO
C34, C35, C36: 22u; C_1206_3216Metric; MPN GRT31CC81C226KE01L
D3, D4: GRN; LED_0603_1608Metric; MPN 150060GS75000
Q6: MMBT2907; SOT23; MPN PMBT2907,215
R33, R48, R53, R54, R57: 10k; 0603-C-NOSILK; MPN RMCF0603FT10K0
R55: 499; 0603-C-NOSILK; MPN RMCF0603FT499R
R56: 40.2k; 0603-C-NOSILK; MPN RMCF0603FT40K2
TP158: Test-Point; TestPoint-0.75mm-th
U1: OSD3358-1G-ISM; U-Octavo-OSD335X-BGA-256; MPN OSD3358-1G-ISM
U10: SN74LVC1G07DCK; SOT-353_SC-70-5; MPN SN74LVC1G07DCKR
U14: TLVH431; SOT-23; MPN TLVH431AQDBZR

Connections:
3.3V: R48.2, R54.1, U1.F6 (SYS_VDD1_3P3V@1), U1.F7 (SYS_VDD1_3P3V@2), U1.G6 (SYS_VDD1_3P3V@3), U1.G7 (SYS_VDD1_3P3V@4); also elsewhere on the board
3.3VA: Q6.2 (E), R55.1, R57.1, U1.F8 (SYS_VDD3_3P3V@1), U1.F9 (VDDSHV4), U1.G8 (SYS_VDD3_3P3V@2), U1.G9 (VDDSHV5), U1.H7 (SYS_VDD3_3P3V@3), U1.H8 (SYS_VDD3_3P3V@4), U1.H9 (VDDSHV6), U1.J7 (SYS_VDD3_3P3V@5), U1.J8 (SYS_VDD3_3P3V@6), U1.J9 (VDDSHV1), U1.K8 (SYS_VDD3_3P3V@7), U1.K9 (VDDSHV2), U1.L8 (SYS_VDD3_3P3V@8), U1.L9 (VDDSHV3)
5V: C34.1, U1.P10 (VIN_AC@1), U1.R10 (VIN_AC@2), U1.T10 (VIN_AC@3); also elsewhere on the board
/EEPROM_WP: U1.M2 (EEPROM_WP); also elsewhere on the board
/OSD3358 PWR, ETC. : SIP A, E, F/PMIC_GOOD: U1.N12 (PMIC_PGOOD), U1.P11 (PWRONRSTN), U10.2 (A)
/OSD3358 PWR, ETC. : SIP A, E, F/VIN_USB: C35.1, U1.P9 (VIN_USB@1), U1.R9 (VIN_USB@2), U1.T9 (VIN_USB@3); also elsewhere on the board
/PMIC_SCL: U1.C10 (I2C0_SCL), U1.D10 (PMIC_SCL); also elsewhere on the board
/PMIC_SDA: U1.C11 (I2C0_SDA), U1.D11 (PMIC_SDA); also elsewhere on the board
/nRESET: C33.1, R48.1, U1.R11 (WARMRSTN), U10.4 (Y); also elsewhere on the board
GND: C33.2, C34.2, C35.2, C36.2, C78.2, D3.1 (K), D4.1 (K), R53.1, TP158.1 (1_1), U1.D8 (DGND@1), U1.D9 (DGND@2), U1.E5 (DGND@3), U1.E6 (DGND@4), U1.E7 (DGND@5), U1.E8 (DGND@6), U1.E9 (DGND@7), U1.E10 (DGND@8), U1.E11 (DGND@9), U1.E12 (DGND@10), U1.F5 (DGND@11), U1.F12 (DGND@12), U1.G5 (DGND@13), U1.G12 (DGND@14), U1.H4 (DGND@15), U1.H5 (DGND@16), U1.H12 (DGND@17), U1.H13 (DGND@18), U1.J4 (DGND@19), U1.J5 (DGND@20), U1.J12 (DGND@21), U1.J13 (DGND@22), U1.K5 (DGND@23), U1.K12 (DGND@24), U1.L5 (DGND@25), U1.L12 (DGND@26), U1.M5 (DGND@27), U1.M6 (DGND@28), U1.M7 (DGND@29), U1.M8 (DGND@30), U1.M9 (DGND@31), U1.M10 (DGND@32), U1.M11 (DGND@33), U1.M12 (DGND@34), U1.N8 (DGND@35), U1.N9 (DGND@36), U10.3 (GND); also elsewhere on the board
unnamed: D3.2 (A), R33.1
unnamed: D4.2 (A), R54.2
unnamed: Q6.1 (B), R55.2, U14.2 (K)
unnamed: C78.1, Q6.3 (C), R56.2, U1.K11 (SYS_RTC_1P8V@1), U1.L11 (SYS_RTC_1P8V@2), U10.5 (VCC), U14.3 (A)
unnamed: U1.D4 (EXTINTN), U1.E4 (PMIC_NINT)
unnamed: U1.L4 (PMIC_NWAKEUP), U1.M4 (EXT_WAKEUP)
unnamed: U1.N7 (PMIC_BAT_SENSE), U1.P8 (VIN_BAT@1), U1.R8 (VIN_BAT@2), U1.T8 (VIN_BAT@3)
unnamed: U1.N4 (PMIC_LDO_PGOOD), U1.N5 (RTC_PWRONRSTN)
unnamed: U1.N10 (PMIC_POWER_EN), U1.N11 (PMIC_PWR_EN)
unnamed: R53.2, U1.M16 (RTC_KALDO_ENN)
unnamed: U1.F11 (SYS_VDD2_3P3V@1), U1.G11 (SYS_VDD2_3P3V@2)
unnamed: U1.F10 (SYS_VDD_1P8V@1), U1.G10 (SYS_VDD_1P8V@2), U1.H10 (SYS_VDD_1P8V@3), U1.H11 (SYS_VDD_1P8V@4), U1.J10 (SYS_VDD_1P8V@5), U1.J11 (SYS_VDD_1P8V@6), U1.K10 (SYS_VDD_1P8V@7), U1.L10 (SYS_VDD_1P8V@8)
unnamed: C36.1, R33.2, U1.K6 (SYS_VOUT@1), U1.K7 (SYS_VOUT@2), U1.L6 (SYS_VOUT@3), U1.L7 (SYS_VOUT@4)
unnamed: R56.1, R57.2, U14.1 (REF)

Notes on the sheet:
Power from Debug connector (USB client)
"3.3V"
5V Power in (OR'd)
1206
I2C0 has internal 4.7K pullups
SYS_VOUT is the OR of 5V from the bus and VIN_USB. Imax = 500 mA
All resistors are 0603 1% AEC-Q200 unless marked. All capacitors are 0603 AEC-Q200 Vw >= 16V X5R or better unless marked.
VBAT isn't used
"5V"
RTC_KALDO_ENN is grounded thru a 10K ohm resistor so that the internal RTC LDO is enabled and CAP_VDD_RTC does not need to be connected to VDD_CORE.
Power from Backplane (Vbus via Vbusp) from 5V SPS

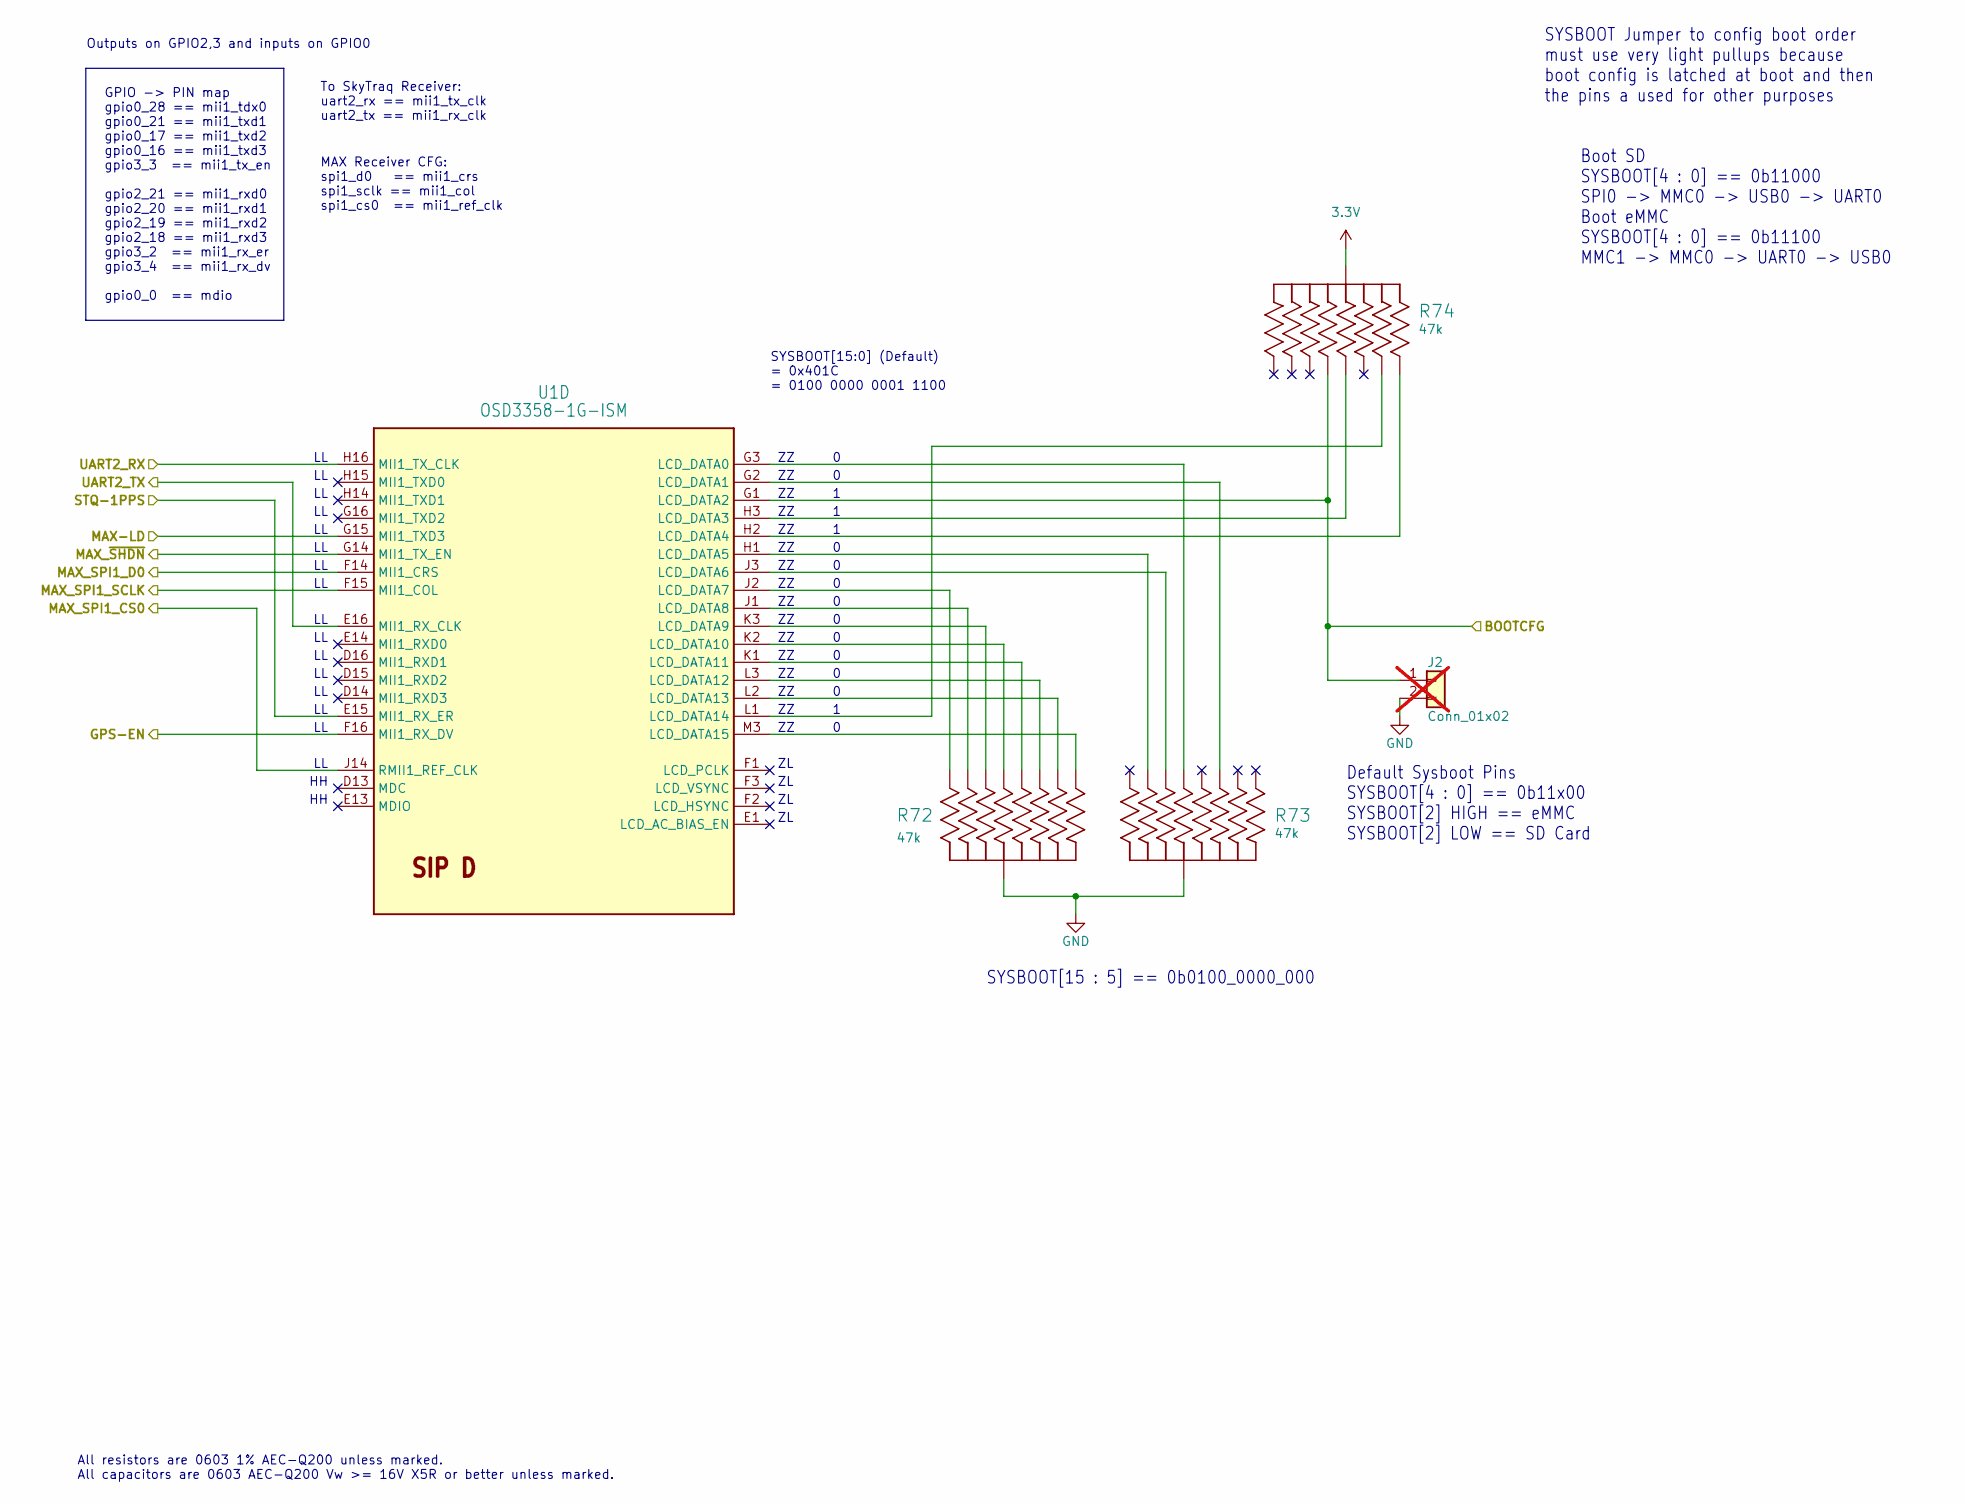
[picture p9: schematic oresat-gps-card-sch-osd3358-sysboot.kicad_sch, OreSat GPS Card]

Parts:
J2: Conn_01x02; PinHeader_1x02_P2.54mm_Vertical; not fitted
R72, R73, R74: 47k; Panasonic_Resistor_Array_EXBA10; MPN EXB-A10P473J
U1: OSD3358-1G-ISM; U-Octavo-OSD335X-BGA-256; MPN OSD3358-1G-ISM

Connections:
3.3V: R74.5 (55), R74.10 (55); also elsewhere on the board
/MAX2769/MAX-LD: U1.G15 (MII1_TXD3); also elsewhere on the board
/MAX2769/MAX_SPI1_CS0: U1.J14 (RMII1_REF_CLK); also elsewhere on the board
/MAX2769/MAX_SPI1_D0: U1.F14 (MII1_CRS); also elsewhere on the board
/MAX2769/MAX_SPI1_SCLK: U1.F15 (MII1_COL); also elsewhere on the board
/MAX2769/MAX_~SHDN: U1.G14 (MII1_TX_EN); also elsewhere on the board
/OSD3358 SYSBOOT : SIP D/BOOTCFG: J2.1, R74.8 (88), U1.G1 (LCD_DATA2); also elsewhere on the board
/OSD3358 SYSBOOT : SIP D/GPS-EN: U1.F16 (MII1_RX_DV); also elsewhere on the board
/OSD3358 SYSBOOT : SIP D/STQ-1PPS: U1.E15 (MII1_RX_ER); also elsewhere on the board
/OSD3358 SYSBOOT : SIP D/UART2_RX: U1.H16 (MII1_TX_CLK); also elsewhere on the board
/OSD3358 SYSBOOT : SIP D/UART2_TX: U1.E16 (MII1_RX_CLK); also elsewhere on the board
GND: J2.2, R72.5 (55), R72.10 (55), R73.5 (55), R73.10 (55); also elsewhere on the board
unnamed: R72.1 (11), U1.M3 (LCD_DATA15)
unnamed: R72.2 (22), U1.L3 (LCD_DATA12)
unnamed: R72.3 (33), U1.K2 (LCD_DATA10)
unnamed: R72.4 (44), U1.J1 (LCD_DATA8)
unnamed: R72.6 (66), U1.J2 (LCD_DATA7)
unnamed: R72.7 (77), U1.K3 (LCD_DATA9)
unnamed: R72.8 (88), U1.K1 (LCD_DATA11)
unnamed: R72.9 (99), U1.L2 (LCD_DATA13)
unnamed: R73.2 (22), U1.G2 (LCD_DATA1)
unnamed: R73.3 (33), U1.G3 (LCD_DATA0)
unnamed: R73.4 (44), U1.H1 (LCD_DATA5)
unnamed: R73.7 (77), U1.J3 (LCD_DATA6)
unnamed: R74.3 (33), U1.H3 (LCD_DATA3)
unnamed: R74.4 (44), U1.L1 (LCD_DATA14)
unnamed: R74.6 (66), U1.H2 (LCD_DATA4)

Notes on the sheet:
All resistors are 0603 1% AEC-Q200 unless marked. All capacitors are 0603 AEC-Q200 Vw >= 16V X5R or better unless marked.
Default Sysboot Pins SYSBOOT[4 : 0] == 0b11x00 SYSBOOT[2] HIGH == eMMC SYSBOOT[2] LOW == SD Card
Outputs on GPIO2,3 and inputs on GPIO0
Boot SD SYSBOOT[4 : 0] == 0b11000 SPI0 -> MMC0 -> USB0 -> UART0 Boot eMMC SYSBOOT[4 : 0] == 0b11100 MMC1 -> MMC0 -> UART0 -> USB0
To SkyTraq Receiver: uart2_rx == mii1_tx_clk uart2_tx == mii1_rx_clk
SYSBOOT Jumper to config boot order must use very light pullups because boot config is latched at boot and then the pins a used for other purposes
MAX Receiver CFG: spi1_d0 == mii1_crs spi1_sclk == mii1_col spi1_cs0 == mii1_ref_clk
SYSBOOT[15:0] (Default) = 0x401C = 0100 0000 0001 1100
SYSBOOT[15 : 5] == 0b0100_0000_000
GPIO -> PIN map gpio0_28 == mii1_tdx0 gpio0_21 == mii1_txd1 gpio0_17 == mii1_txd2 gpio0_16 == mii1_txd3 gpio3_3 == mii1_tx_en gpio2_21 == mii1_rxd0 gpio2_20 == mii1_rxd1 gpio2_19 == mii1_rxd2 gpio2_18 == mii1_rxd3 gpio3_2 == mii1_rx_er gpio3_4 == mii1_rx_dv gpio0_0 == mdio

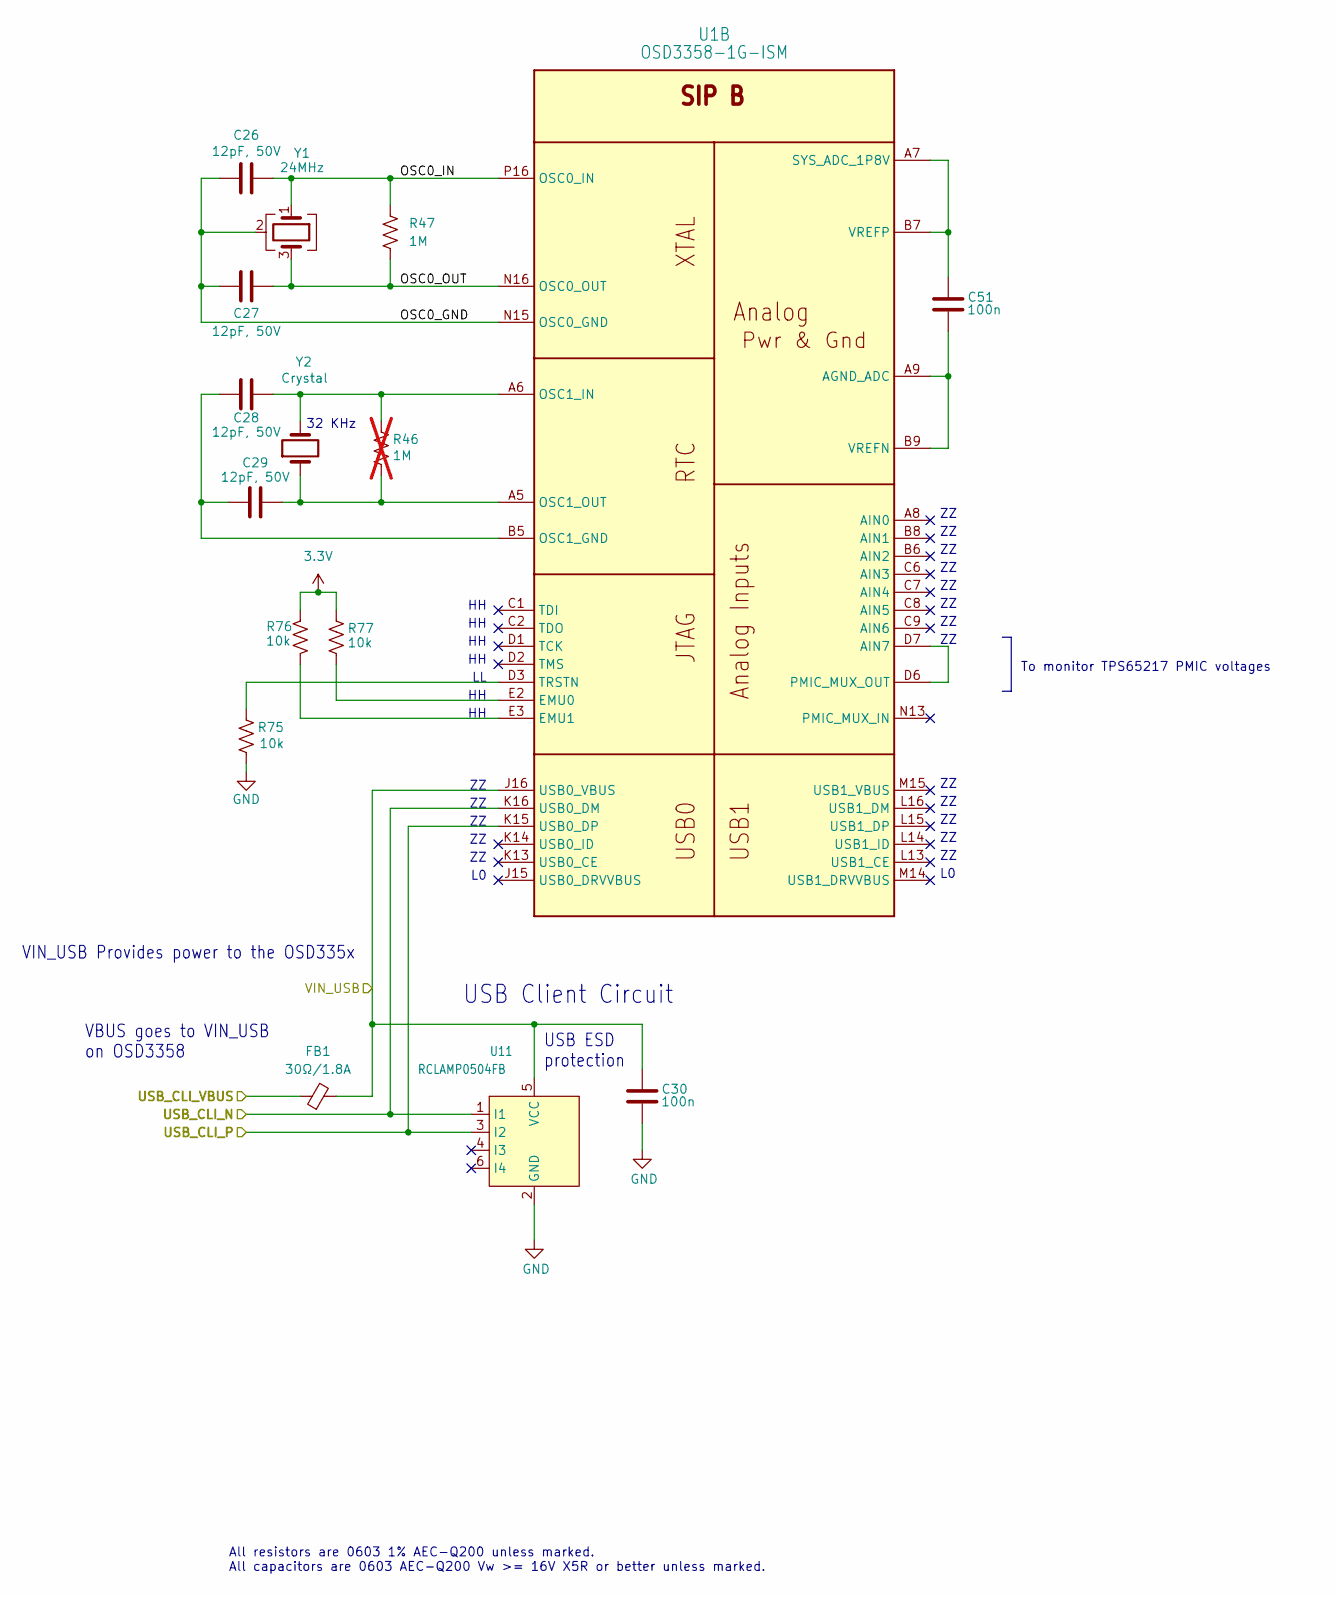
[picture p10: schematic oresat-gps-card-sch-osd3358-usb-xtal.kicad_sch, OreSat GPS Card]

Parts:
C26, C27, C28, C29: 12pF, 50V; 0603-C-NOSILK; MPN GRM1885C1H120JA01D
C30, C51: 100n; 0603-C-NOSILK; MPN C0603C104K5RACAUTO
FB1: 30Ω/1.8A; L_0603_1608Metric; MPN BLM18KG300JH1D
R46: 1M; R_0603_1608Metric; not fitted
R47: 1M; 0603-C-NOSILK; MPN RMCF0603FT1M00
R75, R76, R77: 10k; 0603-C-NOSILK; MPN RMCF0603FT10K0
U1: OSD3358-1G-ISM; U-Octavo-OSD335X-BGA-256; MPN OSD3358-1G-ISM
U11: RCLAMP0504FB; SOT-363_SC-70-6; MPN RCLAMP0504FBTCT
Y1: 24MHz; CRYSTAL-5X3.2-4SMD; MPN ECS-240-12-30BQ-AEN-TR
Y2: Crystal; CRYSTAL_3.2X1.5; MPN ABS07-32.768KHZ-T

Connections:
3.3V: R76.1, R77.1; also elsewhere on the board
/OSD3358 PWR, ETC. : SIP A, E, F/VIN_USB: C30.2, FB1.2, U1.J16 (USB0_VBUS), U11.5 (VCC); also elsewhere on the board
/OSD3358 USB, XTAL, etc : SIP B/OSC0_GND: C26.1, C27.1, U1.N15 (OSC0_GND), Y1.2 (G), Y1.4 (G)
/OSD3358 USB, XTAL, etc : SIP B/OSC0_IN: C26.2, R47.1, U1.P16 (OSC0_IN), Y1.1
/OSD3358 USB, XTAL, etc : SIP B/OSC0_OUT: C27.2, R47.2, U1.N16 (OSC0_OUT), Y1.3
/USB_CLI_N: U1.K16 (USB0_DM), U11.1 (I1); also elsewhere on the board
/USB_CLI_P: U1.K15 (USB0_DP), U11.3 (I2); also elsewhere on the board
/USB_CLI_VBUS: FB1.1; also elsewhere on the board
GND: C30.1, R75.2, U11.2 (GND); also elsewhere on the board
unnamed: C51.1, U1.A9 (AGND_ADC), U1.B9 (VREFN)
unnamed: U1.D6 (PMIC_MUX_OUT), U1.D7 (AIN7)
unnamed: R77.2, U1.E2 (EMU0)
unnamed: R76.2, U1.E3 (EMU1)
unnamed: C28.1, C29.1, U1.B5 (OSC1_GND)
unnamed: C28.2, R46.1, U1.A6 (OSC1_IN), Y2.2
unnamed: C29.2, R46.2, U1.A5 (OSC1_OUT), Y2.1
unnamed: C51.2, U1.A7 (SYS_ADC_1P8V), U1.B7 (VREFP)
unnamed: R75.1, U1.D3 (TRSTN)

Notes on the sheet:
To monitor TPS65217 PMIC voltages
VBUS goes to VIN_USB on OSD3358
VIN_USB Provides power to the OSD335x
USB Client Circuit
32 KHz
USB ESD protection
All resistors are 0603 1% AEC-Q200 unless marked. All capacitors are 0603 AEC-Q200 Vw >= 16V X5R or better unless marked.

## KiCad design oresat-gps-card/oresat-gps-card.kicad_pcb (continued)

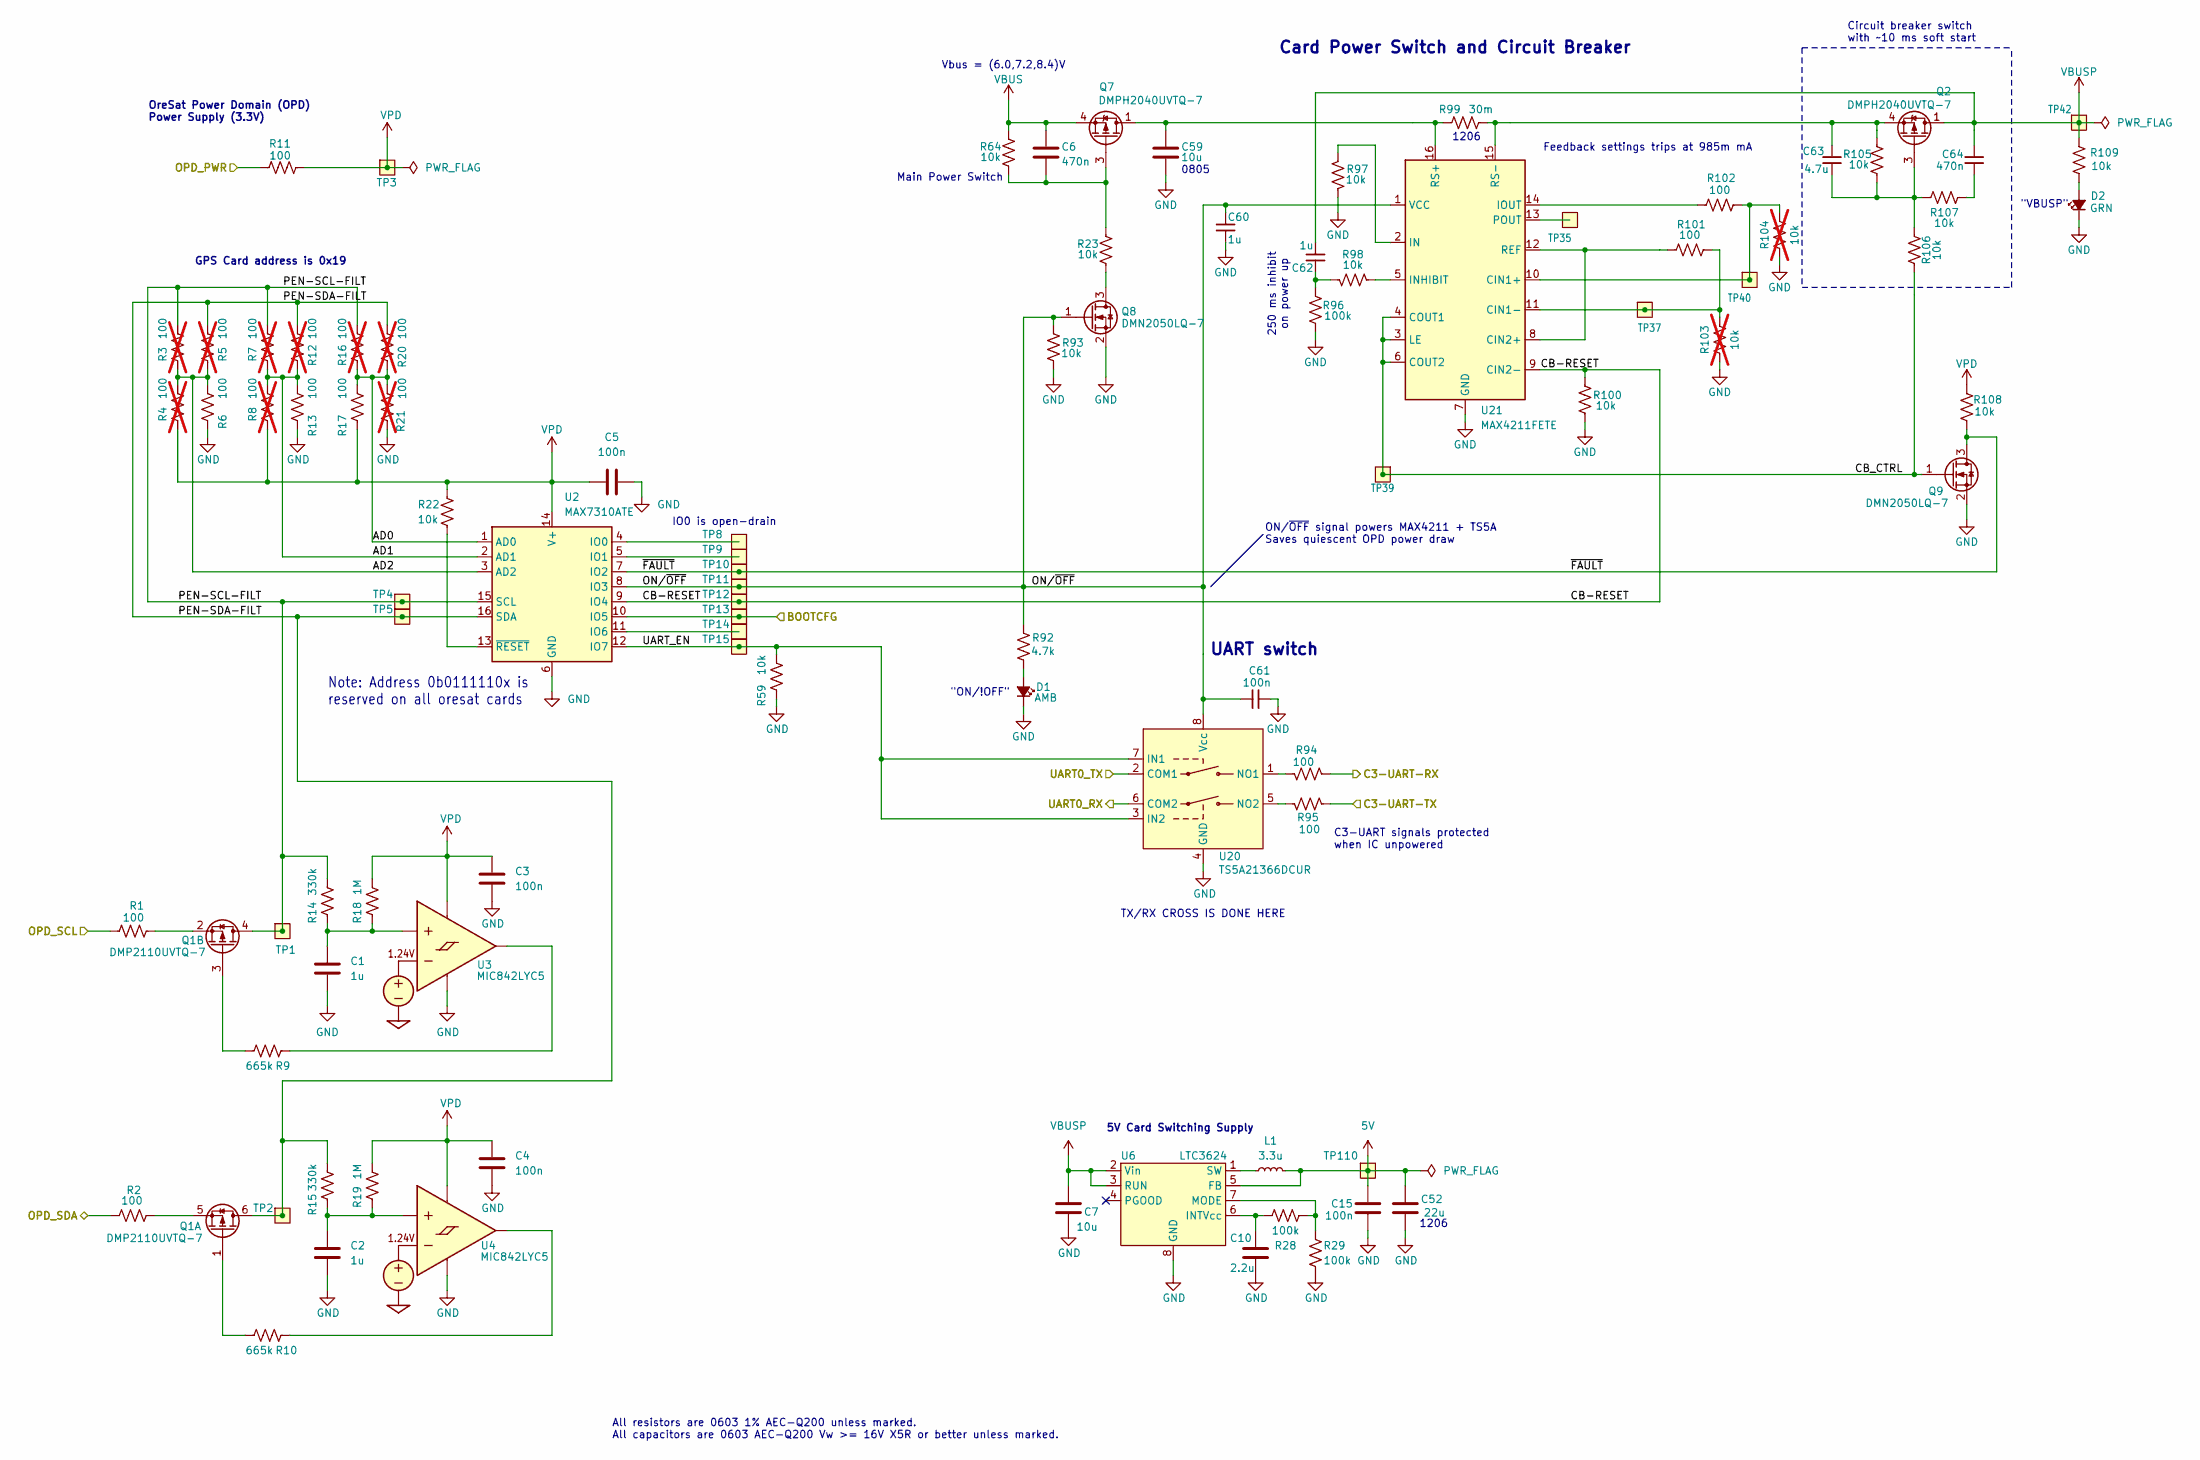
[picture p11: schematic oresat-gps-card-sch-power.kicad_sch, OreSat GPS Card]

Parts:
C1, C2, C60, C62: 1u; 0603-C-NOSILK; MPN GRT188R71E105KE13D
C3, C4, C5, C15, C61: 100n; 0603-C-NOSILK; MPN C0603C104K5RACAUTO
C6, C64: 470n; 0603-C-NOSILK; MPN C0603C474K3RACAUTO
C7: 10u; 0805-C-NOSILK; MPN GRT21BC71E106KE13K
C10: 2.2u; 0603-C-NOSILK; MPN GRT188C71E225KE13D
C52: 22u; C_1206_3216Metric; MPN GRT31CC81C226KE01L
C59: 10u; 0805-B-NOSILK; MPN GRT21BC71E106KE13K
C63: 4.7u; 0603-C-NOSILK; MPN GRT21BC71E475KE13L
D1: AMB; LED_0603_1608Metric; MPN 150060AS75000
D2: GRN; LED_0603_1608Metric; MPN 150060GS75000
L1: 3.3u; L_ECS-MPI4040; MPN ECS-MPIP0420-3R3MC
Q1: DMP2110UVTQ-7; SOT-23-6; MPN DMP2110UVTQ-7
Q2, Q7: DMPH2040UVTQ-7; TSOT-23-6; MPN DMPH2040UVTQ-7
Q8, Q9: DMN2050LQ-7; SOT-23; MPN DMN2050LQ-7
R1, R2, R6, R11, R13, R17, R94, R95, R101, R102: 100; 0603-C-NOSILK; MPN RMCF0603FT100R
R3, R4, R5, R7, R8, R12, R16, R20, R21: 100; 0603-C-NOSILK; not fitted
R9, R10: 665k; 0603-C-NOSILK; MPN RMCF0603FT665K
R14, R15: 330k; 0603-C-NOSILK; MPN RMCF0603FT330K
R18, R19: 1M; 0603-C-NOSILK; MPN RMCF0603FT1M00
R22, R23, R59, R64, R93, R97, R98, R100, R105, R106, R107, R108, R109: 10k; 0603-C-NOSILK; MPN RMCF0603FT10K0
R28, R29, R96: 100k; 0603-C-NOSILK; MPN RMCF0603FT100K
R92: 4.7k; 0603-C-NOSILK; MPN RMCF0603FT4K70
R99: 30m; 1206-C; MPN CSR1206FK30L0
R103, R104: 10k; 0603-C-NOSILK; MPN RMCF0603FT10K0; not fitted
TP1, TP2, TP3, TP4, TP5, TP8, TP9, TP10, TP11, TP12, TP13, TP14, TP15, TP35, TP37, TP39, TP40, TP42, TP110: Test-Point; TestPoint-0.75mm-th
U2: MAX7310ATE; QFN-16-1EP_4x4mm_P0.65mm_EP2.1x2.1mm; MPN MAX7310ATE+
U3, U4: MIC842LYC5; SOT-353_SC-70-5; MPN MIC842LYC5-TR
U6: LTC3624; DFN-8-1EP_3x3mm_P0.5mm_EP1.65x2.38mm_ThermalVias0.3mm; MPN LTC3624IDD-5#PBF
U20: TS5A21366DCUR; VSSOP-8_2.3x2mm_P0.5mm; MPN TS5A21366DCUR
U21: MAX4211FETE; QFN-16-1EP_4x4mm_P0.65mm_EP2.1x2.1mm; MPN MAX4211FETE

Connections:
5V: C15.1, C52.1, L1.2, TP110.1 (1_1), U6.5 (FB); also elsewhere on the board
/C3-UART-RX: R94.1; also elsewhere on the board
/C3-UART-TX: R95.1; also elsewhere on the board
/OPD_PWR: R11.1; also elsewhere on the board
/OPD_SCL: R1.1; also elsewhere on the board
/OPD_SDA: R2.1; also elsewhere on the board
/OSD3358 SYSBOOT : SIP D/BOOTCFG: TP13.1 (1_1), U2.10 (IO5); also elsewhere on the board
/Power/AD0: R16.2, R17.1, R20.2, R21.1, U2.1 (AD0)
/Power/AD1: R7.2, R8.1, R12.2, R13.1, U2.2 (AD1)
/Power/AD2: R3.2, R4.1, R5.2, R6.1, U2.3 (AD2)
/Power/CB-RESET: R100.2, TP12.1 (1_1), U2.9 (IO4), U21.9 (CIN2-)
/Power/CB_CTRL: Q9.1 (G), R106.1, TP39.1 (1_1), U21.3 (LE), U21.4 (COUT1), U21.6 (COUT2)
/Power/ON/~OFF: C60.1, C61.2, Q8.1 (G), R92.1, R93.2, TP11.1 (1_1), U2.8 (IO3), U20.8 (Vcc), U21.1 (VCC)
/Power/PEN-SCL-FILT: Q1.4 (D), R3.1, R7.1, R14.2, R16.1, TP1.1 (1_1), TP4.1 (1_1), U2.15 (SCL)
/Power/PEN-SDA-FILT: Q1.6 (D), R5.1, R12.1, R15.2, R20.1, TP2.1 (1_1), TP5.1 (1_1), U2.16 (SDA)
/Power/UART_EN: R59.2, TP15.1 (1_1), U2.12 (IO7), U20.3 (IN2), U20.7 (IN1)
/Power/~FAULT: Q9.3 (D), R108.1, TP10.1 (1_1), U2.7 (IO2)
/UART0_RX: U20.6 (COM2); also elsewhere on the board
/UART0_TX: U20.2 (COM1); also elsewhere on the board
GND: C1.1, C2.1, C3.1, C4.1, C5.2, C7.2, C10.2, C15.2, C52.2, C59.2, C60.2, C61.1, D1.1 (K), D2.1 (K), Q8.2 (S), Q9.2 (S), R6.2, R13.2, R21.2, R29.2, R59.1, R93.1, R96.1, R97.2, R100.1, R103.1, R104.1, U2.6 (GND), U2.17 (GND), U3.2 (GND), U4.2 (GND), U6.8 (GND), U6.9 (GND), U20.4 (GND), U21.7 (GND), U21.17 (GND); also elsewhere on the board
unnamed: C62.1, R96.2, R98.2
unnamed: C64.1, R107.1
unnamed: D1.2 (A), R92.2
unnamed: D2.2 (A), R109.1
unnamed: Q1.1 (G), R10.2
unnamed: Q1.5 (S), R2.2
unnamed: Q1.3 (G), R9.2
unnamed: Q1.2 (S), R1.2
unnamed: C63.1, Q2.3 (G), R105.1, R106.2, R107.2
unnamed: C63.2, Q2.4 (S), R99.2, R105.2, U21.15 (RS-)
unnamed: C6.2, Q7.3 (G), R23.2, R64.1
unnamed: Q8.3 (D), R23.1
unnamed: TP8.1 (1_1), U2.4 (IO0)
unnamed: TP9.1 (1_1), U2.5 (IO1)
unnamed: TP14.1 (1_1), U2.11 (IO6)
unnamed: R22.2, U2.13 (~RESET)
unnamed: C1.2, R14.1, R18.1, U3.1 (INP)
unnamed: R9.1, U3.4 (OUT)
unnamed: C2.2, R15.1, R19.1, U4.1 (INP)
unnamed: R10.1, U4.4 (OUT)
unnamed: C10.1, R28.1, U6.6 (INTVcc)
unnamed: R28.2, R29.1, U6.7 (MODE)
unnamed: L1.1, U6.1 (SW)
unnamed: R94.2, U20.1 (NO1)
unnamed: R95.2, U20.5 (NO2)
unnamed: R102.1, R104.2, TP40.1 (1_1), U21.10 (CIN1+)
unnamed: R101.1, R103.2, TP37.1 (1_1), U21.11 (CIN1-)
unnamed: R101.2, U21.8 (CIN2+), U21.12 (REF)
unnamed: R97.1, U21.2 (IN)
unnamed: R98.1, U21.5 (INHIBIT)
unnamed: R102.2, U21.14 (IOUT)
unnamed: TP35.1 (1_1), U21.13 (POUT)
unnamed: C59.1, Q7.1 (D), Q7.2 (D), Q7.5 (D), Q7.6 (D), R99.1, U21.16 (RS+)
VBUS: C6.1, Q7.4 (S), R64.2; also elsewhere on the board
VBUSP: C7.1, C62.2, C64.2, Q2.1 (D), Q2.2 (D), Q2.5 (D), Q2.6 (D), R109.2, TP42.1 (1_1), U6.2 (Vin), U6.3 (RUN)
VPD: C3.2, C4.2, C5.1, R4.2, R8.2, R11.2, R17.2, R18.2, R19.2, R22.1, R108.2, TP3.1 (1_1), U2.14 (V+), U3.5 (VDD), U4.5 (VDD)

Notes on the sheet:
Circuit breaker switch with ~10 ms soft start
Main Power Switch
5V Card Switching Supply
IO0 is open-drain
OreSat Power Domain (OPD) Power Supply (3.3V)
Feedback settings trips at 985m mA
TX/RX CROSS IS DONE HERE
"ON/!OFF"
1206
Vbus = (6.0,7.2,8.4)V
Note: Address 0b0111110x is reserved on all oresat cards
0805
GPS Card address is 0x19
C3-UART signals protected when IC unpowered
All resistors are 0603 1% AEC-Q200 unless marked. All capacitors are 0603 AEC-Q200 Vw >= 16V X5R or better unless marked.
"VBUSP"
Card Power Switch and Circuit Breaker
250 ms inhibit on power up
UART switch
ON/~{OFF} signal powers MAX4211 + TS5A Saves quiescent OPD power draw

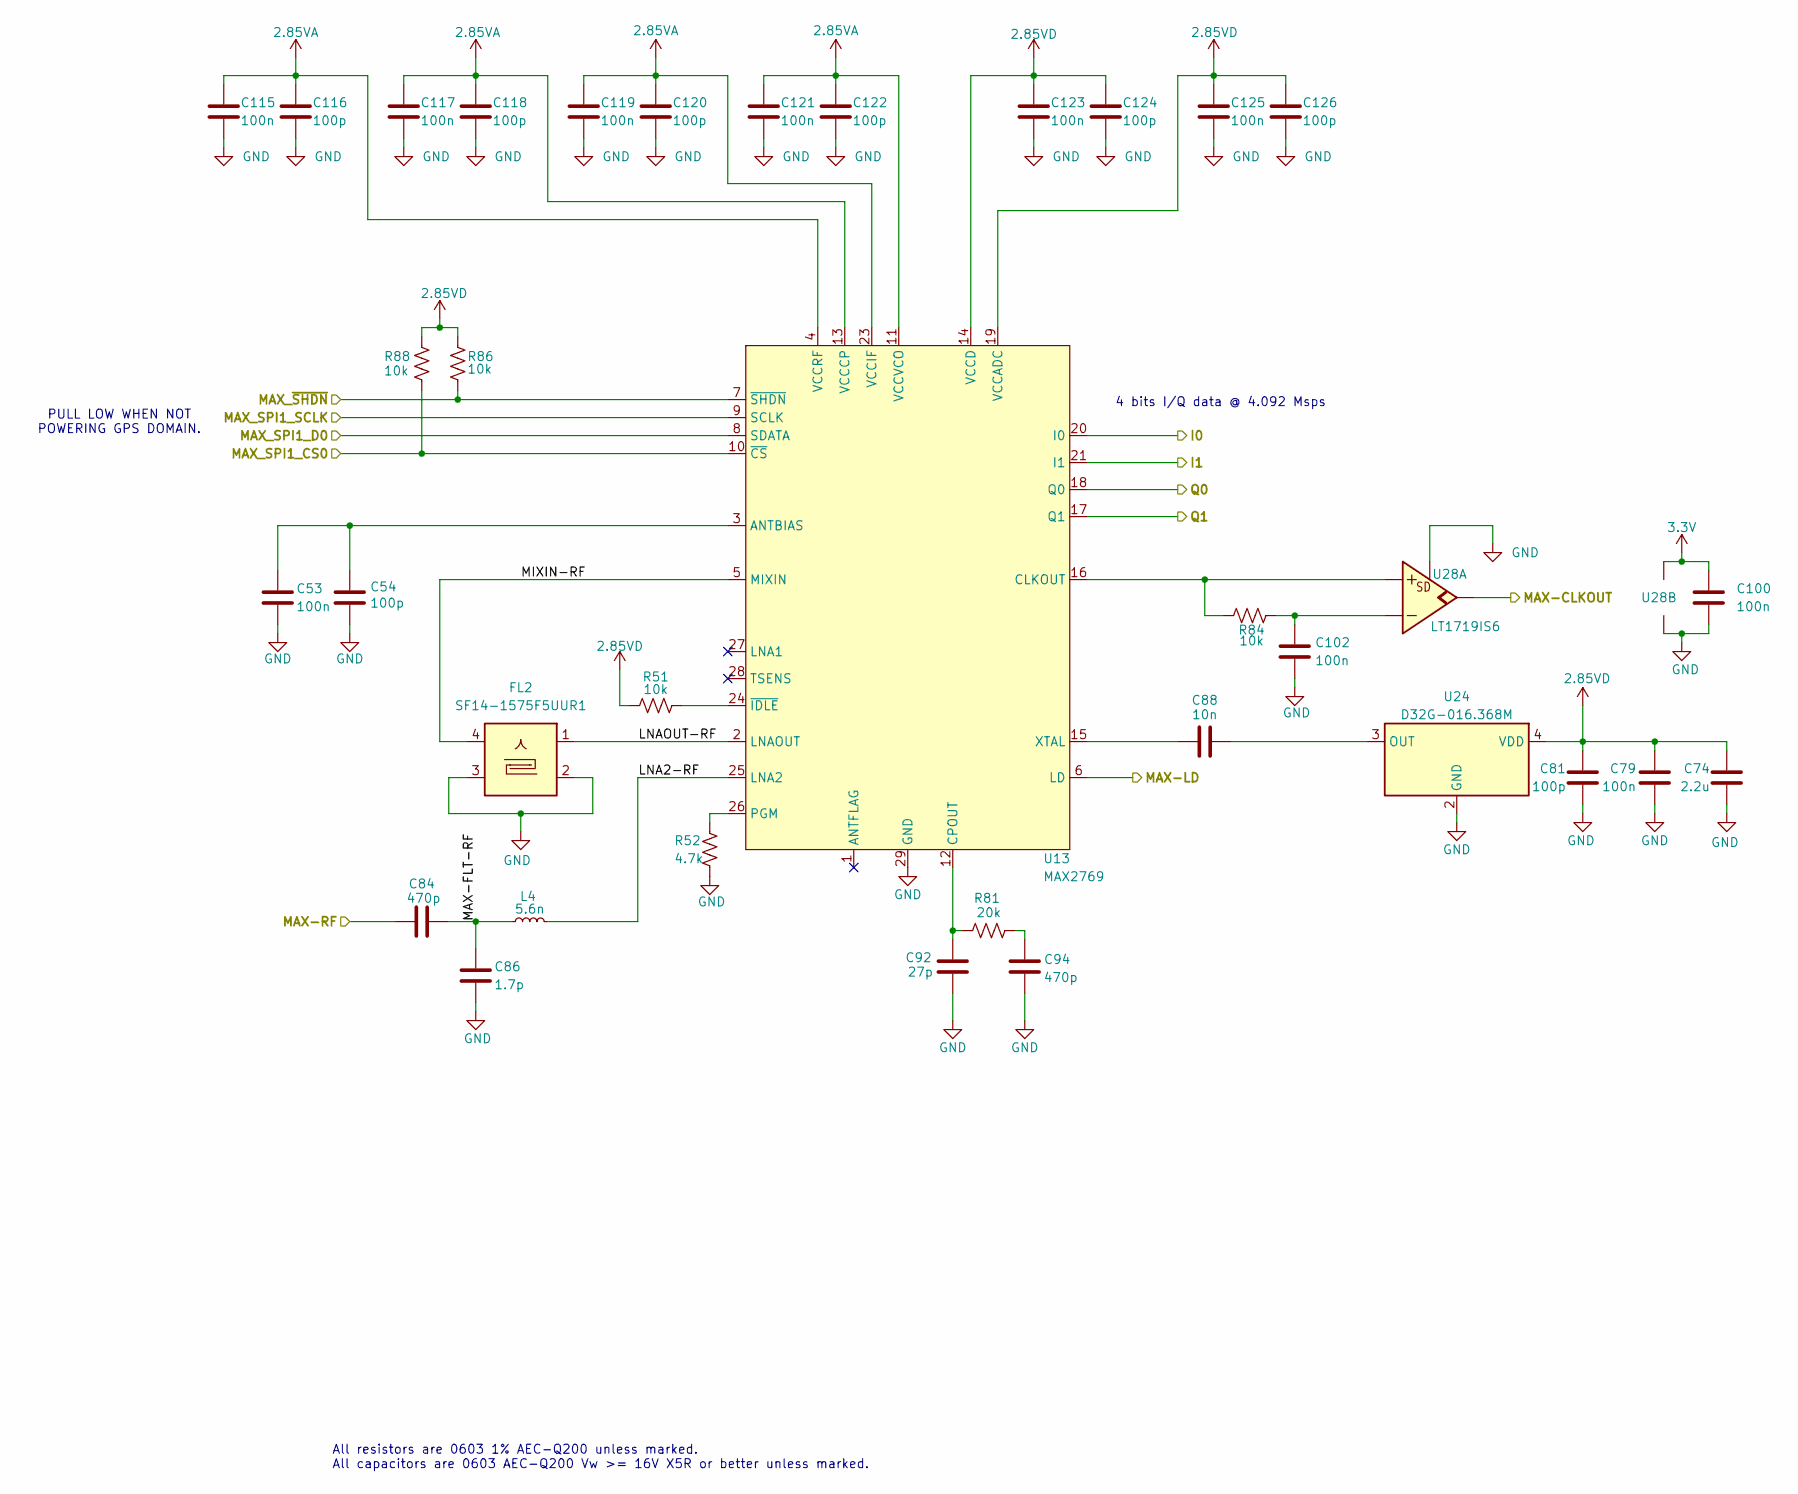
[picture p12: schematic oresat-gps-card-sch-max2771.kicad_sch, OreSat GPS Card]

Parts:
C53, C79, C100, C102, C115, C117, C119, C121, C123, C125: 100n; 0603-C-NOSILK; MPN C0603C104K5RACAUTO
C54, C81, C116, C118, C120, C122, C124, C126: 100p; 0603-C-NOSILK; MPN C0603C101K5HACAUTO
C74: 2.2u; 0603-C-NOSILK; MPN GRT188C71E225KE13D
C84, C94: 470p; 0603-C-NOSILK; MPN C0603C471K5RACAUTO
C86: 1.7p; 0603-C-NOSILK; MPN GRM1885C1H1R7BA01D
C88: 10n; 0603-C-NOSILK; MPN C0603C103J5RACAUTO
C92: 27p; 0603-C-NOSILK; MPN GCM1885C2A270JA16D
FL2: SF14-1575F5UUR1; Filter_1411-5_1.4x1.1mm; MPN SF14-1575F5UUR1
L4: 5.6n; 0603-C-NOSILK; MPN LQG18HN5N6S00D
R51, R84, R86, R88: 10k; 0603-C-NOSILK; MPN RMCF0603FT10K0
R52: 4.7k; 0603-C-NOSILK; MPN RMCF0603FT4K70
R81: 20k; 0603-C-NOSILK; MPN RMCF0603FT20K0
U13: MAX2769; TQFN-28-1EP_5x5mm_P0.5mm_EP3.25x3.25mm; MPN MAX2769BETI/V+T
U24: D32G-016.368M; U-Connor-Winfield-D32G-016368M; MPN D32G-016.368M
U28: LT1719IS6; SOT-23-6; MPN LT1719IS6#TRMPBF

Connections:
2.85VA: C115.1, C116.1, C117.1, C118.1, C119.1, C120.1, C121.1, C122.1, U13.4 (VCCRF), U13.11 (VCCVCO), U13.13 (VCCCP), U13.23 (VCCIF); also elsewhere on the board
2.85VD: C74.1, C79.1, C81.1, C123.1, C124.1, C125.1, C126.1, R51.1, R86.1, R88.2, U13.14 (VCCD), U13.19 (VCCADC), U24.4 (VDD); also elsewhere on the board
3.3V: C100.1, U28.4 (V+); also elsewhere on the board
/MAX2769/I0: U13.20 (I0); also elsewhere on the board
/MAX2769/I1: U13.21 (I1); also elsewhere on the board
/MAX2769/LNA2-RF: L4.2, U13.25 (LNA2)
/MAX2769/LNAOUT-RF: FL2.1, U13.2 (LNAOUT)
/MAX2769/MAX-CLKOUT: U28.5 (OUT); also elsewhere on the board
/MAX2769/MAX-FLT-RF: C84.2, C86.1, L4.1
/MAX2769/MAX-LD: U13.6 (LD); also elsewhere on the board
/MAX2769/MAX-RF: C84.1; also elsewhere on the board
/MAX2769/MAX_SPI1_CS0: R88.1, U13.10 (~CS); also elsewhere on the board
/MAX2769/MAX_SPI1_D0: U13.8 (SDATA); also elsewhere on the board
/MAX2769/MAX_SPI1_SCLK: U13.9 (SCLK); also elsewhere on the board
/MAX2769/MAX_~SHDN: R86.2, U13.7 (~SHDN); also elsewhere on the board
/MAX2769/MIXIN-RF: FL2.4, U13.5 (MIXIN)
/MAX2769/Q0: U13.18 (Q0); also elsewhere on the board
/MAX2769/Q1: U13.17 (Q1); also elsewhere on the board
GND: C53.2, C54.2, C74.2, C79.2, C81.2, C86.2, C92.1, C94.1, C100.2, C102.2, C115.2, C116.2, C117.2, C118.2, C119.2, C120.2, C121.2, C122.2, C123.2, C124.2, C125.2, C126.2, FL2.2, FL2.3, FL2.5, R52.2, U13.29 (GND), U24.2 (GND), U28.2 (V-), U28.6 (SD); also elsewhere on the board
unnamed: C94.2, R81.1
unnamed: C53.1, C54.1, U13.3 (ANTBIAS)
unnamed: R84.2, U13.16 (CLKOUT), U28.3 (+IN)
unnamed: C92.2, R81.2, U13.12 (CPOUT)
unnamed: R52.1, U13.26 (PGM)
unnamed: C88.2, U13.15 (XTAL)
unnamed: R51.2, U13.24 (~IDLE)
unnamed: C88.1, U24.3 (OUT)
unnamed: C102.1, R84.1, U28.1 (-IN)

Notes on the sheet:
All resistors are 0603 1% AEC-Q200 unless marked. All capacitors are 0603 AEC-Q200 Vw >= 16V X5R or better unless marked.
PULL LOW WHEN NOT POWERING GPS DOMAIN.
4 bits I/Q data @ 4.092 Msps

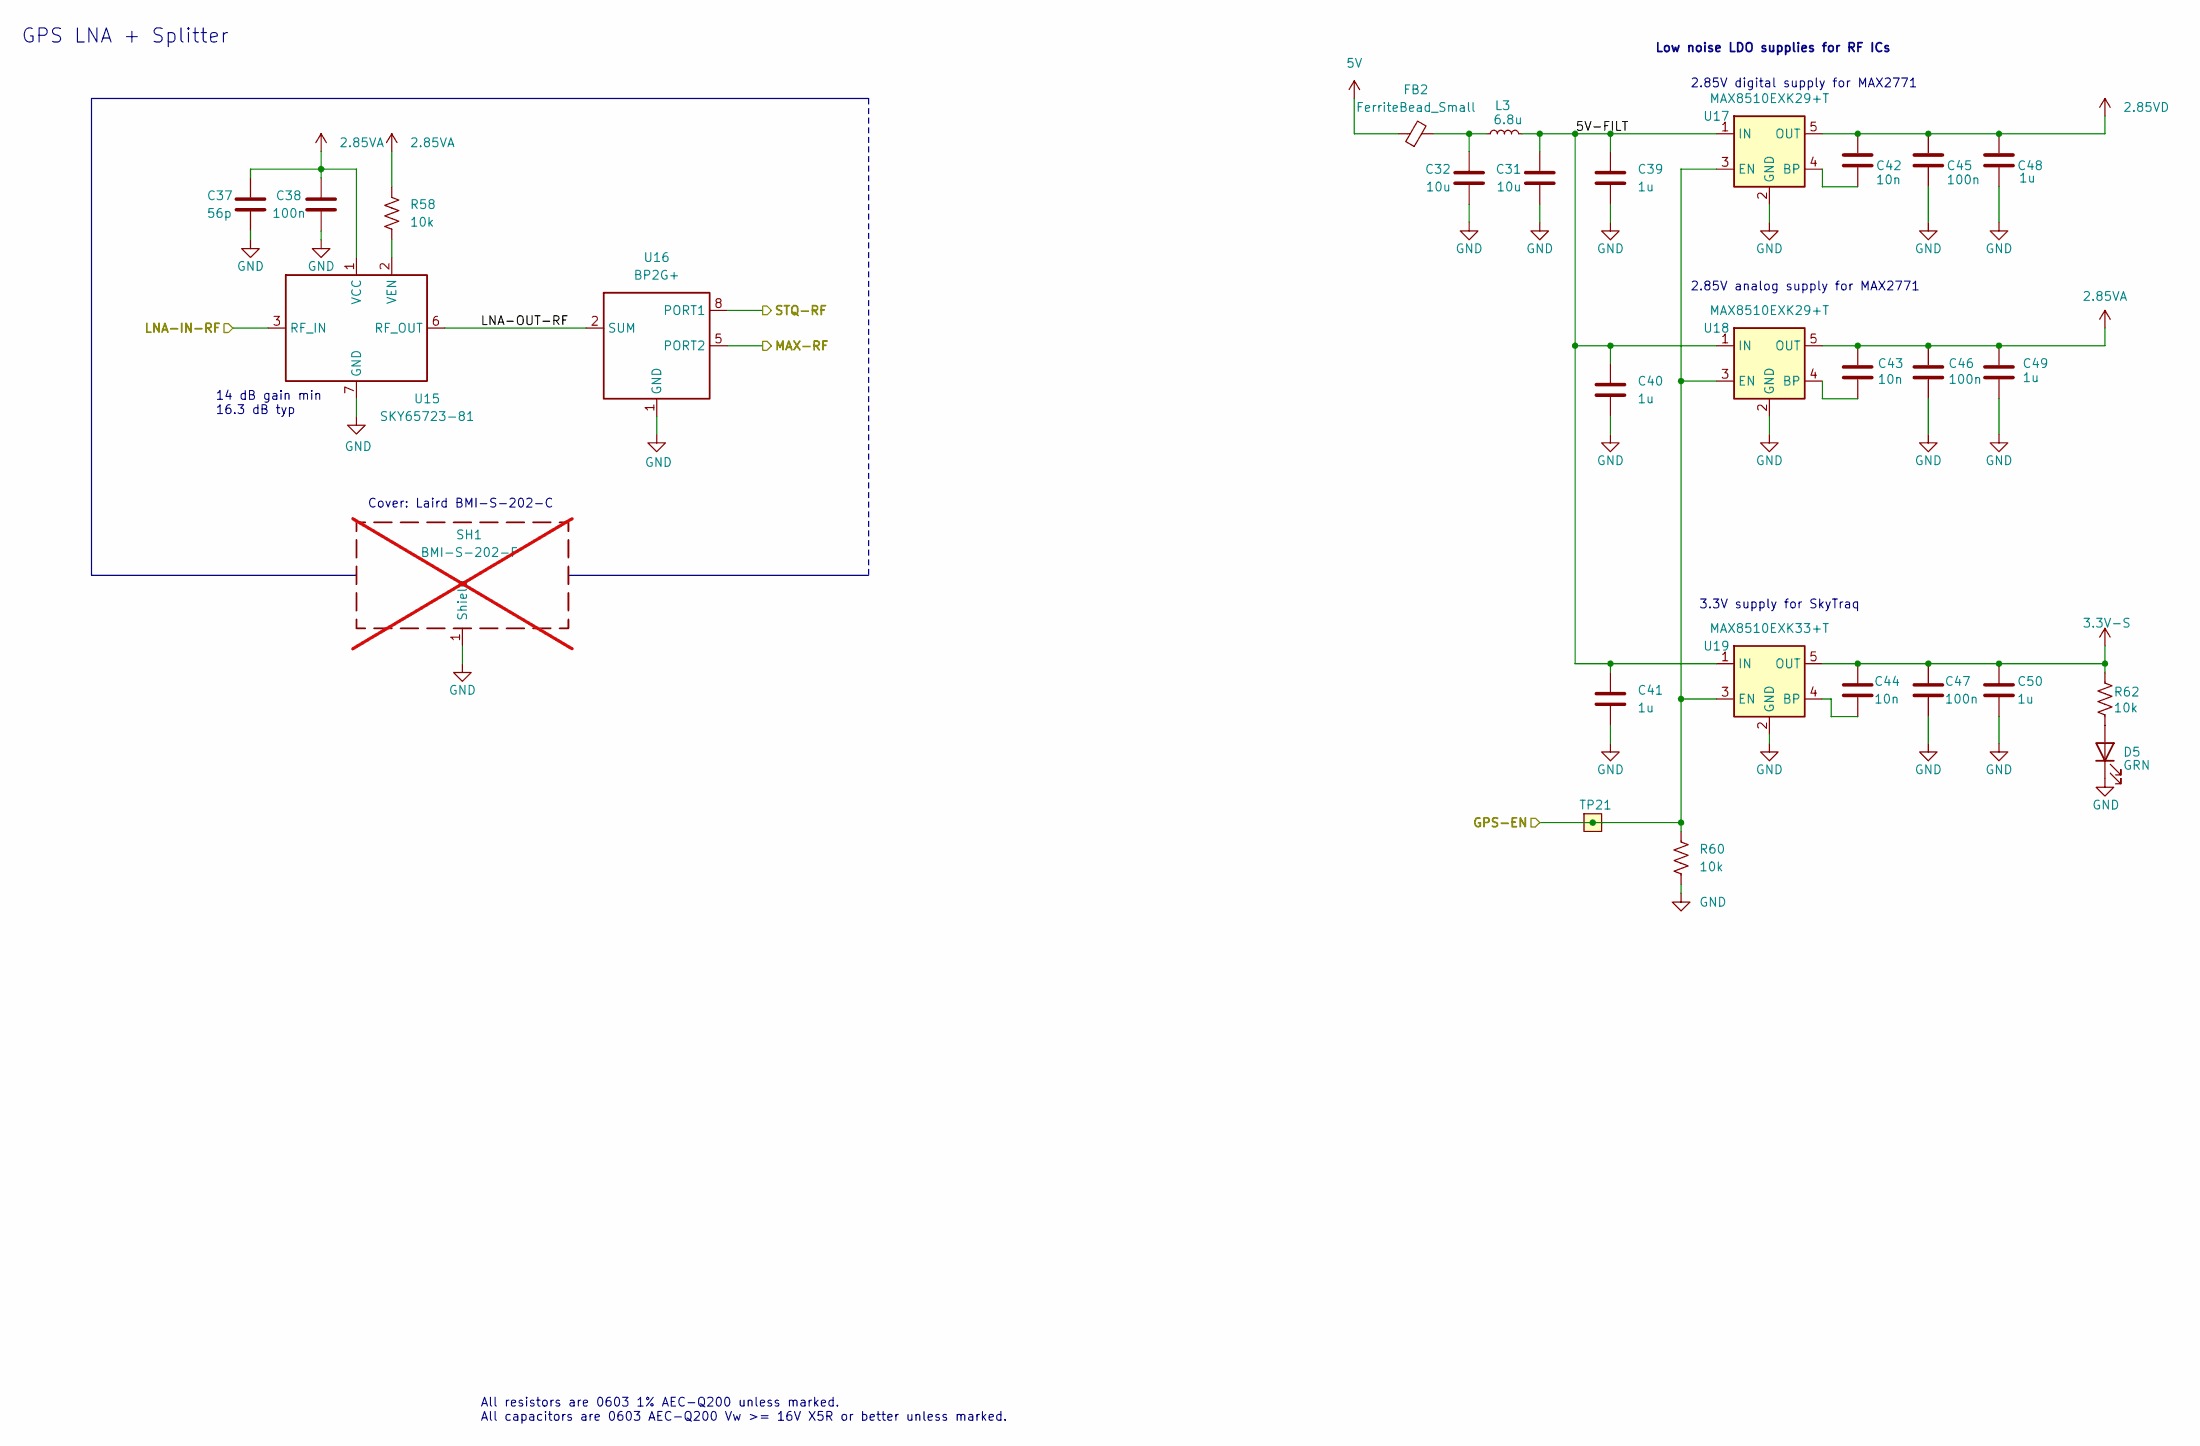
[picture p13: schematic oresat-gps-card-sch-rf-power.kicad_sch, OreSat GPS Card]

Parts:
C31, C32: 10u; 0805-C-NOSILK; MPN GRT21BC71E106KE13K
C37: 56p; 0603-C-NOSILK; MPN GRM1885C2A560JA01D
C38, C45, C46, C47: 100n; 0603-C-NOSILK; MPN C0603C104K5RACAUTO
C39, C40, C41, C48, C49, C50: 1u; 0603-C-NOSILK; MPN GRT188R71E105KE13D
C42, C43, C44: 10n; 0603-C-NOSILK; MPN C0603C103J5RACAUTO
D5: GRN; LED_0603_1608Metric; MPN 150060GS75000
FB2: FerriteBead_Small; 0805-C-NOSILK; MPN BLM21PG331SN1D
L3: 6.8u; L_ECS-MPI4040; MPN ECS-MPIP0420-6R8MC
R58, R60, R62: 10k; 0603-C-NOSILK; MPN RMCF0603FT10K0
SH1: BMI-S-202-F; Laird_Technologies_BMI-S-202-F_16.50x16.50mm; MPN BMI-S-202-F; not fitted
TP21: Test-Point; TestPoint-0.75mm-th
U15: SKY65723-81; U-Skyworks-SKY65723-81-gps-lna; MPN SKY65723-81
U16: BP2G+; U-Minicircuits-BP2G+; MPN BP2G1+
U17, U18: MAX8510EXK29+T; SOT-353_SC-70-5; MPN MAX8510EXK29+T
U19: MAX8510EXK33+T; SOT-353_SC-70-5; MPN MAX8510EXK33+T

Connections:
2.85VA: C37.1, C38.1, C43.1, C46.1, C49.1, R58.1, U15.1 (VCC), U18.5 (OUT); also elsewhere on the board
2.85VD: C42.1, C45.1, C48.1, U17.5 (OUT); also elsewhere on the board
3.3V-S: C44.1, C47.1, C50.1, R62.2, U19.5 (OUT); also elsewhere on the board
5V: FB2.1; also elsewhere on the board
/LNA-IN-RF: U15.3 (RF_IN); also elsewhere on the board
/MAX2769/MAX-RF: U16.5 (PORT2); also elsewhere on the board
/OSD3358 SYSBOOT : SIP D/GPS-EN: R60.1, TP21.1 (1_1), U17.3 (EN), U18.3 (EN), U19.3 (EN); also elsewhere on the board
/RF + RF Power/5V-FILT: C31.1, C39.1, C40.1, C41.1, L3.2, U17.1 (IN), U18.1 (IN), U19.1 (IN)
/RF + RF Power/LNA-OUT-RF: U15.6 (RF_OUT), U16.2 (SUM)
/RF + RF Power/STQ-RF: U16.8 (PORT1); also elsewhere on the board
GND: C31.2, C32.2, C37.2, C38.2, C39.2, C40.2, C41.2, C45.2, C46.2, C47.2, C48.2, C49.2, C50.2, D5.1 (K), R60.2, SH1.1 (Shield_1), U15.7 (GND), U16.1 (GND), U16.3 (GND), U16.4 (GND), U16.6 (GND), U16.7 (GND), U17.2 (GND), U18.2 (GND), U19.2 (GND); also elsewhere on the board
unnamed: C32.1, FB2.2, L3.1
unnamed: D5.2 (A), R62.1
unnamed: R58.2, U15.2 (VEN)
unnamed: C42.2, U17.4 (BP)
unnamed: C43.2, U18.4 (BP)
unnamed: C44.2, U19.4 (BP)

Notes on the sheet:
3.3V supply for SkyTraq
Cover: Laird BMI-S-202-C
All resistors are 0603 1% AEC-Q200 unless marked. All capacitors are 0603 AEC-Q200 Vw >= 16V X5R or better unless marked.
2.85V digital supply for MAX2771
Low noise LDO supplies for RF ICs
2.85V analog supply for MAX2771
14 dB gain min 16.3 dB typ
GPS LNA + Splitter

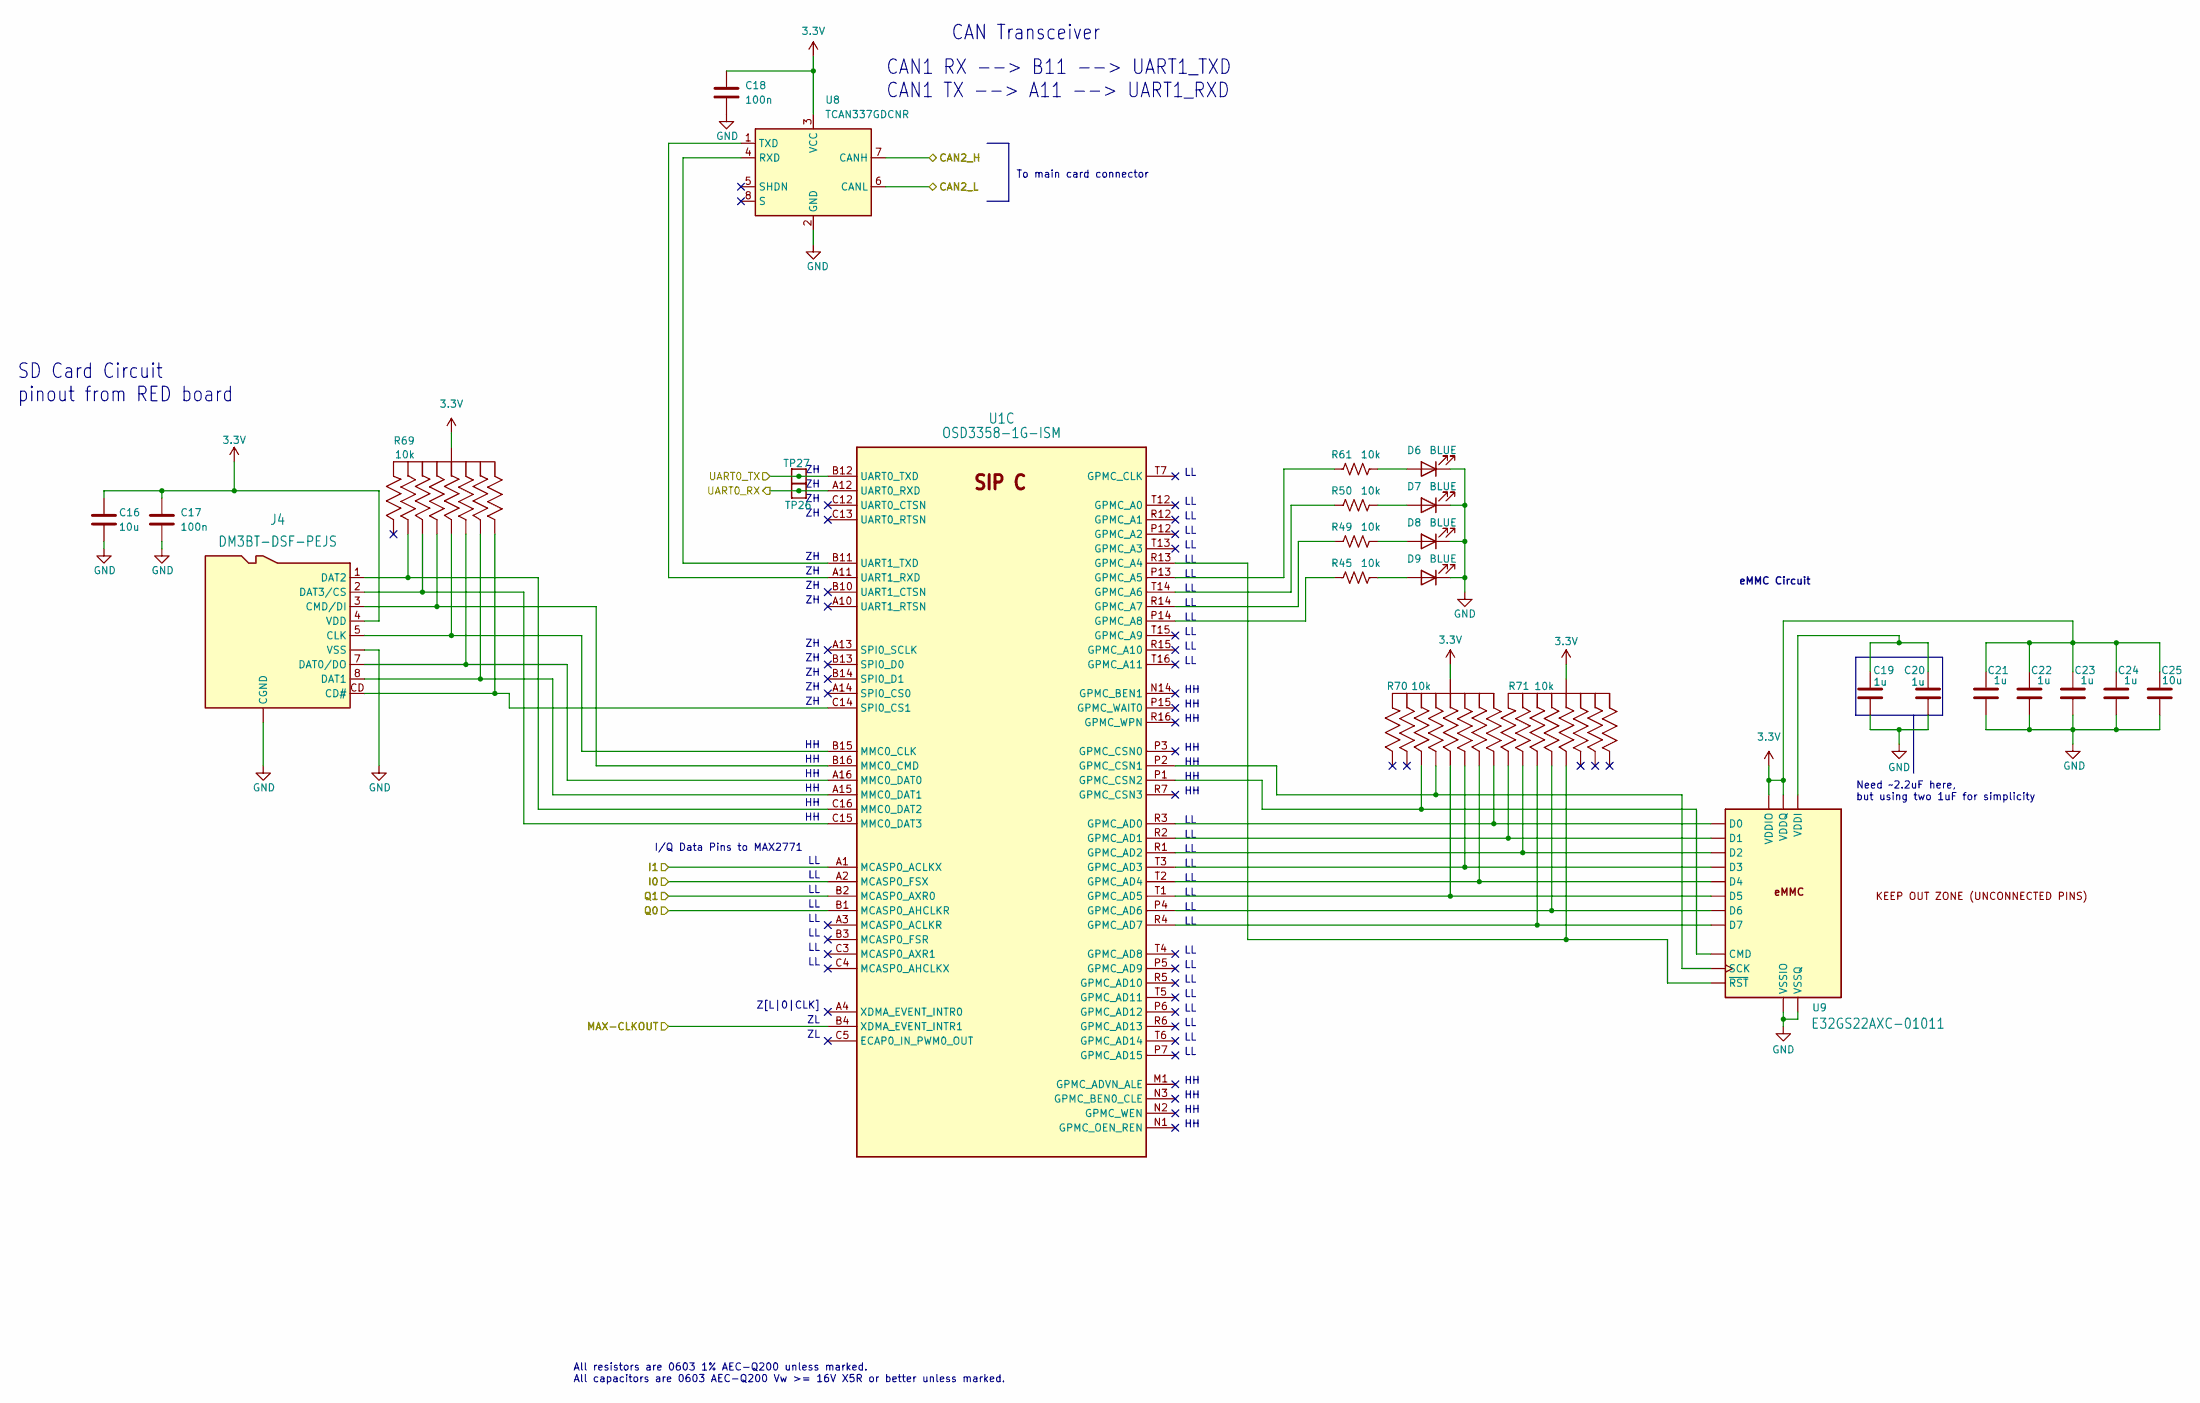
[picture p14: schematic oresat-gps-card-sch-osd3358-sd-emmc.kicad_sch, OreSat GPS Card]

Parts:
C16, C25: 10u; 0805-C-NOSILK; MPN GRT21BC71E106KE13K
C17, C18: 100n; 0603-C-NOSILK; MPN C0603C104K5RACAUTO
C19, C20, C21, C22, C23, C24: 1u; 0603-C-NOSILK; MPN GRT188R71E105KE13D
D6, D7, D8, D9: BLUE; LED_0603_1608Metric; MPN 150060BS75000
J4: DM3BT-DSF-PEJS; J-Hirose-DM3BT-DSF-PEJS; MPN DM3BT-DSF-PEJS
R45, R49, R50, R61: 10k; 0603-C-NOSILK; MPN RMCF0603FT10K0
R69, R70, R71: 10k; Panasonic_Resistor_Array_EXBA10; MPN EXB-A10P103J
TP26, TP27: Test-Point; TestPoint-0.75mm-th
U1: OSD3358-1G-ISM; U-Octavo-OSD335X-BGA-256; MPN OSD3358-1G-ISM
U8: TCAN337GDCNR; SOT-23-8; MPN TCAN337GDCNR
U9: E32GS22AXC-01011; BGA-153(11.5X13)(EMMC-BA); MPN E32GS22AXC-01011

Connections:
3.3V: C16.1, C17.1, C18.1, C21.1, C22.1, C23.1, C24.1, C25.1, J4.4 (VDD), R69.5 (55), R69.10 (55), R70.5 (55), R70.10 (55), R71.5 (55), R71.10 (55), U8.3 (VCC), U9.C6 (VDDQ), U9.E6 (VDDIO), U9.F5 (VDDIO), U9.J10 (VDDIO), U9.K9 (VDDIO), U9.M4 (VDDQ), U9.N4 (VDDQ), U9.P3 (VDDQ), U9.P5 (VDDQ); also elsewhere on the board
/CAN2_H: U8.7 (CANH); also elsewhere on the board
/CAN2_L: U8.6 (CANL); also elsewhere on the board
/MAX2769/I0: U1.A2 (MCASP0_FSX); also elsewhere on the board
/MAX2769/I1: U1.A1 (MCASP0_ACLKX); also elsewhere on the board
/MAX2769/MAX-CLKOUT: U1.B4 (XDMA_EVENT_INTR1); also elsewhere on the board
/MAX2769/Q0: U1.B1 (MCASP0_AHCLKR); also elsewhere on the board
/MAX2769/Q1: U1.B2 (MCASP0_AXR0); also elsewhere on the board
/UART0_RX: TP26.1 (1_1), U1.A12 (UART0_RXD); also elsewhere on the board
/UART0_TX: TP27.1 (1_1), U1.B12 (UART0_TXD); also elsewhere on the board
GND: C16.2, C17.2, C18.2, C19.2, C20.2, C21.2, C22.2, C23.2, C24.2, C25.2, D6.1 (K), D7.1 (K), D8.1 (K), D9.1 (K), J4.6 (VSS), J4.CGND1 (CGND), J4.CGND2 (CGND), J4.CGND3 (CGND), J4.CGND4 (CGND), J4.CGND5 (CGND), J4.CGND6 (CGND), J4.GND (VSS), U8.2 (GND), U9.A6 (VSSIO), U9.C4 (VSSQ), U9.E7 (VSSIO), U9.G5 (VSSIO), U9.H10 (VSSIO), U9.J5 (VSSIO), U9.K8 (VSSIO), U9.N2 (VSSQ), U9.N5 (VSSQ), U9.P4 (VSSQ), U9.P6 (VSSQ); also elsewhere on the board
unnamed: D6.2 (A), R61.2
unnamed: D7.2 (A), R50.2
unnamed: D8.2 (A), R49.2
unnamed: D9.2 (A), R45.2
unnamed: J4.CD (CD#), R69.6 (66), U1.C14 (SPI0_CS1)
unnamed: J4.5 (CLK), R69.3 (33), U1.B15 (MMC0_CLK)
unnamed: J4.3 (CMD/DI), R69.8 (88), U1.B16 (MMC0_CMD)
unnamed: J4.7 (DAT0/DO), R69.7 (77), U1.A16 (MMC0_DAT0)
unnamed: J4.8 (DAT1), R69.4 (44), U1.A15 (MMC0_DAT1)
unnamed: J4.1 (DAT2), R69.9 (99), U1.C16 (MMC0_DAT2)
unnamed: J4.2 (DAT3/CS), R69.2 (22), U1.C15 (MMC0_DAT3)
unnamed: R70.2 (22), U1.P1 (GPMC_CSN2), U9.M5 (CMD)
unnamed: R70.3 (33), U1.T1 (GPMC_AD5), U9.B4 (D5)
unnamed: R70.4 (44), U1.T2 (GPMC_AD4), U9.B3 (D4)
unnamed: R70.6 (66), U1.R3 (GPMC_AD0), U9.A3 (D0)
unnamed: R70.7 (77), U1.T3 (GPMC_AD3), U9.B2 (D3)
unnamed: R70.8 (88), U1.P2 (GPMC_CSN1), U9.M6 (SCK)
unnamed: R71.1 (11), U1.R2 (GPMC_AD1), U9.A4 (D1)
unnamed: R71.2 (22), U1.R4 (GPMC_AD7), U9.B6 (D7)
unnamed: R71.3 (33), U1.R13 (GPMC_A4), U9.K5 (~RST)
unnamed: R71.8 (88), U1.P4 (GPMC_AD6), U9.B5 (D6)
unnamed: R71.9 (99), U1.R1 (GPMC_AD2), U9.A5 (D2)
unnamed: R61.1, U1.P13 (GPMC_A5)
unnamed: R50.1, U1.T14 (GPMC_A6)
unnamed: R49.1, U1.R14 (GPMC_A7)
unnamed: R45.1, U1.P14 (GPMC_A8)
unnamed: U1.A11 (UART1_RXD), U8.1 (TXD)
unnamed: U1.B11 (UART1_TXD), U8.4 (RXD)
unnamed: C19.1, C20.1, U9.C2 (VDDI)

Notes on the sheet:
CAN1 RX --> B11 --> UART1_TXD CAN1 TX --> A11 --> UART1_RXD
I/Q Data Pins to MAX2771
eMMC Circuit
All resistors are 0603 1% AEC-Q200 unless marked. All capacitors are 0603 AEC-Q200 Vw >= 16V X5R or better unless marked.
SD Card Circuit pinout from RED board
Need ~2.2uF here, but using two 1uF for simplicity
Z[L|0|CLK]
CAN Transceiver
To main card connector

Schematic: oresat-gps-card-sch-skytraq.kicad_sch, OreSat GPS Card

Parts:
C75: 100n; 0603-C-NOSILK; MPN C0603C104K5RACAUTO
C76: 1u; 0603-C-NOSILK; MPN GRT188R71E105KE13D
C77: 100p; 0603-C-NOSILK; MPN C0603C101K5HACAUTO
R65: 10k; 0603-C-NOSILK; MPN RMCF0603FT10K0
R66, R67: 100; 0603-C-NOSILK; MPN RMCF0603FT100R
R80: NP; R_0603_1608Metric; not fitted
TP20, TP23, TP24: Test-Point; TestPoint-0.75mm-th
U23: ORION-B16; U-SkyTraq-ORION-B16; MPN ORION B16

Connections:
3.3V-S: C75.1, C76.1, C77.1, R65.1, U23.22 (V_BCKP), U23.23 (VCC); also elsewhere on the board
/OSD3358 SYSBOOT : SIP D/STQ-1PPS: TP24.1 (1_1), U23.3 (1PPS); also elsewhere on the board
/OSD3358 SYSBOOT : SIP D/UART2_RX: R67.1, TP23.1 (1_1); also elsewhere on the board
/OSD3358 SYSBOOT : SIP D/UART2_TX: R66.1, TP20.1 (1_1); also elsewhere on the board
/RF + RF Power/STQ-RF: U23.11 (RF_IN); also elsewhere on the board
GND: C75.2, C76.2, C77.2, R80.2, U23.10 (GND), U23.12 (GND), U23.13 (GND), U23.24 (GND), U23.[10,12,13,24] (GND); also elsewhere on the board
unnamed: R80.1, U23.1 (BOOT_SEL)
unnamed: R65.2, U23.8 (RSTN)
unnamed: R66.2, U23.21 (RXD)
unnamed: R67.2, U23.20 (TXD)

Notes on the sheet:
All resistors are 0603 1% AEC-Q200 unless marked. All capacitors are 0603 AEC-Q200 Vw >= 16V X5R or better unless marked.

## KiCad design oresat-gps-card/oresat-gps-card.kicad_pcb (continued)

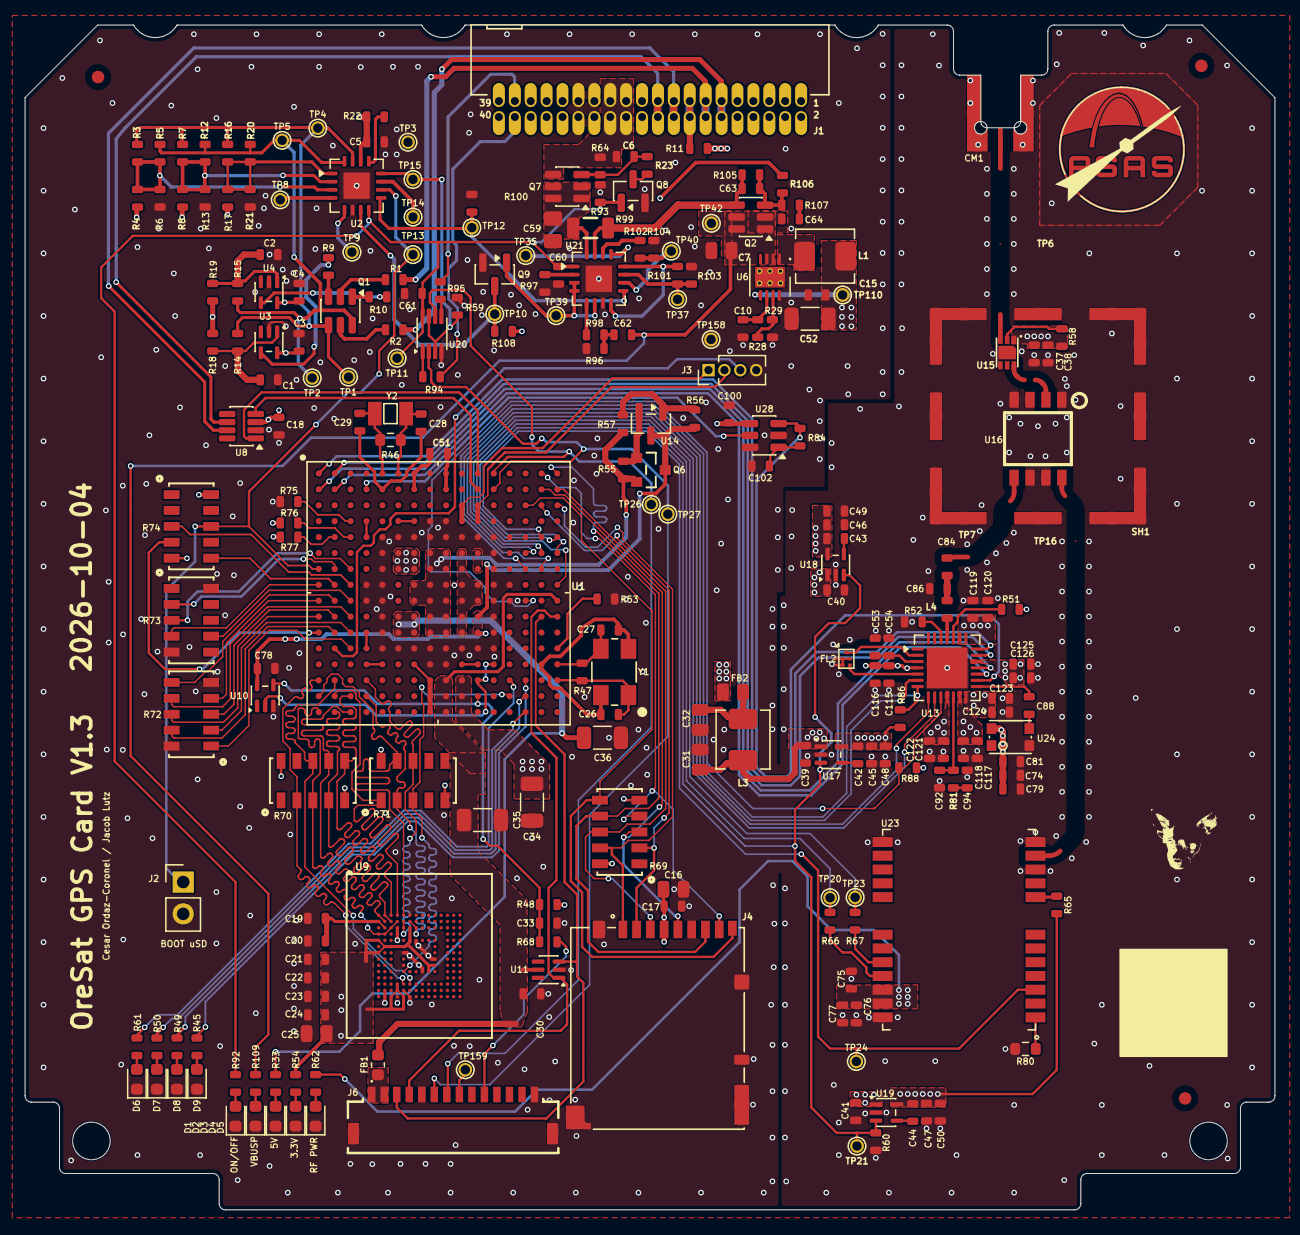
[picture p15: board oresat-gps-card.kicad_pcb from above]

Board: 4 copper layers, 99.8 x 94.6 mm, 247 parts (0 on the bottom side), 186 nets.

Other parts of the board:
LOGO1: PSAS_LOGO_10X10

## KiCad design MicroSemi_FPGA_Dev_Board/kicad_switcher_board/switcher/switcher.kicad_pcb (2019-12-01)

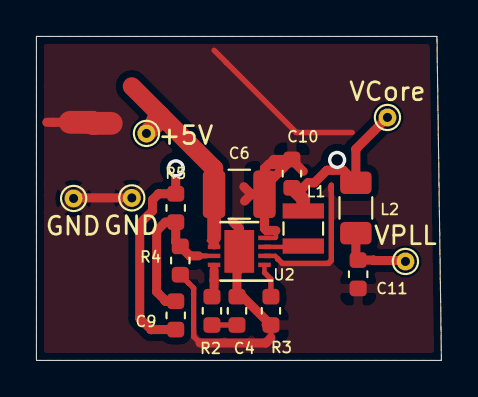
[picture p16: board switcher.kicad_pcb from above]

Board: 4 copper layers, 22.5 x 18.0 mm, 17 parts (0 on the bottom side), 9 nets.

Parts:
+5V: +5V; TestPoint_THTPad_D1.0mm_Drill0.5mm
C4: 680pF; C_0603_1608Metric
C6: 22uF; C_1210_3225Metric
C9: 22pF; C_0603_1608Metric
C10, C11: 10uF; C_0603_1608Metric
GND: GND; TestPoint_THTPad_D1.0mm_Drill0.5mm
GND#2: GND; TestPoint_THTPad_D1.0mm_Drill0.5mm
L1: 2.2uH; L_Wuerth_MAPI-2512
L2: 6.8uH; L_1206_3216Metric
R2: 16.9K; R_0603_1608Metric
R3: 549K; R_0603_1608Metric
R4: 287K; R_0603_1608Metric
R5: 249K; R_0603_1608Metric
U2: LTC3561A; DFN-8-1EP_3x3mm_P0.5mm_EP1.66x2.38mm
VCore: 1.5V Core; TestPoint_THTPad_D1.0mm_Drill0.5mm
VPLL: 1.5V PLL; TestPoint_THTPad_D1.0mm_Drill0.5mm

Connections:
+5V: +5V.1, C6.1, U2.5, U2.6
GND: C4.2, C6.2, C10.2, C11.2, GND.1, GND#2.1, R3.1, R4.1, U2.2, U2.4, U2.9
unnamed: C4.1, R2.1
unnamed: C9.2, R4.2, R5.2, U2.7
unnamed: C9.1, C10.1, L1.2, L2.1, R5.1, VCore.1
unnamed: C11.1, L2.2, VPLL.1
unnamed: L1.1, U2.3
unnamed: R2.2, U2.8
unnamed: R3.2, U2.1

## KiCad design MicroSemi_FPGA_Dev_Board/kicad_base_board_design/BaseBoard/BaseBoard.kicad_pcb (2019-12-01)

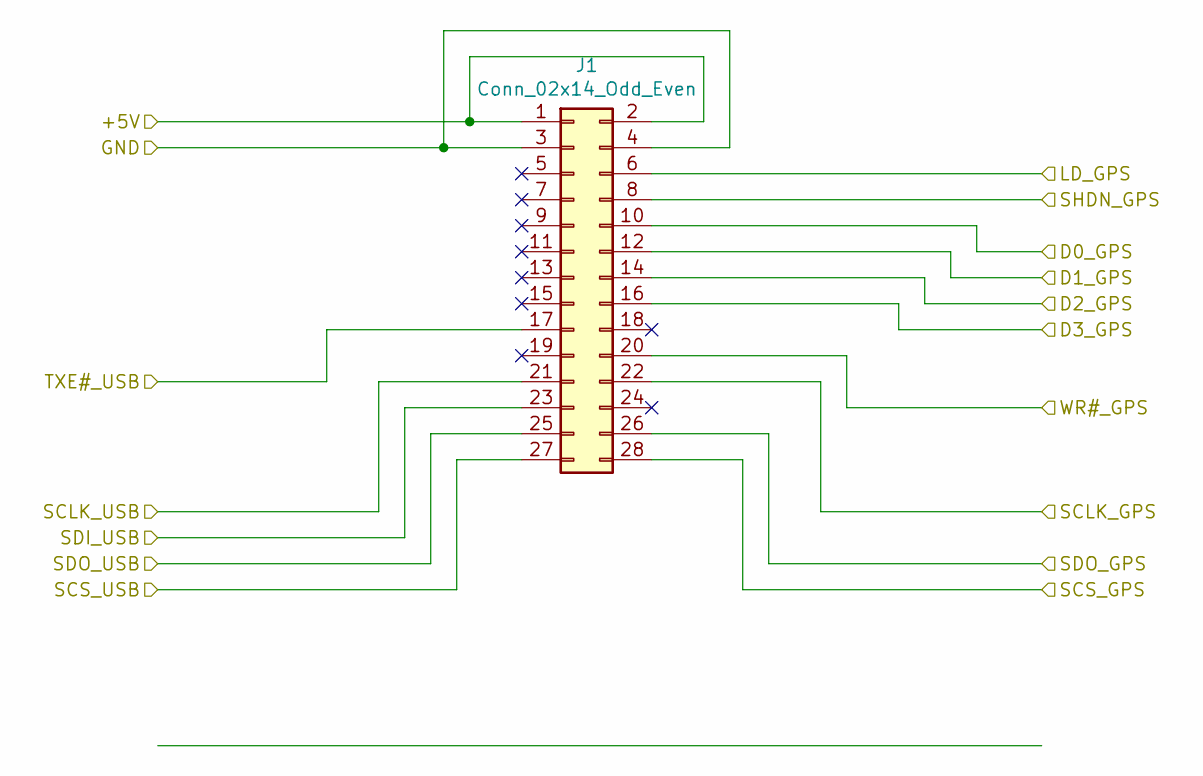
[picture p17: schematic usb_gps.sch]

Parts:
J1: Conn_02x14_Odd_Even; PinHeader_2x14_P2.54mm_Vertical

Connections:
/Sheet5DD758E7/+5V: J1.1, J1.2; also elsewhere on the board
/Sheet5DD758E7/D0_GPS: J1.10; also elsewhere on the board
/Sheet5DD758E7/D1_GPS: J1.12; also elsewhere on the board
/Sheet5DD758E7/D2_GPS: J1.14; also elsewhere on the board
/Sheet5DD758E7/D3_GPS: J1.16; also elsewhere on the board
/Sheet5DD758E7/LD_GPS: J1.6; also elsewhere on the board
/Sheet5DD758E7/SCLK_GPS: J1.22; also elsewhere on the board
/Sheet5DD758E7/SCLK_USB: J1.21; also elsewhere on the board
/Sheet5DD758E7/SCS_GPS: J1.28; also elsewhere on the board
/Sheet5DD758E7/SCS_USB: J1.27; also elsewhere on the board
/Sheet5DD758E7/SDI_USB: J1.23; also elsewhere on the board
/Sheet5DD758E7/SDO_GPS: J1.26; also elsewhere on the board
/Sheet5DD758E7/SDO_USB: J1.25; also elsewhere on the board
/Sheet5DD758E7/SHDN_GPS: J1.8; also elsewhere on the board
/Sheet5DD758E7/TXE#_USB: J1.17; also elsewhere on the board
/Sheet5DD758E7/WR#_GPS: J1.20; also elsewhere on the board
GND: J1.3, J1.4; also elsewhere on the board

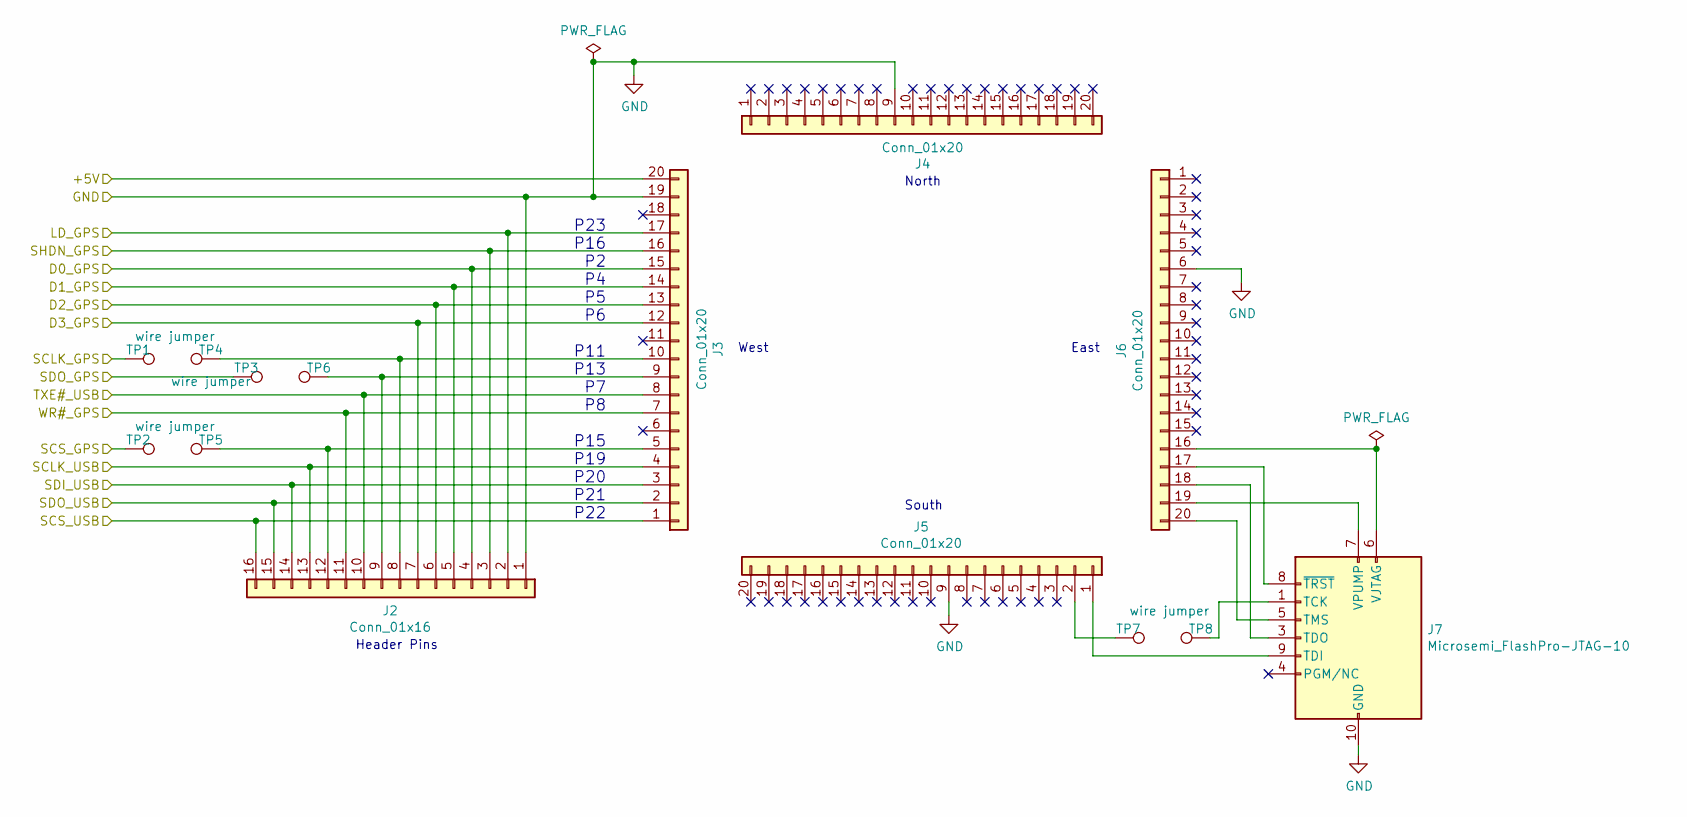
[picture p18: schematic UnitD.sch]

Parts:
J2: Conn_01x16; PinHeader_1x16_P2.54mm_Vertical
J3, J4, J5, J6: Conn_01x20; CastellatedPad20
J7: Microsemi_FlashPro-JTAG-10; IDC-Header_2x05_P2.54mm_Vertical
TP1, TP2, TP3, TP4, TP5, TP6, TP7, TP8: wire jumper; TestPoint_THTPad_D1.5mm_Drill0.7mm

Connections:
/Sheet5DD758E7/+5V: J3.20; also elsewhere on the board
/Sheet5DD758E7/D0_GPS: J2.4, J3.15; also elsewhere on the board
/Sheet5DD758E7/D1_GPS: J2.5, J3.14; also elsewhere on the board
/Sheet5DD758E7/D2_GPS: J2.6, J3.13; also elsewhere on the board
/Sheet5DD758E7/D3_GPS: J2.7, J3.12; also elsewhere on the board
/Sheet5DD758E7/LD_GPS: J2.2, J3.17; also elsewhere on the board
/Sheet5DD758E7/SCLK_GPS: TP1.1; also elsewhere on the board
/Sheet5DD758E7/SCLK_USB: J2.13, J3.4; also elsewhere on the board
/Sheet5DD758E7/SCS_GPS: TP2.1; also elsewhere on the board
/Sheet5DD758E7/SCS_USB: J2.16, J3.1; also elsewhere on the board
/Sheet5DD758E7/SDI_USB: J2.14, J3.3; also elsewhere on the board
/Sheet5DD758E7/SDO_GPS: TP3.1; also elsewhere on the board
/Sheet5DD758E7/SDO_USB: J2.15, J3.2; also elsewhere on the board
/Sheet5DD758E7/SHDN_GPS: J2.3, J3.16; also elsewhere on the board
/Sheet5DD758E7/TXE#_USB: J2.10, J3.8; also elsewhere on the board
/Sheet5DD758E7/WR#_GPS: J2.11, J3.7; also elsewhere on the board
GND: J2.1, J3.19, J4.9, J5.9, J6.6, J7.2 (GND), J7.10 (GND); also elsewhere on the board
unnamed: J2.8, J3.10, TP4.1
unnamed: J2.9, J3.9, TP6.1
unnamed: J2.12, J3.5, TP5.1
unnamed: J5.1, J7.9 (TDI)
unnamed: J5.2, TP7.1
unnamed: J6.16, J7.6 (VJTAG)
unnamed: J6.17, J7.8 (~TRST)
unnamed: J6.18, J7.3 (TDO)
unnamed: J6.19, J7.7 (VPUMP)
unnamed: J6.20, J7.5 (TMS)
unnamed: J7.1 (TCK), TP8.1

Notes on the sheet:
Header Pins
North
South
West
East
P23 P16 P2 P4 P5 P6 P11 P13 P7 P8 P15 P19 P20 P21 P22


Board: 2 copper layers, 83.2 x 64.0 mm, 15 parts (0 on the bottom side), 28 nets.

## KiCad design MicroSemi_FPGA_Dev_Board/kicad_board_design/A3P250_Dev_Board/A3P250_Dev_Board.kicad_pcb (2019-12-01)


Board: 4 copper layers, 46.0 x 46.0 mm, 59 parts (0 on the bottom side), 90 nets.

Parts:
+5V: +5V; TestPoint_THTPad_D1.0mm_Drill0.5mm
C1, C3, C7: 0.01uF; C_0603_1608Metric
C2: 0.33uF; C_0603_1608Metric
C4: 680pF; C_0603_1608Metric
C5: 1uF; C_0603_1608Metric
C6: 22uF; C_1210_3225Metric
C8, C10, C11: 10uF; C_0603_1608Metric
C9: 22pF; C_0603_1608Metric
C12, C14, C16, C18, C20, C22, C24, C26, C28: .1uF; C_0402_1005Metric
C13, C15, C17, C19, C21, C23, C25, C27, C29: 0.01uF; C_0402_1005Metric
CLK: VCCIO; TestPoint_THTPad_D1.0mm_Drill0.5mm
D1: LED_ALT; LED_0805_2012Metric
D2: LED_ALT; LED_0603_1608Metric
GND: GND; TestPoint_THTPad_D1.0mm_Drill0.5mm
J1, J1#2, J2, J2#2, J3, J3#2, J4, J4#2: Conn_01x20; PinHeader_1x20_P2.00mm_Vertical
L1: 2.2uH; L_Wuerth_MAPI-2512
L2: 6.8uH; L_1206_3216Metric
R1, R6: 200; R_0805_2012Metric
R2: 16.9K; R_0603_1608Metric
R3: 549K; R_0603_1608Metric
R4: 287K; R_0603_1608Metric
R5: 249K; R_0603_1608Metric
R7, R8: 20K; R_0603_1608Metric
U1: A3P250; LQFP-100_14x14mm_P0.5mm
U2: LTC3561A; DFN-8-1EP_3x3mm_P0.5mm_EP1.66x2.38mm
U3: LT1962-3.3; MSOP-8_3x3mm_P0.65mm
VCore: 1.5V Core; TestPoint_THTPad_D1.0mm_Drill0.5mm
VIO: VCCIO; TestPoint_THTPad_D1.0mm_Drill0.5mm
VPLL: 1.5V PLL; TestPoint_THTPad_D1.0mm_Drill0.5mm
X1: ASE-25MHz; Oscillator_SMD_Abracon_ASE-4Pin_3.2x2.5mm

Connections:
+5V: +5V.1, C5.1, C6.1, J4.20, J4#2.20, U2.5, U2.6, U3.5, U3.8
GAA_IO00RSB0: J4.18, J4#2.18, U1.98
GND: C1.2, C2.2, C3.2, C4.2, C5.2, C6.2, C8.2, C10.2, C11.2, C12.2, C13.2, C14.2, C15.2, C16.2, C17.2, C18.2, C19.2, C20.2, C21.2, C22.2, C23.2, C24.2, C25.2, C26.2, C27.2, C28.2, C29.2, GND.1, J4.19, J4#2.19, R1.2, R3.1, R4.1, R6.2, R7.2, U1.1, U1.9, U1.12, U1.25, U1.38, U1.46, U1.51, U1.67, U1.75, U1.88, U1.99, U2.2, U2.4, U2.9, U3.4, X1.2
unnamed: C4.1, R2.1
unnamed: C7.2, U3.3
unnamed: C9.2, R4.2, R5.2, U2.7
unnamed: C9.1, C10.1, C14.1, C15.1, C16.1, C17.1, C18.1, C19.1, C20.1, C21.1, L1.2, L2.1, R5.1, U1.17, U1.37, U1.68, U1.89, VCore.1
unnamed: C11.1, C12.1, C13.1, L2.2, U1.14, VPLL.1
unnamed: C22.1, C23.1, J1.9, J1#2.9, U1.87, U1.100
unnamed: C24.1, C25.1, J2.6, J2#2.6, U1.66, U1.74
unnamed: C26.1, C27.1, J3.9, J3#2.9, U1.39, U1.50
unnamed: D1.1, R1.1
unnamed: D1.2, J4.12, J4#2.12, U1.8
unnamed: D2.1, R6.1
unnamed: J1.1, J1#2.1, U1.97
unnamed: J1.2, J1#2.2, U1.96
unnamed: J1.3, J1#2.3, U1.95
unnamed: J1.4, J1#2.4, U1.94
unnamed: J1.5, J1#2.5, U1.93
unnamed: J1.6, J1#2.6, U1.92
unnamed: J1.7, J1#2.7, U1.91
unnamed: J1.8, J1#2.8, U1.90
unnamed: J1.10, J1#2.10, U1.86
unnamed: J1.11, J1#2.11, U1.85
unnamed: J1.12, J1#2.12, U1.84
unnamed: J1.13, J1#2.13, U1.83
unnamed: J1.14, J1#2.14, U1.82
unnamed: J1.15, J1#2.15, U1.81
unnamed: J1.16, J1#2.16, U1.80
unnamed: J1.17, J1#2.17, U1.79
unnamed: J1.18, J1#2.18, U1.78
unnamed: J1.19, J1#2.19, U1.77
unnamed: J1.20, J1#2.20, U1.76
unnamed: J2.1, J2#2.1, U1.73
unnamed: J2.2, J2#2.2, U1.72
unnamed: J2.3, J2#2.3, U1.71
unnamed: J2.4, J2#2.4, U1.70
unnamed: J2.5, J2#2.5, U1.69
unnamed: J2.7, J2#2.7, U1.65
unnamed: J2.8, J2#2.8, U1.64
unnamed: J2.9, J2#2.9, U1.63
unnamed: J2.10, J2#2.10, U1.62
unnamed: J2.11, J2#2.11, U1.61
unnamed: J2.12, J2#2.12, U1.60
unnamed: J2.13, J2#2.13, U1.59
unnamed: J2.14, J2#2.14, U1.58
unnamed: J2.15, J2#2.15, U1.57
unnamed: J3.3, J3#2.3, U1.45
unnamed: J3.4, J3#2.4, U1.44
unnamed: J3.5, J3#2.5, U1.43
unnamed: J3.6, J3#2.6, U1.42
unnamed: J3.7, J3#2.7, U1.41
unnamed: J3.8, J3#2.8, U1.40
unnamed: J3.10, J3#2.10, U1.36
unnamed: J3.11, J3#2.11, U1.35
unnamed: J3.12, J3#2.12, U1.34
unnamed: J3.13, J3#2.13, U1.33
unnamed: J3.14, J3#2.14, U1.32
unnamed: J3.15, J3#2.15, U1.31
unnamed: J3.16, J3#2.16, U1.30
unnamed: J3.17, J3#2.17, U1.29
unnamed: J3.18, J3#2.18, U1.28
unnamed: J3.19, J3#2.19, U1.27
unnamed: J3.20, J3#2.20, U1.26
unnamed: J4.1, J4#2.1, R7.1, U1.23
unnamed: J4.2, J4#2.2, U1.22
unnamed: J4.3, J4#2.3, U1.21
unnamed: J4.4, J4#2.4, U1.20
unnamed: J4.5, J4#2.5, U1.19
unnamed: J4.7, J4#2.7, U1.16
unnamed: J4.8, J4#2.8, U1.15
unnamed: J4.9, J4#2.9, U1.13
unnamed: J4.10, J4#2.10, U1.11
unnamed: CLK.1, J4.11, J4#2.11, U1.10, X1.3
unnamed: J4.13, J4#2.13, U1.7
unnamed: J4.14, J4#2.14, U1.6
unnamed: J4.15, J4#2.15, U1.5
unnamed: J4.16, J4#2.16, U1.4
unnamed: J4.17, J4#2.17, U1.2
unnamed: L1.1, U2.3
unnamed: R2.2, U2.8
unnamed: R3.2, U2.1
unnamed: R8.2, U1.3
TCK: J3.2, J3#2.2, U1.47
TDI: J3.1, J3#2.1, U1.48
TDO: J2.18, J2#2.18, U1.54
TMS: J2.20, J2#2.20, U1.49
TRST: J2.17, J2#2.17, U1.55
VCCIB3: C1.1, C7.1, C8.1, C28.1, C29.1, D2.2, J2.16, J2#2.16, J4.6, J4#2.6, R8.1, U1.18, U1.24, U1.56, U3.1, U3.2, VIO.1, X1.1, X1.4
VPUMP: C2.1, C3.1, J2.19, J2#2.19, U1.52

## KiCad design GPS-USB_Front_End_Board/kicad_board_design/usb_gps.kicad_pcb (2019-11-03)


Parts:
P1: CONN_02X14; Pin_Header_Straight_2x14; MPN PPTC142LFBN-RC

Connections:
/MAX_2769/+5V: P1.1, P1.2; also elsewhere on the board
/MAX_2769/D0: P1.10; also elsewhere on the board
/MAX_2769/D1: P1.12; also elsewhere on the board
/MAX_2769/D2: P1.14; also elsewhere on the board
/MAX_2769/D3: P1.16; also elsewhere on the board
/MAX_2769/LD: P1.6; also elsewhere on the board
/MAX_2769/SCLK: P1.22; also elsewhere on the board
/MAX_2769/SCS: P1.28; also elsewhere on the board
/MAX_2769/SDO: P1.26; also elsewhere on the board
/MAX_2769/SHDN#: P1.8; also elsewhere on the board
/MAX_2769/WR#: P1.20; also elsewhere on the board
/USB_FT2232/D0: P1.11; also elsewhere on the board
/USB_FT2232/D1: P1.9; also elsewhere on the board
/USB_FT2232/D2: P1.13; also elsewhere on the board
/USB_FT2232/D3: P1.15; also elsewhere on the board
/USB_FT2232/GPIO0: P1.7; also elsewhere on the board
/USB_FT2232/GPIO1: P1.5; also elsewhere on the board
/USB_FT2232/SCLK: P1.21; also elsewhere on the board
/USB_FT2232/SCS: P1.27; also elsewhere on the board
/USB_FT2232/SDI: P1.23; also elsewhere on the board
/USB_FT2232/SDO: P1.25; also elsewhere on the board
/USB_FT2232/TXE#: P1.17; also elsewhere on the board
/USB_FT2232/WR#: P1.19; also elsewhere on the board
GND: P1.3, P1.4; also elsewhere on the board


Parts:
C1: 1uF; C_0603_HandSoldering; MPN CL10B105KP8NNNC
C2, C6, C8, C9, C33, C35, C37, C38, C40, C41, C44, C45, C46, C47, C48: .1uF; C_0402; MPN CGA2B1X7R1C104K050BC
C3, C5: 33pF; C_0805_HandSoldering; MPN C0805C330J5GACTU
C4, C34: 3.3uF; C_0402; MPN C1005X5R0J335K050BC
C7: 10uF; C_0805; MPN CL21A106KPFNNNG
C10: 10uF; C_0603_HandSoldering; MPN CL10B106MQ8NRNC
C42, C43: 4.7uF; C_0402; MPN LMF105B7472KVHF
D1: USBLC6-2SC6; SOT23-6L; MPN USBLC6-2SC6; Digi-Key_PN 497-5235-1-ND
D2: LTST-C171KRKT; 0805; MPN LTST-C171KRKT; Digi-Key_PN 160-1427-1-ND
J1: Micro-USB Connector; USB_Micro_B_Female_10118194-0001LF; MPN 10118194-0001LF; Digi-Key_PN 609-4618-6-ND
R1, R3, R4, R5: 10K; R_0805_HandSoldering; MPN CRGH0805F10K
R2: 12.0K; R_0603_HandSoldering; MPN CPF0603B12KE1
R6: 2K; R_0603_HandSoldering; MPN AC0603FR-072KL
R11: 200; 0805; MPN RR1220P-201-D
R19: 0; R_0603_HandSoldering; MPN CRCW06030000Z0EBC
R20: DNP; R_0603_HandSoldering; MPN CRCW06030000Z0EBC
TP1: TEST; Test_Point
TP2, TP3, TP4, TP5, TP6: TEST; Measurement_Point_Round-TH_Small
U1: 93LCxxB; SOIC127P600X175-8N; MPN 93LC46B-I/SN
U2: FT2232HL-REEL; LQFP-64_10x10mm; MPN FT2232HL-REEL; Digi-Key_PN 768-1024-1-ND
U3: L4931 LDO; SOIC-8_W3.9mm; MPN L4931ABD33-TR; Digi-Key_PN 497-1155-1-ND
U8: LT1719S6 -- Not Populated; TSOT-23_S6; MPN LT1719IS6#TRMPBF
W1: EECS; Measurement_Point_Round-TH_Small
W2: D0; Measurement_Point_Round-TH_Small
W3: D1; Measurement_Point_Round-TH_Small
W4: PWREN; Measurement_Point_Round-TH_Small
W5: SUSPEND; Measurement_Point_Round-TH_Small
W6: EECLK; Measurement_Point_Round-TH_Small
Y1: 12MHz Crystal; CTS_405_xtal; MPN 405C35E12M00000

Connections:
/MAX_2769/+5V: C6.1, C8.1, C10.1, D1.5, J1.1 (VBUS), TP3.1, TP4.1, U3.8 (VIN); also elsewhere on the board
/MAX_2769/VCC3V3: C1.1, C2.1, C7.1, C34.1, C35.1, C38.1, C42.1, C43.1, C44.1, C45.1, C46.1, C47.1, R1.1, R3.1, R4.1, R5.1, R11.2, TP5.1, U1.8 (VCC), U2.4 (VPHY), U2.9 (VPLL), U2.20 (VCCIO), U2.31 (VCCIO), U2.42 (VCCIO), U2.50 (VREGIN), U2.56 (VCCIO), U3.1 (VOUT), U8.4 (V+); also elsewhere on the board
/USB_FT2232/D0: U2.38 (BDBUS0); also elsewhere on the board
/USB_FT2232/D1: U2.39 (BDBUS1); also elsewhere on the board
/USB_FT2232/D2: U2.40 (BDBUS2); also elsewhere on the board
/USB_FT2232/D3: U2.41 (BDBUS3); also elsewhere on the board
/USB_FT2232/Data+: D1.4, U2.8 (DP)
/USB_FT2232/Data-: D1.6, U2.7 (DM)
/USB_FT2232/EECLK: R3.2, U1.2 (SCLK), U2.62 (EECLK), W6.1
/USB_FT2232/EECS: R1.2, U1.1 (CS), U2.63 (EECS), W1.1
/USB_FT2232/GPIO0: U2.26 (ACBUS0); also elsewhere on the board
/USB_FT2232/GPIO1: U2.27 (ACBUS1); also elsewhere on the board
/USB_FT2232/OSCO: C5.1, TP6.1, U2.3 (OSCO), Y1.3
/USB_FT2232/REF: R2.1, U2.6 (REF)
/USB_FT2232/RESET: R4.2, TP2.1, U2.14 (RESET)
/USB_FT2232/SCLK: U2.16 (ADBUS0); also elsewhere on the board
/USB_FT2232/SCS: U2.19 (ADBUS3); also elsewhere on the board
/USB_FT2232/SDI: U2.18 (ADBUS2); also elsewhere on the board
/USB_FT2232/SDO: U2.17 (ADBUS1); also elsewhere on the board
/USB_FT2232/TXE#: U2.52 (BCBUS1); also elsewhere on the board
/USB_FT2232/VREGOUT: C4.1, C33.1, C40.1, C41.1, C48.1, U2.12 (VCORE), U2.37 (VCORE), U2.49 (VREGOUT), U2.64 (VCORE)
/USB_FT2232/WR#: R19.2, R20.2, U8.3 (IN+); also elsewhere on the board
/USB_FT2232/WR_fix#: R19.1, U2.54 (BCBUS3), U8.5 (OUT)
GND: C1.2, C2.2, C3.2, C4.2, C5.2, C6.2, C7.2, C8.2, C9.2, C10.2, C33.2, C34.2, C35.2, C37.2, C38.2, C40.2, C41.2, C42.2, C43.2, C44.2, C45.2, C46.2, C47.2, C48.2, D1.2, D2.1, J1.5 (GND), R2.2, TP1.1, U1.5 (GND), U2.1 (GND), U2.5 (GND), U2.10 (AGND), U2.11 (GND), U2.13 (TEST), U2.15 (GND), U2.25 (GND), U2.35 (GND), U2.47 (GND), U2.51 (GND), U3.2 (GND), U3.3 (GND), U3.5 (INHIBIT), U3.6 (GND), U3.7 (GND), U8.2 (V-), U8.6 (SHDN), Y1.2, Y1.4; also elsewhere on the board
unnamed: C3.1, U2.2 (OSCI), Y1.1
unnamed: C9.1, J1.6
unnamed: C37.1, R20.1, U8.1 (IN)
unnamed: D1.1, J1.2 (Data-)
unnamed: D1.3, J1.3 (Data+)
unnamed: D2.2, R11.1
unnamed: R5.2, R6.2, U1.4 (DO), W2.1
unnamed: R6.1, U1.3 (DI), U2.61 (EEDATA), W3.1
unnamed: U2.36 (SUSPEND), W5.1
unnamed: U2.60 (PWREN), W4.1

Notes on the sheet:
Off-Sheet Signals
Can be used to clean up CLK if needed.


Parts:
C11, C13, C14, C15, C16, C21, C22, C30: .1uF; C_0402; MPN CGA2B1X7R1C104K050BC
C12, C18: 1uF; C_0603_HandSoldering; MPN CL10B105KP8NNNC
C17, C24, C26: 10nF; C_0402; MPN GRM155R71C103KA01D
C19, C31, C32: 100pF; C_0402; MPN CC0402JRNPO9BN101
C20: 3300pF; C_0603_HandSoldering; MPN 06035C332KAT4A
C23, C36: 1uF; C_0805; MPN C0805C105K4RACTU
C25: 27pF; C_0805_HandSoldering; MPN 08055C270KAT2A
C27, C28, C39: 470pF; C_0402; MPN 04025C471KAT2A
C29: 1.7pF; C_0402; MPN GJM1555C1H1R7WB01D
J3: SMA-Cinch_142-0701-851; Cinch_142-0701-851; MPN 5-1814832-1; Digi-Key_PN A97594-ND
L1: 5.6nH; C_0402; MPN L-07C5N6SV6T
L4: 33nH; C_0402; MPN CI100505-33NJ
P2: CONN_01X03; Molex_KK-6410-03_03x2.54mm_Straight; MPN PREC003SAAN-RC
R7: 10K; R_0805_HandSoldering; MPN CRGH0805F10K
R8, R9, R10, R14, R15, R16, R17, R18: 0; R_0805_HandSoldering; MPN CRCW06030000Z0EBC
R13: 20K; R_0603_HandSoldering; MPN CRT0603-FZ-2002EST
U4, U5: MAX8510; 21-0076E_FLIP; MPN MAX8510EXK30+T
U6: MAX2771; TQFP_29_EP_MAX2769; MPN MAX2771ETI+
U7, U9: SAWTEK-855969; Sawtek_855969; MPN 855969; Digi-Key_PN AP2114H-3.3TRG1DICT-ND
W7: -BB; Measurement_Point_Round-TH_Small
W8: +BB; Measurement_Point_Round-TH_Small
X1: 13.368MHz TCXO; TCXO_Taitien; MPN TXETCDSANF-16.368000

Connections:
/MAX_2769/+5V: C12.1, C18.1, U4.1 (IN), U4.3 (*SHDN), U5.1 (IN), U5.3 (*SHDN); also elsewhere on the board
/MAX_2769/CLKOUT: C26.2, R14.1
/MAX_2769/CS#: R10.1, U6.9 (CSN)
/MAX_2769/D0: R18.2; also elsewhere on the board
/MAX_2769/D1: R17.2; also elsewhere on the board
/MAX_2769/D2: R16.2; also elsewhere on the board
/MAX_2769/D3: R15.2; also elsewhere on the board
/MAX_2769/I0: R17.1, U6.12 (I0)
/MAX_2769/I1: R18.1, U6.13 (I1)
/MAX_2769/LD: U6.17 (LD); also elsewhere on the board
/MAX_2769/Q0: R16.1, U6.11 (Q0)
/MAX_2769/Q1: R15.1, U6.10 (Q1)
/MAX_2769/SCLK: R8.2; also elsewhere on the board
/MAX_2769/SCLKL: R8.1, U6.8 (SCLK)
/MAX_2769/SCS: R10.2; also elsewhere on the board
/MAX_2769/SDATA: R9.1, U6.7 (SDATA)
/MAX_2769/SDO: R9.2; also elsewhere on the board
/MAX_2769/SHDN#: R7.1, U6.18 (~SHDN); also elsewhere on the board
/MAX_2769/VCC3V3: P2.3; also elsewhere on the board
/MAX_2769/VCCA: C11.1, C13.1, C14.1, C16.1, C17.1, C19.1, C21.1, C22.1, C23.1, R7.2, U4.5 (OUT), U6.2 (VCCCP), U6.6 (VCCD), U6.22 (VCCRF), U6.27 (VCCIF), U6.28 (VCCVCO), X1.4 (+5V)
/MAX_2769/VCCD: C15.1, C24.1, C36.1, U5.5 (OUT), U6.14 (VCCADC)
/MAX_2769/WR#: R14.2; also elsewhere on the board
GND: C11.2, C12.2, C13.2, C14.2, C15.2, C16.2, C18.2, C19.2, C21.2, C22.2, C23.2, C25.2, C27.2, C29.2, C30.2, C31.2, C36.2, J3.1, U4.2 (GND), U5.2 (GND), U6.29 (EP), U7.1 (GND), U7.3 (GND), U7.4 (GND), U7.6 (GND), U9.1 (GND), U9.3 (GND), U9.4 (GND), U9.6 (GND), X1.2 (GND); also elsewhere on the board
unnamed: C17.2, U4.4 (BP)
unnamed: C20.1, X1.3 (FREQ)
unnamed: C20.2, U6.3 (XTAL)
unnamed: C24.2, U5.4 (BP)
unnamed: C25.1, R13.2, U6.1 (CPOUT)
unnamed: C26.1, U6.4 (CLKOUT)
unnamed: C27.1, R13.1
unnamed: C28.1, U7.2 (IN)
unnamed: C28.2, U6.24 (LNAOUT_HI)
unnamed: C29.1, C32.2, L1.1
unnamed: C30.1, C31.1, L4.1, P2.2
unnamed: C32.1, U9.5 (OUT)
unnamed: C39.1, U6.25 (MIXIN_HI)
unnamed: C39.2, U7.5 (OUT)
unnamed: J3.2, L4.2, U9.2 (IN)
unnamed: L1.2, U6.19 (LNAIN_HI)
unnamed: U6.15 (ANAIPOUT), W8.1
unnamed: U6.16 (ANAINOUT), W7.1

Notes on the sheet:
(Active or Passive Antenna)
Off-Sheet Signals
(jumper pins 2-3 for active antenna)

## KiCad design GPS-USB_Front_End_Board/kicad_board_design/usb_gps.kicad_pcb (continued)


Board: 4 copper layers, 99.1 x 53.3 mm, 100 parts (0 on the bottom side), 72 nets.

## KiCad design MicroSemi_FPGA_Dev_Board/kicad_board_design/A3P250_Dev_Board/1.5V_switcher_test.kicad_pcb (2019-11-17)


Board: 4 copper layers, 46.7 x 46.7 mm, 39 parts (0 on the bottom side), 89 nets.

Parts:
C1, C3, C7, C13, C15, C17, C19, C21: 0.01uF; C_0603_1608Metric
C2: 0.33uF; C_0603_1608Metric
C4: 680pF; C_0603_1608Metric
C5: 1uF; C_0603_1608Metric
C6: 22uF; C_1210_3225Metric
C8, C10, C11: 10uF; C_0603_1608Metric
C9: 22pF; C_0603_1608Metric
C12, C14, C16, C18, C20: .1uF; C_0402_1005Metric
D1: LED_ALT; LED_0805_2012Metric
D2: LED_ALT; LED_0603_1608Metric
J1, J2, J3, J4: Conn_01x20; PinHeader_1x20_P2.00mm_Vertical
L1: 2.2uH; L_Wuerth_MAPI-2512
L2: 6.8uH; L_1206_3216Metric
R1, R6: 200; R_0805_2012Metric
R2: 16.9K; R_0603_1608Metric
R3: 549K; R_0603_1608Metric
R4: 287K; R_0603_1608Metric
R5: 249K; R_0603_1608Metric
U1: A3P250; LQFP-100_14x14mm_P0.5mm
U2: LTC3561A; DFN-8-1EP_3x3mm_P0.5mm_EP1.66x2.38mm
U3: LT1962-3.3; MSOP-8_3x3mm_P0.65mm
X1: ASE-25MHz; Oscillator_SMD_Abracon_ASE-4Pin_3.2x2.5mm

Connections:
+5V: C5.1, C6.1, J4.20, U2.5, U2.6, U3.5, U3.8
GAA_IO00RSB0: J4.17, U1.98
GND: C1.2, C2.2, C3.2, C4.2, C5.2, C6.2, C8.2, C10.2, C11.2, C12.2, C13.2, C14.2, C15.2, C16.2, C17.2, C18.2, C19.2, C20.2, C21.2, J4.19, R1.2, R3.1, R4.1, R6.2, U1.1, U1.9, U1.12, U1.24, U1.25, U1.38, U1.46, U1.50, U1.51, U1.67, U1.74, U1.75, U1.88, U1.99, U1.100, U2.2, U2.4, U2.9, U3.4, X1.2
unnamed: C4.1, R2.1
unnamed: C7.2, U3.3
unnamed: C9.2, R4.2, R5.2, U2.7
unnamed: C9.1, C10.1, C14.1, C15.1, C16.1, C17.1, C18.1, C19.1, C20.1, C21.1, L1.2, L2.1, R5.1, U1.17, U1.37, U1.68, U1.89
unnamed: C11.1, C12.1, C13.1, L2.2, U1.14
unnamed: D1.1, R1.1
unnamed: D1.2, J4.12, U1.8
unnamed: D2.1, R6.1
unnamed: J1.1, U1.97
unnamed: J1.2, U1.96
unnamed: J1.3, U1.95
unnamed: J1.4, U1.94
unnamed: J1.5, U1.93
unnamed: J1.6, U1.92
unnamed: J1.7, U1.91
unnamed: J1.8, U1.90
unnamed: J1.9, U1.87
unnamed: J1.10, U1.86
unnamed: J1.11, U1.85
unnamed: J1.12, U1.84
unnamed: J1.13, U1.83
unnamed: J1.14, U1.82
unnamed: J1.15, U1.81
unnamed: J1.16, U1.80
unnamed: J1.17, U1.79
unnamed: J1.18, U1.78
unnamed: J1.19, U1.77
unnamed: J1.20, U1.76
unnamed: J2.1, U1.73
unnamed: J2.2, U1.72
unnamed: J2.3, U1.71
unnamed: J2.4, U1.70
unnamed: J2.5, U1.69
unnamed: J2.6, U1.66
unnamed: J2.7, U1.65
unnamed: J2.8, U1.64
unnamed: J2.9, U1.63
unnamed: J2.10, U1.62
unnamed: J2.11, U1.61
unnamed: J2.12, U1.60
unnamed: J2.13, U1.59
unnamed: J2.14, U1.58
unnamed: J2.15, U1.57
unnamed: J3.3, U1.45
unnamed: J3.4, U1.44
unnamed: J3.5, U1.43
unnamed: J3.6, U1.42
unnamed: J3.7, U1.41
unnamed: J3.8, U1.40
unnamed: J3.9, U1.39
unnamed: J3.10, U1.36
unnamed: J3.11, U1.35
unnamed: J3.12, U1.34
unnamed: J3.13, U1.33
unnamed: J3.14, U1.32
unnamed: J3.15, U1.31
unnamed: J3.16, U1.30
unnamed: J3.17, U1.29
unnamed: J3.18, U1.28
unnamed: J3.19, U1.27
unnamed: J3.20, U1.26
unnamed: J4.1, U1.23
unnamed: J4.2, U1.22
unnamed: J4.3, U1.21
unnamed: J4.4, U1.20
unnamed: J4.5, U1.19
unnamed: J4.7, U1.16
unnamed: J4.8, U1.15
unnamed: J4.9, U1.13
unnamed: J4.10, U1.11
unnamed: J4.11, U1.10, X1.3
unnamed: J4.13, U1.7
unnamed: J4.14, U1.6
unnamed: J4.15, U1.5
unnamed: J4.16, U1.4
unnamed: J4.18, U1.2
unnamed: L1.1, U2.3
unnamed: R2.2, U2.8
unnamed: R3.2, U2.1
TCK: J3.2, U1.47
TDI: J3.1, U1.48
TDO: J2.18, U1.54
TMS: J2.20, U1.49
TRST: J2.17, U1.55
VCCIB3: C1.1, C7.1, C8.1, D2.2, J2.16, J4.6, U1.18, U1.56, U3.1, U3.2, X1.1, X1.4
VPUMP: C2.1, C3.1, J2.19, U1.52

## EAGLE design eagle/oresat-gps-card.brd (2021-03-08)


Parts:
CM1: J-MOLEX-SMPM-73300-003X; J-MOLEX-SMPM-073300-003X
J1: ORESAT-DEBUG-CONNECTOR-CARD; TE_2-1734592-0
J4: TFM-120-01-L-D-RA; J-SAMTEC-TFM-120-X1-XXX-D-RA
PCB1: ORESAT-CARD-V1.3-GENERIC-1RF-POS2
TP58, TP59, TP60, TP61, TP62, TP183, TP184: TEST-POINT3X4; PAD.03X.04

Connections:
!SD: J4.39, J4.40
CAN1_H: J4.33, J4.34, TP184.P$1
CAN1_L: J4.35, J4.36, TP183.P$1
CAN2_H: J4.17, J4.18; also elsewhere on the board
CAN2_L: J4.19, J4.20; also elsewhere on the board
EEPROM_WP: J1.20 (DEBUG-3); also elsewhere on the board
GND: CM1.P$1 (SHIELD3), CM1.P$2 (SHIELD2), CM1.P$3 (SHIELD1), CM1.P$4 (SHIELD), J1.3 (GND), J1.6 (GND), J1.9 (GND), J1.PAD1 (PAD), J1.PAD2 (PAD), J4.27, J4.28, J4.29, J4.30, J4.31, J4.32, J4.37, J4.38; also elsewhere on the board
I2C0_SCL: J1.18 (DEBUG-1); also elsewhere on the board
I2C0_SDA: J1.19 (DEBUG-2); also elsewhere on the board
unnamed: J4.1, J4.2, TP62.P$1
OPD_PWR: J4.15, J4.16; also elsewhere on the board
OPD_SCL: J4.13, J4.14; also elsewhere on the board
OPD_SDA: J4.11, J4.12; also elsewhere on the board
RF-IN: CM1.RF (CENTER); also elsewhere on the board
SPARE1: J4.9, J4.10, TP58.P$1
SPARE2: J4.7, J4.8, TP59.P$1
SPARE3: J4.5, J4.6, TP60.P$1
SPARE4: J4.3, J4.4, TP61.P$1
UART0_RX: J1.12 (CARD-RX); also elsewhere on the board
UART0_TX: J1.13 (CARD-TX); also elsewhere on the board
USB_CLI_N: J1.5 (DEVICE-D-); also elsewhere on the board
USB_CLI_P: J1.4 (DEVICE-D+); also elsewhere on the board
USB_CLI_VBUS: J1.1 (VBUSP), J1.2 (VBUSP); also elsewhere on the board
USB_HO_N: J1.8 (HOST-D-); also elsewhere on the board
USB_HO_PX: J1.7 (HOST-D+); also elsewhere on the board
USB_HO_VBUS: J1.17 (DEBUG-0); also elsewhere on the board
VBUS: J4.21, J4.22, J4.23, J4.24, J4.25, J4.26; also elsewhere on the board

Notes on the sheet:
OreSat Proto-Card
3.1
All resistors 0402 +/- 1% unless marked
All caps are 0402 ceramic 10% X5R Vw>=16V unless marked
Main Connector
Main OreSat Card Connector
OreSat Power Domain signals (See power sheet)
HMM Octavo doesn't do SWD So, I might just leave these unconnected?
Oresat Debug Connector


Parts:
C32, C35: 1uF; .0805-B-NOSILK
C33: NP; .0603-A; MPN CL05B104KO5NNNC
C34, C37: 1uF; .0603-A
C36: 22uF; C1210
C38, C62: 10uF; .0805-B
C39: 0.1uF; .0603-A
D6: AMBER; LED-0603
D7, D8: GREEN; LED-0603
L1: 6.8u; ECS-MPI4040
Q2, Q4: PMV45EN; SOT23; MPN PMV45EN2R
Q3: DMP2240UDM; SOT23-6
Q5, Q6: MOSFET-PCH-SOT23-6; SOT23-6; MPN DMP3050LVT-7
R32, R34, R39, R46, R52, R64, R72: 10k; .0603-A
R33, R38, R40, R42, R51, R53, R54, R55, R56, R57, R58, R65, R66, R67, R68, R69, R70: NP; .0603-A; MPN RC1005F6653CS
R35, R43: 665k; .0603-A
R36, R44: 1M; .0603-A
R37, R45: 330k; .0603-A
R41, R48, R71: 100; .0603-A
R47, R50: 0; .0603-A
R49, R61, R62: 2.7k; .0603-A
R63: 100m; R1206
TP41, TP42, TP43, TP44, TP45, TP46, TP47, TP48, TP49, TP50, TP51, TP52, TP53, TP54, TP55, TP56, TP57, TP63, TP64, TP65, TP66, TP67, TP68: TEST-POINT; 2MM-TEST-POINT
U12, U13: MIC842LYC5; SC70-5
U14: MAX4211FETE; QFN65P400X400X80-17T210
U15: TPS62112; S-PVQFN-16
U16: MAX7310ATE; QFN65P400X400X80-17T210; MPN MAX7310ATE

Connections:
5V: C36.1, L1.2, R62.2, TP49.1, U15.10 (FB); also elsewhere on the board
!FAULT: Q2.3 (D), R32.1, TP45.1, U16.7 (IO2)
AD0: R57.1, R58.2, R69.2, R70.1, U16.1 (AD0)
AD1: R55.1, R56.2, R67.2, R68.1, U16.2 (AD1)
AD2: R53.1, R54.2, R65.2, R66.1, U16.3 (AD2)
BOOT0: TP51.1, U16.10 (IO5)
CB-RESET: R39.2, TP54.1, U14.9 (CIN2-), U16.9 (IO4)
CB_CTRL: Q2.1 (G), Q5.3 (G), R64.1, TP52.1, U14.3 (LE), U14.4 (COUT1), U14.6 (COUT2)
GND: C32.2, C34.2, C35.2, C36.2, C37.2, C38.2, C39.1, C62.2, D6.C, D7.C, D8.C, Q2.2 (S), Q4.2 (S), R33.1, R39.1, R40.1, R42.1, R46.1, R51.1, R54.1, R56.1, R58.1, U12.2 (GND), U13.2 (GND), U14.7 (GND), U14.EPAD (GND), U15.1 (GND), U15.6 (LBO), U15.7 (LBI), U15.9 (GND), U15.11 (GND), U15.12 (GND), U15.16 (GND), U15.PAD (GND), U16.6 (GND), U16.EPAD (GND); also elsewhere on the board
IOUT: R50.2, U14.14 (IOUT)
unnamed: C32.1, R36.1, R37.1, U12.1 (INP)
unnamed: R35.1, TP44.1, U12.4 (OUT)
unnamed: C62.1, Q6.1 (D), Q6.2 (D), Q6.5 (D), Q6.6 (D), R63.1, U14.16 (RS+)
unnamed: Q5.4 (S), R63.2, R64.2, U14.15 (RS-)
unnamed: C35.1, R44.1, R45.1, U13.1 (INP)
unnamed: Q3.3 (G), R43.2
unnamed: Q3.1 (G), R35.2
unnamed: TP56.1, U16.12 (IO7)
unnamed: D7.A, R61.1
unnamed: D8.A, R62.1
unnamed: TP53.1, U16.11 (IO6)
unnamed: Q3.5 (S), R48.2
unnamed: D6.A, R49.1
unnamed: Q3.2 (S), R41.2
unnamed: R43.1, TP43.1, U13.4 (OUT)
unnamed: R72.1, U16.13 (!RESET)
unnamed: Q4.3 (D), Q6.3 (G), R52.1
unnamed: R50.1, R51.2, TP57.1, U14.10 (CIN1+)
unnamed: R42.2, R47.1, TP47.1, U14.11 (CIN1-)
unnamed: R47.2, U14.8 (CIN2+), U14.12 (REF)
unnamed: C33.1, R33.2, R38.2
unnamed: R38.1, U14.5 (INHIBIT)
ON/!OFF: C34.1, Q4.1 (G), R46.2, R49.2, TP50.1, U14.1 (VCC), U16.8 (IO3)
OPD_PWR: R71.1; also elsewhere on the board
OPD_SCL: R48.1; also elsewhere on the board
OPD_SDA: R41.1; also elsewhere on the board
PB6/SCL: TP67.1, U16.4 (IO0)
PB7/SDA: TP68.1, U16.5 (IO1)
PEN-SCL-FILT: Q3.6 (D), R37.2, R65.1, R67.1, R69.1, TP42.1, TP66.1, U16.15 (SCL)
PEN-SDA-FILT: Q3.4 (D), R45.2, R66.2, R68.2, R70.2, TP41.1, TP65.1, U16.16 (SDA)
POUT: TP64.1, U14.13 (POUT)
TPS62111-PG: TP48.1, U15.13 (PG)
TPS62111-SYNC: R34.1, R40.2, TP46.1, U15.5 (SYNC)
TPS62111_SW: L1.1, U15.14 (SW), U15.15 (SW)
VBUS: Q6.4 (S), R52.2; also elsewhere on the board
VBUSP: C33.2, C37.1, C38.1, Q5.1 (D), Q5.2 (D), Q5.5 (D), Q5.6 (D), R34.2, R61.2, TP55.1, U15.2 (VIN), U15.3 (VIN), U15.4 (EN), U15.8 (VIN)
VPD: C39.2, R32.2, R36.2, R44.2, R53.2, R55.2, R57.2, R71.2, R72.2, TP63.1, U12.5 (VDD), U13.5 (VDD), U16.14 (V+)

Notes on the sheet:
0805
0603
ECS-MPI4040R4-6R8-R
5V Card Switching Supply
3.1
Main Power Switch
OreSat Power Enable (PEN)
Address selection for Card (See MAX7310 datasheet)
(3.3V)
Vbus = (6.0,7.2,8.4)V
OreSat Power Domain (OPD) Power Supply (3.3V)
OreSat Power Domain (OPD) Controller
Card Power Switch and Circuit Breaker
Note: Address 0b0111110x is reserved on all oresat cards



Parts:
C2, C8: 10uF; .0805-B
C3, C5, C6, C9, C10, C12: 1uF; .0603-A
C11, C31, C40: 0.1uF; .0603-A
D2, D3, D4, D5: BLUE; LED-0603
J3: CONN_03LONGPADS; 1X03_LONGPADS
J100: DM3BT-DSF-PEJS
JP2: PINHD-1X6; 1X06
JP105, JP106, JP107, JP108, JP109: JUMPER-SMT_3_1-NC_TRACE_SILK; SMT-JUMPER_3_1-NC_TRACE_SILK
R2, R3, R4, R5: 1k; .0603-A
R8, R9, R10: 10K; ARRAY_EXBA-M; MPN EXB-A10P103J
R24, R25, R26: 100K; ARRAY_EXBA-M; MPN EXB-A10P104J
R59, R60: DNP; .0603-A
TP12, TP13, TP16, TP17, TP18, TP19, TP22, TP23, TP24, TP26, TP30, TP32, TP35, TP40, TP69, TP70, TP100, TP101, TP103, TP104, TP105, TP106, TP107, TP108, TP111, TP114, TP115, TP117, TP118, TP120, TP122, TP123, TP124, TP125, TP126, TP127, TP128, TP131, TP134, TP135, TP137, TP142, TP146, TP147, TP148, TP149, TP152, TP153, TP158, TP159, TP162, TP174, TP177, TP178, TP180: TEST-POINT3X4; PAD.03X.04
U3: THGBMJG7C2LBAU8; BGA-153(11.5X13)(EMMC-BA); MPN THGBMJG7C2LBAU8
U7: OSD3358-512M-BSM; OSD335X-BGA-256
U11: TCAN330; SOT23-8_TI-DCN
U17: 25AAXX; SOIC8
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

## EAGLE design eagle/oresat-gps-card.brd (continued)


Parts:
C13, C14, C15: 22uF; C1210
C18, C41: 0.1uF; .0603-A
D1: GREEN; LED-0603
JP101, JP104: JUMPER-SMT_2_NC_TRACE_SILK; SMT-JUMPER_2_NC_TRACE_SILK
Q1: MMBT2907; SOT23-BEC
R1: 1k; .0603-A
R15, R28: 10k; .0603-A
R23: 499; .0603-A
R31: 40.2K; .0603-A
R73, R74, R75: 100; .0603-A
TP2, TP3, TP4, TP14, TP25, TP102, TP109, TP110, TP112, TP121, TP129, TP130, TP132, TP136, TP140, TP145, TP150, TP151, TP154, TP155, TP156, TP157, TP160, TP161, TP163, TP164, TP165, TP166, TP167, TP172, TP173: TEST-POINT3X4; PAD.03X.04
U4: SN74LVC1G07DCK; C70(TI-DCK)
U7: OSD3358-512M-BSM; OSD335X-BGA-256
U10: TLVH431; SOT23-3
U18: RCLAMP0504FB; SC70-6

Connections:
3.3V: R1.1, TP25.P$1, U7.F6 (SYS_VDD1_3P3V), U7.F7 (SYS_VDD1_3P3V), U7.G6 (SYS_VDD1_3P3V), U7.G7 (SYS_VDD1_3P3V); also elsewhere on the board
3.3VA: C41.1, JP101.1, TP165.P$1, U7.F8 (SYS_VDD3_3P3V), U7.F9 (VDDSHV4), U7.G8 (SYS_VDD3_3P3V), U7.G9 (VDDSHV5), U7.H7 (SYS_VDD3_3P3V), U7.H8 (SYS_VDD3_3P3V), U7.H9 (VDDSHV6), U7.J7 (SYS_VDD3_3P3V), U7.J8 (SYS_VDD3_3P3V), U7.J9 (VDDSHV1), U7.K8 (SYS_VDD3_3P3V), U7.K9 (VDDSHV2), U7.L8 (SYS_VDD3_3P3V), U7.L9 (VDDSHV3), U18.5 (VCC)
5V: C14.1, U7.P10 (VIN_AC), U7.R10 (VIN_AC), U7.T10 (VIN_AC); also elsewhere on the board
EEPROM_WP: R75.1, TP112.P$1, U18.6 (I4); also elsewhere on the board
GND: C13.2, C14.2, C15.2, C18.2, C41.2, D1.C, R15.1, U4.3 (GND), U7.D8 (DGND), U7.D9 (DGND), U7.E5 (DGND), U7.E6 (DGND), U7.E7 (DGND), U7.E8 (DGND), U7.E9 (DGND), U7.E10 (DGND), U7.E11 (DGND), U7.E12 (DGND), U7.F5 (DGND), U7.F12 (DGND), U7.G5 (DGND), U7.G12 (DGND), U7.H4 (DGND), U7.H5 (DGND), U7.H12 (DGND), U7.H13 (DGND), U7.J4 (DGND), U7.J5 (DGND), U7.J12 (DGND), U7.J13 (DGND), U7.K5 (DGND), U7.K12 (DGND), U7.L5 (DGND), U7.L12 (DGND), U7.M5 (DGND), U7.M6 (DGND), U7.M7 (DGND), U7.M8 (DGND), U7.M9 (DGND), U7.M10 (DGND), U7.M11 (DGND), U7.M12 (DGND), U7.N8 (DGND), U7.N9 (DGND), U18.2 (GND); also elsewhere on the board
I2C0_SCL: R73.1, TP155.P$1, U18.3 (I2); also elsewhere on the board
I2C0_SDA: R74.1, TP151.P$1, U18.1 (I1); also elsewhere on the board
unnamed: JP101.2, Q1.E, R23.2, R28.2
unnamed: R28.1, R31.2, U10.1 (REF)
unnamed: Q1.B, R23.1, U10.2 (CATHODE)
unnamed: TP172.P$1, U7.D12 (NC)
unnamed: TP150.P$1, U7.J6 (NC)
unnamed: TP145.P$1, U7.K4 (NC)
unnamed: TP157.P$1, U7.H6 (VPP)
unnamed: TP173.P$1, U7.D5 (CAP_VDD_RTC)
unnamed: TP166.P$1, U7.G13 (VDDS_PLL)
unnamed: TP160.P$1, U7.F13 (VDD_MPU)
unnamed: TP154.P$1, U7.G4 (VDD_CORE)
unnamed: TP156.P$1, U7.F4 (VDDS_DDR)
unnamed: D1.A, R1.2
unnamed: R74.2, U7.C11 (I2C0_SDA), U7.D11 (PMIC_SDA)
unnamed: R75.2, U7.M2 (EEPROM_WP)
unnamed: R73.2, U7.C10 (I2C0_SCL), U7.D10 (PMIC_SCL)
unnamed: C18.1, JP104.1, TP14.P$1, TP164.P$1, U4.5 (VCC), U7.K11 (SYS_RTC_1P8V), U7.L11 (SYS_RTC_1P8V)
unnamed: TP4.P$1, TP130.P$1, U7.N7 (PMIC_BAT_SENSE), U7.P8 (VIN_BAT), U7.R8 (VIN_BAT), U7.T8 (VIN_BAT)
unnamed: TP129.P$1, U7.N6 (PMIC_TS)
unnamed: TP161.P$1, U7.F11 (SYS_VDD2_3P3V), U7.G11 (SYS_VDD2_3P3V)
unnamed: JP104.2, Q1.C, R31.1, U10.3 (ANODE)
unnamed: TP163.P$1, U7.F10 (SYS_VDD_1P8V), U7.G10 (SYS_VDD_1P8V), U7.H10 (SYS_VDD_1P8V), U7.H11 (SYS_VDD_1P8V), U7.J10 (SYS_VDD_1P8V), U7.J11 (SYS_VDD_1P8V), U7.K10 (SYS_VDD_1P8V), U7.L10 (SYS_VDD_1P8V)
unnamed: TP167.P$1, U7.D4 (EXTINTN), U7.E4 (PMIC_NINT)
unnamed: TP140.P$1, U7.L4 (PMIC_NWAKEUP), U7.M4 (EXT_WAKEUP)
unnamed: TP132.P$1, U7.N4 (PMIC_LDO_PGOOD), U7.N5 (RTC_PWRONRSTN)
unnamed: TP121.P$1, U7.N10 (PMIC_POWER_EN), U7.N11 (PMIC_PWR_EN)
unnamed: TP102.P$1, U7.T11 (PMIC_PB_IN)
unnamed: TP136.P$1, U7.M13 (PMIC_NRESET)
unnamed: R15.2, U7.M16 (RTC_KALDO_ENN)
PMIC_PGOOD: TP110.P$1, U4.2 (A), U7.N12 (PMIC_PGOOD), U7.P11 (PWRONRSTN)
RESET#: TP109.P$1, U4.4 (Y), U7.R11 (WARMRSTN); also elsewhere on the board
VDD: C15.1, TP3.P$1, U7.K6 (SYS_VOUT), U7.K7 (SYS_VOUT), U7.L6 (SYS_VOUT), U7.L7 (SYS_VOUT); also elsewhere on the board
VIN_USB: C13.1, TP2.P$1, U7.P9 (VIN_USB), U7.R9 (VIN_USB), U7.T9 (VIN_USB); also elsewhere on the board

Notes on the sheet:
SYS_VOUT is where system 5V power originates, 500mA max. This will always be 5V as long as VIN_AC or VIN_USB are used at 5V. However, if VIN_BAT is used with non-5V input, this will reflect that voltage. VIN_BAT will probably be used from the oresat power circuit, so we need to prepare for this cas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
SYS_VDD1_3P3V is where system 3.3V power originates, 500mA max,
PWR LED
PMIC_PGOOD drives PWRONRSTN and WARMRSTN when the power supplies are ready. Because of different voltage levels, an open-drain buffer is required.
PWR from USB client circuit
Jumper to disconnect octavo from OPD power


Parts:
C47, C48, C49, C59, C67, C68: 1u; .0603-B-NOSILK
C50, C60, C69: 10n; .0603-B-NOSILK
C55, C56, C65, C70: 100n; .0603-B-NOSILK
C81: 56p; .0402-C-NOSILK
R30, R79: 10k; .0603-B-NOSILK
R77: 10k; 0402-C-NOSILK@1
SH1: BMI-S-202-SHIELD; BMI-S-202; MPN BMI-S-202-C
TP5, TP11, TP15: TEST-POINT15MIL-TEST-POINT; 15MIL-TEST-POINT
U5: SKY65723-81; MPN SKY65723-81
U8, U9, U20: MAX8510EXK29+T; SC70; MPN MAX8510EXK29+T
U19: BP2G+; MINICIRCUITS

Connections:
2.85V-S: C68.1, C69.1, C70.1, TP11.P$1, U20.5 (OUT); also elsewhere on the board
2.85VA: C49.1, C50.1, C55.1, C56.1, C81.1, R77.1, TP15.P$1, U5.1 (VCC), U9.5 (OUT); also elsewhere on the board
2.85VD: C59.1, C60.1, C65.1, TP5.P$1, U8.5 (OUT); also elsewhere on the board
3.3V: C47.1, C48.1, C67.1, U8.1 (IN), U9.1 (IN), U20.1 (IN); also elsewhere on the board
GND: C47.2, C48.2, C49.2, C55.2, C56.2, C59.2, C65.2, C67.2, C68.2, C70.2, C81.2, R30.1, R79.1, SH1.P$1, SH1.P$2, SH1.P$3, SH1.P$4, SH1.P$5, SH1.P$6, SH1.P$7, SH1.P$8, SH1.P$9, SH1.P$10, SH1.P$11, SH1.P$12, U5.GND, U8.2 (GND), U9.2 (GND), U19.1 (GND), U19.3 (GND), U19.4 (GND), U19.6 (GND), U19.7 (GND), U20.2 (GND); also elsewhere on the board
MAX-EN: R30.2, U8.3 (EN), U9.3 (EN); also elsewhere on the board
MAX-RF: U19.5 (PORT2); also elsewhere on the board
unnamed: U5.6 (RF_OUT), U19.2 (SUM)
unnamed: R77.2, U5.2 (VEN)
unnamed: C50.2, U9.4 (BP)
unnamed: C60.2, U8.4 (BP)
unnamed: C69.2, U20.4 (BP)
RF-IN: U5.3 (RF_IN); also elsewhere on the board
STQ-EN: R79.2, U20.3 (EN); also elsewhere on the board
STQ-RF: U19.8 (PORT1); also elsewhere on the board

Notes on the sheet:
Soldered down RF shield with cap
Mini-Circuits L band Splitter
GPS LNA
RF front end
2.85V digital supply for MAX2771
2.85V For SkyTraq supply
2.85V analog supply for MAX2771
Low noise LDO supplies for RF ICs

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

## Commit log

2019-03-20 Moving the GPS USB front end board from PSAS repo.
    [Digikey_order.csv, MAX_2769.sch, USB_FT2232.sch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]
2019-07-18 Fix 3.3V LDO inhibit polarity.
    [MAX_2769.sch, USB_FT2232.sch, usb_gps.csv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]
2019-07-18 Fix footprint for MAX 8510 (two places).
    [MAX_2769.sch, usb_gps.kicad_pcb]
2019-07-20 Change out micro-usb connector to one with thru holes.
    [USB_FT2232.sch, usb_gps.kicad_pcb]
2019-07-20 Change out SMA connector for thru-hole version.
    [MAX_2769.sch, usb_gps.kicad_pcb]
2019-07-22 Add back mounting holes, rev. front silk.
    [usb_gps.kicad_pcb]
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2019-07-26 Update to MAX2771. Changes to decoupling caps, Remove ANTFLAG, IDLE signals. Add explicit antenna bias. New matching network for LNA input. Remove bypass for SAW filter.
    [MAX_2769.sch, USB_FT2232.sch, usb_gps.sch]
2019-07-27 Add some footprints, annotate new parts, generate netlist, EDR check.
    [MAX_2769.sch, USB_FT2232.sch]
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2019-07-28 Changed 2.2uF to 10uF. Completed routing. Added via fencing and footprint vias.
    [MAX_2769.sch, usb_gps.dsn, usb_gps.kicad_pcb]
2019-07-28 Final cleanup before submit to OSHPARK.
    [MAX_2769.sch, usb_gps.kicad_pcb]
2019-08-02 Fix value display on EEPROM. Consolidate some part values.
    [MAX_2769.sch, USB_FT2232.sch, boms_away.csv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]
2019-09-15 as sent to OSHPARK
    [MAX_2769.sch, USB_FT2232.sch, usb_gps.kicad_pcb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]
2019-10-30 Add more decoupling caps to 2232H.
    [MAX_2769.sch, USB_FT2232.sch, usb_gps.sch]
2019-10-30 Run DRC, generate and import netlist w/ new caps.
    [MAX_2769.sch, USB_FT2232.sch, usb_gps.kicad_pcb]
2019-11-01 Partially laid out; ready to move some parts.
    [USB_FT2232.sch, usb_gps.kicad_pcb]
2019-11-01 Moved optional Maxim clk fix circuit to FTDI side.
    [MAX_2769.sch, USB_FT2232.sch]
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2019-11-01 Plotted gerbers. Fixed crystal load caps, added LED, added stitching.
    [MAX_2769.sch, USB_FT2232.sch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]
2019-11-02 Change SMA footprint, add SAW filter, extend header pins.
    [MAX_2769.sch, usb_gps.sch]
2019-11-03 Add signals to header.
    [MAX_2769.sch, USB_FT2232.sch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]
2019-11-13 Add LED P/N. Process BOM prior to order.
    [MAX_2769.sch, USB_FT2232.sch, gps_usb_v3_bom.csv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]
2019-11-17 Add in Microsemi A3P250 development board. Layout almost completed.
    [1.5V_switcher_test.kicad_pcb, A3P250_Dev_Board.kicad_pcb, A3P250_Dev_Board.sch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]
2019-11-17 Routed, fixed labels, added test points.
    [A3P250_Dev_Board.kicad_pcb, UnitA.sch, UnitB.sch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]
2019-12-01 Add solder paste layer.
    [A3P250_Dev_Board-B.Cu.gbr, A3P250_Dev_Board-B.Mask.gbr, A3P250_Dev_Board-Edge.Cuts.gbr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]
2020-09-27 Added cobbled together star tracker + rocket SDR GPS receiver
    [oresat-gps-card.brd, oresat-gps-card.sch]
2021-01-24 GPS card has been mostly layed out. Still missing a few things, but nothing major.
    [oresat-gps-card.brd, oresat-gps-card.sch]
2021-01-24 Added some polygons to the power plane
    [oresat-gps-card.brd]
2021-02-01 Finished laying out Venus receiver. Fixed issue with GND and AGND planes. Added vias, and restrict lines to separate digital and RF ground planes. Added enable lines to Max and Venus receivers. Updat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
    [oresat-gps-card.brd, oresat-gps-card.sch]
2021-02-01 Fixed a note in the schematic
    [oresat-gps-card.sch]
2021-02-03 Updated boot circuitry. Cleaned up names layer.
    [oresat-gps-card.brd, oresat-gps-card.sch]
2021-02-06 Moved some silk screen items out of the way of pads
    [oresat-gps-card.brd]
2021-02-08 Fixed design review things: made net names more clear, removed solder mask from top of RF traces, opened up space around octavo 3.3v pads, moved digital LDO for the max chip, added pin header and thr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
    [oresat-gps-card.brd, oresat-gps-card.sch]
2021-02-20 Fixed 3.3VA rail for I2C protection chip.
    [oresat-gps-card.brd, oresat-gps-card.sch]
2021-02-28 Added attributes to some parts, and changed internal cutout polygons to 0.1 width instead of 0 width.
    [oresat-gps-card.brd, oresat-gps-card.sch]
2021-03-01 Updated oscillator capacitor values and added BOM
    [oresat-gps-card.brd, oresat-gps-card.sch, oresat-gps-card.xlsx]
2021-03-08 OK'd ERC errors.
    [oresat-gps-card.brd, oresat-gps-card.sch]
2021-03-25 Updated BOM after stuffing v1.0: added shield, a 1uF was accidentally marked as 0.1 uF, and since the supercap is DNP, stuff the diode and resistor associated with 0 ohm 0603 resistors.
    [oresat-gps-card.xlsx]
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2022-08-02 Moved old EAGLE files to separate folder
    [oresat-gps-card.brd, oresat-gps-card.sch, oresat-gps-card.xlsx]
2022-10-02 GPS card is in KiCad now
    [connectors.kicad_sch, max2771.kicad_sch, oresat-gps-card.kicad_sch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]
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2023-01-22 GPS card design review changes and issue fixes
    [connectors.kicad_sch, max2771.kicad_sch, oresat-gps-card.kicad_sch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]
2023-01-22 Changed GPS card schematic sheet naming convention
    [oresat-gps-card-sch-connectors.kicad_sch, oresat-gps-card-sch-max2771.kicad_sch, oresat-gps-card-sch-osd3358-power.kicad_sch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]
2023-01-22 Updated schematic sheet links to match new naming
    [oresat-gps-card-sch-connectors.kicad_sch, oresat-gps-card-sch-max2771.kicad_sch, oresat-gps-card-sch-osd3358-power.kicad_sch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]
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2023-07-20 Updated GPS card with changes from C3 and notes. Fixed library issues
    [oresat-gps-card-sch-connectors.kicad_sch, oresat-gps-card-sch-max2771.kicad_sch, oresat-gps-card-sch-osd3358-power.kicad_sch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]
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2024-01-02 Update RF path for sunstone board run, and connected VPD diodes
    [oresat-gps-card-sch-osd3358-power.kicad_sch, oresat-gps-card-sch-osd3358-sd-emmc.kicad_sch, oresat-gps-card-sch-power.kicad_sch]
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2024-01-02 Cleaned up ERC and DRC errors on GPS card
    [oresat-gps-card-sch-connectors.kicad_sch, oresat-gps-card-sch-max2771.kicad_sch, oresat-gps-card-sch-osd3358-power.kicad_sch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]
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2024-05-25 Updated KiCAD 8, updated schematic sheet info, polished some schematic things, and made DNP parts DNP.
    [MAX2771ETI_.step, clock.kicad_pcb, clock.kicad_sch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]
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2026-06-24 Routine Push
    Andrew should look at the MAX2769 change.
    [oresat-gps-card-sch-connectors.kicad_sch, oresat-gps-card-sch-max2771.kicad_sch, oresat-gps-card-sch-power.kicad_sch]
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2026-06-26 Routine Push
    First attempt to clean up schematic
    [oresat-gps-card-sch-connectors.kicad_sch, oresat-gps-card-sch-max2771.kicad_sch, oresat-gps-card-sch-osd3358-power.kicad_sch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]
2026-06-27 Routine Push
    Schematic finished. Components laid out, chasing ERCs.
    [oresat-gps-card-sch-max2771.kicad_sch, oresat-gps-card-sch-osd3358-power.kicad_sch, oresat-gps-card-sch-osd3358-sd-emmc.kicad_sch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]
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2026-06-29 General cleanup of schematic and layout
    Updated .gitignore, updates DRU file, moved RF lines to RF-50-MIN (max is just too big),
    lots of cleanup on the root page to make it pretty, cleaned up some redudant labels,
    updated SMPM connector and added rule zone, updated PCB outline to include NPTH drills
    for SMPM connectors, began cleanup of OPD.
    [MAX2771ETI_.step, clock.kicad_pcb, clock.kicad_sch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]
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2026-07-02 Review Push
    Still several line items to fix
    [oresat-gps-card-sch-power.kicad_sch]
2026-07-06 ERC and DRC cleaneup
    Fixed symbols, fixed footprints, changed DRC rules to reduce errors,
    updated footprints, mostly done.
    [oresat-gps-card-sch-max2771.kicad_sch, oresat-gps-card-sch-osd3358-power.kicad_sch, oresat-gps-card-sch-osd3358-sd-emmc.kicad_sch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]
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2026-07-07 Last of the GPS card cleanup
    Better plains in the RF section, lots of shortening and straitening, cleaned up all ERC and DRCs.
    [oresat-gps-card-sch-max2771.kicad_sch, oresat-gps-card-sch-osd3358-power.kicad_sch, oresat-gps-card-sch-osd3358-sd-emmc.kicad_sch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]
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2026-07-10 Large BOM changes for v1.2, no changes to PCB
    [oresat-gps-card-sch-max2771.kicad_sch, oresat-gps-card-sch-osd3358-power.kicad_sch, oresat-gps-card-sch-osd3358-sd-emmc.kicad_sch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]
2026-07-14 Updated Layout
    Changes to BOM. Changes to footprint assignments.
    [oresat-gps-card-sch-max2771.kicad_sch, oresat-gps-card-sch-power.kicad_sch, oresat-gps-card-sch-rf-power.kicad_sch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]
2026-09-17 Upped to v1.3.
    Fixed backward EEPROM programming pin, fixed potential boot error with missing PMIC connections, fixed some power domain issues.
    [oresat-gps-card-sch-max2771.kicad_sch, oresat-gps-card-sch-osd3358-power.kicad_sch, oresat-gps-card-sch-osd3358-sd-emmc.kicad_sch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]
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2026-10-04 Fixed boot issue, updated date, updated version, ready for a final polish
    [oresat-gps-card-sch-max2771.kicad_sch, oresat-gps-card-sch-osd3358-power.kicad_sch, oresat-gps-card-sch-osd3358-sd-emmc.kicad_sch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]
2026-10-08 schematic and layout changes
    OPD soft start update. Review of board layout.
    [oresat-gps-card-sch-power.kicad_sch, oresat-gps-card.kicad_pcb]
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

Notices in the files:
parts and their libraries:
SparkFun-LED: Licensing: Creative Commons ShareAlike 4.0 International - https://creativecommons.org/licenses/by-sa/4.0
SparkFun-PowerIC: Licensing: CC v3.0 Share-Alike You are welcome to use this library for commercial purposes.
